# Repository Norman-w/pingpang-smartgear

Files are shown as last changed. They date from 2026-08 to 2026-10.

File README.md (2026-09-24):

# 乒乓智配 · PingPang SmartGear

乒乓球训练与比赛相关的智能辅助装备、配件及识别系统。

## 裸激光可调夹座首样

新增左侧十路裸激光方案：每颗光头装入独立球面夹筒，以两颗斜向螺钉微调，整排沿用原球头粗调。调整时从头套编号孔进入，邻近光头和盖件保持安装；预览页提供[原位调节演示与夹座特写](hardware/cad/preview/?view=laser)。尺寸暂按 Ø6×12 mm，实体适配和光路精度待实测。

设计、装配和独立 STL 包见[小夹座说明](docs/laser-micro-mount-v0.1.zh-CN.md)。前盖已加深、加宽并恢复完整弧形侧壁；新前后盖、承载条、底盖及底部柔性垫配套使用。预览支持围绕鼠标缩放和各倍率下平移。下文原 M6 电子与打印资料保留作参考，不表示其电路已经适配裸激光。

[接收端配套外壳](docs/receiver-mount-v0.1.zh-CN.md)也已同步扩大，提供独立五件打印包和右侧特写；内部接收元件选择尚未确认。

## 当前项目

当前机械主线是一套免打孔的内置式球网支架：左右夹体固定在球台边缘，网布直接装入两侧立柱，网端附近各有一个 PVDF 振动传感器；左右各十路 M6 发射/接收器件用于过网高度/事件采集，电子系统由 ESP32-S3 主控和独立 M6 接收载板组成。

当前阶段已经完成：

- OpenSCAD 统一机械参数源、完整装配、爆炸和真实截面诊断；
- C 形夹按 y=0 分型为两半；承载发射/接收头的斜立柱另分为下段和顶部 `30 mm` 上段，分型处用公母定位键和四枚 M3×40 连接；网布侧边使用独立圆柱插杆，不再使用外侧矩形网夹；立柱从黄灰交界 `z=16 mm` 延伸至 `z=260.5 mm`，不向下插入 C 形座；网布/圆柱插杆功能区仍为 `z=16…168.5 mm`；
- 网布的 `3 mm` 过道，以及球网空心边套和 `Ø10 mm` 圆柱插杆；插杆先穿过网布边套，再沿原门洞轴线从 x 侧推入下段侧开接收腔，门洞宽度保持历史 `15.2 mm`，立柱分型位于顶部下 `30 mm`，网顶不设置轨道；
- ESP32 主控、电池、电源保护、接收/发射/UI 子板的 KiCad/Atopile 交接包；
- 板框、安装孔、梯形腔、y+ 一体式 UI 填平固定板和电子件的统一 fit report；
- 当前 `41` 个正式机械 STL，以及 `256 mm` 打印床 `7` 张板、`41` 件、`0` 件超尺寸的几何拼盘；斜立柱下段/绿色载体采用实际三轴斜放，上段按平放姿态打印。

仍未由文件替代的工作包括：PCB 铜箔/器件生产释放和电气波形、真实网布与 M6 SKU 实测、立柱与 C 夹的打印配合及 PETG 承力、盒盖实际贴合、切片/G-code、首层和实物装配联调。

网端安装规则：先把球网侧边空心布套套到一根 `Ø10 mm × 152.5 mm` 圆柱插杆上，再沿原门洞轴线从 x 侧推入下段侧开接收腔，最后安装上段把插杆封在立柱内；拆卸按相反顺序进行。固定 C 夹两半除网布过道外保持实心，立柱底面与 `z=16 mm` 黄灰交界共面，分型在顶部下 `30 mm`，上段与下段用公母键和四枚 M3×40 连接；下段从承托面起做 `35×58 mm → 28×38 mm` 连续实心渐变，以上保持 `28×38 mm`。

这里的“齐平”仅表示一体式 UI 填平固定板和 M6 盖件装配后没有明显错台或松动，不宣称 IP 防水等级。

## 仓库结构

```text
docs/       需求、技术方案、测量定义和测试记录
hardware/   机械 CAD、电子板、BOM、打印和装配资料
firmware/   设备控制器、传感器采集和通信固件
vision/     球体检测、轨迹估计、过网高度计算
software/   标定工具、调试界面和训练/比赛数据接口
```

## 入口文档

- [硬件工程说明](hardware/README.md)
- [OpenSCAD 机械主线](hardware/cad/README.md)
- [打印清单](hardware/cad/print-manifest.zh-CN.md)
- [ESP32 主控与 1S 电源首样板](hardware/electronics/esp32-control-v0.1/README.zh-CN.md)
- [统一电子系统干涉/打印自证报告](hardware/electronics/fit-report-v0.2.md)
- [Atopile 系统接口合同](hardware/electronics/atopile/README.zh-CN.md)
- [系统机械—电气接口合同](hardware/electronics/system-packaging-v0.2.zh-CN.md)
- [M6 阵列设计说明](docs/m6-optical-array-design-v0.1.zh-CN.md)
- [首样采购与装配清单](hardware/first-article-bom.zh-CN.md)

## 设计原则

1. 先建立可测量、可追溯的机械和高度基准。
2. 机械、电子和识别链路分层，任何一层未实测时保持 `pending/unknown`。
3. 以装配、干涉、通道数量和实物波形共同放行，不以“能编译”代替接板通过。
4. 所有打印包必须能追溯到参数源、清单、包围盒和封闭拓扑摘要。

本项目当前面向训练、实验和产品研发；未经重复性、环境适应性和规则符合性验证的版本，不作为正式比赛裁判依据。

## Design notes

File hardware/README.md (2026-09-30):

# 硬件工程

这里放置内置式球网支架、两侧 M6 发射/接收阵列、网端 PVDF 传感器、ESP32 主控、子板、电池和装配资料。

新增的左侧裸激光可调小夹座见[结构与装配说明](../docs/laser-micro-mount-v0.1.zh-CN.md)。单颗特写、原位调节演示与整排共用 SCAD 导出的模型，工具从编号孔进入，邻居和后盖保持固定。输出位于 `cad/exports/laser-micro-mount-v0.1/`；加大前腔的新前盖、新承载条、后盖、底盖与底部柔性垫成套使用，原 M6 电气资料仅供接口参考。

右侧也已同步[接收端外壳](../docs/receiver-mount-v0.1.zh-CN.md)，输出为 `cad/exports/receiver-mount-v0.1/`；内部元件仍为原M6接口参考，待确认接收器后适配固定座。

## 当前硬件拆分

- [`cad/`](cad/)：参数化 OpenSCAD 机械源、完整装配/爆炸/剖切预览、正式 STL 导出和 256 mm 打印拼盘；
- [`electronics/`](electronics/)：ESP32-S3 主控板、M6 接收载板、发射端内置电源子板、UI 子板、Atopile 接口合同、3D 板模型和统一壳内干涉报告；
- [`first-article-bom.zh-CN.md`](first-article-bom.zh-CN.md)：首样采购和实物放行边界；
- [`../docs/m6-optical-array-design-v0.1.zh-CN.md`](../docs/m6-optical-array-design-v0.1.zh-CN.md)：M6 阵列和安装基准。

电子系统的机械—电气合同见 [`electronics/system-packaging-v0.2.zh-CN.md`](electronics/system-packaging-v0.2.zh-CN.md)。其中已给出母板、接收/发射/UI 子板、端子化线束、电池仓、USB-C、按钮、屏幕预留、扬声器/蜂鸣器、指示灯和梯形腔的统一坐标。主控与 1S 电源首样板见 [`electronics/esp32-control-v0.1/`](electronics/esp32-control-v0.1/)，M6 接收载板和发射端电源子板见 [`electronics/daughter-boards-v0.2/`](electronics/daughter-boards-v0.2/)。

## 当前机械结构

网顶不设置轨道。网布侧边空心布套先套到 `Ø10 mm × 152.5 mm` 圆柱插杆，再把这套组件从球台中心侧穿过立柱下段的连续 `3 mm` 网布过道，沿原门洞轴线从 x 侧推入下段的侧开接收腔；安装上段后封住插入口。斜立柱在顶部下 `30 mm` 分成下段和可替换上段，两段用公母定位键和四枚 M3×40 自攻钉连接。网端附近左右各一个 PVDF 振动传感器，与网架保留 `18 mm` 横向净距。

C 形夹按 y=0 分型为 `clamp_body_half_user` 与 `clamp_body_half_opponent` 两半，斜立柱和绿色载体则由 `post_clamp_carrier_lower`、`post_clamp_carrier_upper` 两件打印；固定夹半体除网布 `3 mm` 过道和侧开接收腔外保持实心。立柱底面在 C 夹黄灰交界 `z=16 mm` 共面，分型位于顶部下 `30 mm`，上段带公母键、四枚 M3×40 连接孔和中心 M8×1.25 攻丝座；网布/圆柱插杆功能区仍只到 `z=168.5 mm`。网端装配不使用矩形卡夹、keeper 或竖直盲孔：先把边套套在 Ø10 圆柱上，再沿 x 方向推入下段侧开接收腔，最后合上上段。球头下端直接拧入上段中心座，四枚立柱连接螺丝只属于立柱上下段。

盒盖、压合边和接口以“装配后严丝合缝、无明显贯穿缝”为目标；这里不宣称防水等级。真实网布、螺纹、张力、线缆弯曲和夹体耐久必须用首样实测。

## 打印状态

当前正式机械包以 [`cad/print-manifest.zh-CN.md`](cad/print-manifest.zh-CN.md) 和 [`cad/exports/desktop-clamp-one-side-x1c-v0.7-split-c-scheme/manifest.json`](cad/exports/desktop-clamp-one-side-x1c-v0.7-split-c-scheme/manifest.json) 为准：`41` 个 STL。256 mm 打印床拼盘见 [`cad/exports/desktop-clamp-one-side-x1c-v0.7-split-c-scheme/print-platter-256/manifest.json`](cad/exports/desktop-clamp-one-side-x1c-v0.7-split-c-scheme/print-platter-256/manifest.json)：`7` 张板、`41` 个已排版、`0` 个超尺寸件；斜立柱下段/绿色载体使用实际三轴斜放，上段按分型面平放姿态打印。旧整高 C 夹、电子腔底盖/连续垫、网夹分体、套筒和内芯不再属于当前清单；旧矩形卡条与 keeper 已移除，当前为独立 Ø10 mm 圆柱插杆和下段侧开接收腔。

立柱上下段连接螺丝当前按普通盘头或低矮圆头 `M3×40` 自攻钉采购；结构没有 90° 沉头窝，也不使用台阶肩螺丝。这是 CAD 包络/封闭 STL/排版证据，不是已切片、已生成 G-code 或已完成实物打印的证明。

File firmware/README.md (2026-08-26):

# 固件工程

这是 ESP32-S3 的业务固件骨架，专注于网顶擦网与过网高度事件，不在本仓库复制外部 SmartPaddle/目标 App 的配网、连接管理和多设备基础设施。

## 业务链路

```text
10 路 M6 NPN 光电 GPIO/中断 ─┐
                    ├─ NetEventAggregator ── NetEvent v0.1 ── WebSocket 适配点
2 路 PVDF comparator ─┘          │
                                 ├─ RGB/蜂鸣器适配点
                                 └─ RAM RingBuffer 断链缓存
```

`piezo_waveform.*` 保存每路 16 kHz、20 ms 预触发和 80 ms 后触发的双通道短波形，并在波形完成后计算峰值、能量和持续时间；ADC 流超时或冷启动时预触发历史不足会释放/保留相应帧，但让事件带 `waveform_incomplete`，不把零填充历史当作有效基线；主循环先消费比较器边沿再派发 ADC DMA，时间戳早于触发点的 backlog 样本会回填当前帧的预触发尾部；空引用不会启动可回放帧，乱序帧入队后会清空滚动历史，防止坏样本污染下一事件；GPIO 队列溢出等输入边界失败调用 `abort()` 时，当前帧和尚未交给业务层的 ready 帧都会丢弃，避免跨边界波形被归档。`piezo_waveform_archive.*` 保留最近若干帧，`waveform_ref` 不再是无目标的占位字符串。`piezo_adc_continuous.*` 已提供 ADC1 continuous/DMA 适配，并保留与目标 SmartPaddle/ESP-IDF 5.5.x 原始结果格式的适配边界，同时兼容 ESP-IDF 6.x 的解析接口；配置会拒绝重复 ADC 通道、无效帧大小和超过读取缓冲区的帧；目标 PCB 的最终引脚表和 AFE 输出范围仍需实机确认。

## 构建与测试

- ESP32-S3：在 ESP-IDF 环境中从 `firmware/` 运行 `idf.py build`；
- 主机业务测试：运行 `python3 host-tests/run_tests.py`；
- 主机测试依赖：在 `firmware/` 下运行 `python3 -m pip install -r host-tests/requirements.txt`；GitHub Actions 会自动执行主机、CTest、Python/Schema、预览、OpenSCAD 和 ESP32-S3/ESP-IDF 5.5.1 验证；
- `m6_carrier_protocol_tests` 额外验证载板帧的 CRC/长度/分片/序号/时钟偏移/FIFO 边界、`CLOCK_SYNC_REQUEST/RESPONSE` 两事务 t2/t3、至少三次低延迟稳定样本的运行时校准门、换 offset 时清空旧边界、载板 SPI 从机 TX 预装/IRQ-CS 生命周期、短事务 fail-closed、10 路同时双边沿的 20-edge 分帧以及原始电平进入 `BeamCapture` 的适配；它不替代载板 SPI 电气波形和实物短脉冲测试；
- 主机测试覆盖光栅位图/安静结束/超时/乱序/反向时间边界保护、PVDF 双通道归并、完整与不完整波形特征/归档/非有限值保护、窗口外 DMA backlog 丢弃、比较器先到后由 DMA 完成波形并归并为 `touch_over` 的顺序路径、输入边界失败时清空 ready 波形、传感器健康快照质量门、健康快照在待决事件期间变化时的 fail-closed 处理、聚合器对空校准 ID/越界健康位图和坏边界的 fail-closed 处理、GPIO 队列溢出、四种事件状态、端到端传感器归并、完整事件进入断链 RAM 缓存并恢复补发、传输恢复、JSON Schema 和 CSV 轨迹回放；ESP32 任务侧在队列溢出后会清空旧边沿，再等待新输入建立边界。

参考平级 checkout `../SmartPaddle` 的 `firmware/main/ws_data_server.h` 提供 `ws_data_has_client()` / `ws_data_send_text()`；`smartpaddle_ws_transport_adapter.cpp` 在定义 `SMARTGEAR_SMARTPADDLE_WS`、加入 SmartPaddle 的 include path 并链接其完整网络 component 后提供两个强 hook，默认构建仍保留弱 hook，因此不会把未链接的网络服务误报成已连接。这个适配器只完成代码边界，不代表两个工程已经合并或实机联调。

针对 SmartPaddle GPIO 冲突，`m6_carrier_protocol.*`、`m6_carrier_adapter.*` 和 `m6_carrier_spi.*` 已在 host 测试及现有 ESP-IDF v5.5.1 配置的 CMake build 中通过载板帧解码、ESP32-S3 SPI master/IRQ 读取、运行时四时间戳校准门和 `BeamCapture` 边界适配验证；`sensor_board_hooks.*` 的 `smartgear_board_read_m6_carrier_clock_sync()` 是板级同步事务注入口；`carrier/m6_carrier_capture_core.*` 与 `carrier/m6_carrier_spi_slave_transport.*` 提供 MCU 无关的载板 FIFO、TX 预装和 IRQ/CS 事务边界。`carrier_config::kUseM6Carrier` 默认关闭；载板 MCU 固件、PCB/光耦实物、实机时钟同步和 SPI/IRQ 波形仍需接板放行，未确认时主循环会清空边界并保持 `unknown`，不会伪造有效高度事件。

`carrier/esp32s3-reference/` 是一个独立的 ESP32-S3 载板平台参考工程，可在 ESP-IDF 5.5.1 下编译验证 10 路 GPIO ISR、SPI slave DMA、IRQ/RESET 和协议核心；它不等于最终生产 MCU 或 PCB。

`sensor_board_hooks.h` 的健康快照 hook 用于注入校准 ID、10 路光栅健康位图和 PVDF 安静基线，`sensor_health_gate.*` 负责把同一份快照以可测试的 fail-closed 规则写入聚合器；在 M6 SKU、NPN 常开/常闭极性、隔离前端和逐路自检未确认前，`net_sensor_config.h` 的 `kBeamPolarityConfirmed=false` 还会在主循环入口拒绝健康快照；`piezo_waveform_hook.h` 可把完整/不完整原始帧同步复制到目标回放存储。健康 hook 未实现、返回失败或快照形状非法时固件保持 `unknown`，不生成未经验证的有效事件；波形 hook 未实现时仍保留本地 RAM 归档。

载板工程候选的无 HAL 端口外壳见 [`carrier/stm32g031-reference/`](carrier/stm32g031-reference/)。它验证 `STM32G031K8U6/UFQFPN32` pin map、EXTI → 1 µs 定时器、SPI1 mode 0/152-byte TX staging、IRQ/CS 和复位生命周期；目录提供依赖 ST 官方 CMSIS device/core 与 ARM 工具链的寄存器级 object compile-only 绑定，以及可选的最小 STM32G031 参考 ELF/bin 构建。参考镜像已在本机链接并导出，但真实 PCB、DMA/ISR 波形、CS glue、烧录上电和接板验收仍保持 pending。

硬件 GPIO 映射在 `main/net_sensor_config.h` 中明确标为首轮占位，不能在最终 PCB 未复核前视为量产引脚表。`kBeamLogicalIndexByInput` 把原始 GPIO bit 映射到逻辑高度；默认是 identity，实物通道表确认非直序后必须同步更新并重新构建。健康快照使用映射后的逻辑位图。

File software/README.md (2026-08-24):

# 软件与数据工具

这里放置 `NetEvent v0.1` 查看器、光栅/压电记录导出、标定记录和与训练/比赛相关系统的适配层。

首版业务数据来自 ESP32-S3 的光栅位图、离散高度区间、PVDF 质量信息和时间戳。外部视频仅作为可选回放证据，不是本设备的实时识别链路。

T-03 的时间戳关联工具见 [`../docs/timestamp-correlation-v0.1.zh-CN.md`](../docs/timestamp-correlation-v0.1.zh-CN.md) 和 [`../tools/correlate_net_events.py`](../tools/correlate_net_events.py)。它只根据现场记录提供的外部时间戳、明确偏移和时间窗生成关联结果，不读取或解释视频画面。

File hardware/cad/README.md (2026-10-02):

# OpenSCAD 机械主线

当前机械源文件是 [`net_stand.scad`](net_stand.scad)。它把球网、两侧立柱、桌下夹体、PVDF 传感器安装位、M6 光学壳体以及电子腔体放在同一套参数坐标中，用于装配干涉和打印件导出。

当前版本的边界很明确：网顶不设轨道；侧边空心布套先套到 `Ø10 mm × 152.5 mm` 圆柱插杆，再沿原门洞轴线从 x 侧推入两侧斜立柱下段的侧开接收腔，门洞横向宽度沿用历史 `15.2 mm`，从顶部下 `30 mm` 分型面装上上段封住插入口。斜立柱在顶部下 `30 mm` 分为下段和上段，公母定位键及四枚 `M3×40` 自攻钉只连接这两个立柱打印件；不再使用外侧矩形 U 夹。网端附近左右各一个 PVDF 振动传感器，传感器与网架保留 `18 mm` 横向净距。

本轮依据的 SketchUp 草图只作为形状关系参考，不作为实际尺寸源：左侧是固定灰色 C 形夹主体，右侧是斜立柱和绿色整体底座。当前正式接口采用 `779f046` 中的 C 方案：灰色 C 夹外侧切出让位腔，绿色底座沿 x 方向推入，黄色立柱在 `z=16 mm` 与绿色底座相接；底座保留两枚 `Ø4 mm` 通孔、中央 `Ø6×2 mm` 底坑和两侧 `15 mm` 外伸。立柱在 `z=230.5 mm` 分型，顶部 `30 mm` 上段继续到 `z=260.5 mm`，网布/圆柱插杆功能区仍只到 `z=168.5 mm`。正式尺寸仍以本文件的首样参数和验证约束为准。

夹体现在采用沿 `y=0` 分型的两半打印，斜立柱和绿色底座按上下分段：`clamp_body_half_user` 是操作者侧 y- 半体，`clamp_body_half_opponent` 是对手侧 y+ 半体，黄绿连接件的下段为 `post_clamp_carrier_lower`，顶部 30 mm 为 `post_clamp_carrier_upper`。两半用 9 套横向 M5 螺钉连接；两侧 y=0 分型内侧浅凹槽底对应阳刻相同的 `1…9` 编号，字顶低于分型基准，不落到外表面也不干涉合拢；左下角连接孔向外侧移动，电子仓左下角和右下斜加强边沿各有一个连接点，其中 6、7 号连接点及其 boss/孔位整体沿 Z− 下移 `9 mm`，前半圆头沉孔朝外，后半六角螺母窝朝外。只有贴着电子仓空腔面的连接点增加 boss 柱和十字肋，实心夹臂里的连接点只保留通孔/沉孔，避免外壳凸起。电子腔从分型面打开后可装板、走线。y+ 侧壁开出 `64×34 mm` 窗口。UI 结构现在是一个一体式打印件：外轮廓 `62.8×32.8 mm` 的齐平填平板、腔内阶梯式固定法兰、窗口捕获环和 8 个通孔在同一 STL 中融合；它从腔内 y- 侧推入，外表面与 C 夹壁齐平且不打螺钉孔，也没有隐藏 boss 收纳槽。腔内固定法兰位于 y=`17.5..20.0 mm`，窗口内捕获环延伸到 y=`25.5 mm` 并向面板周边压入 `0.4 mm`，整体外轮廓为 `72×42 mm`；8 个 `Ø2.3 mm` 通孔从腔内装入 `2 mm` 蘑菇头自攻钉，直接锁入 C 夹实心内壁 `Ø1.6 mm` 盲导孔；孔中心相对旧 M3 方案整体向外移 1.0 mm，孔边仍保留至少 `1.2 mm` 实体边，外壁底厚保留 `0.7 mm`，不生成正向 UI boss 柱。按键用封口板内侧导向柱，LED 的直孔可装透明导光柱，Type-C 直接走通槽，屏幕和扬声器留在腔内。安装时仍把绿色底座从 C 夹 x+ 开放端推入让位腔，两个 M4 螺钉穿过灰色 `Ø4.4 mm` 孔和绿色 `Ø4 mm` 孔，底部钢珠进入 `Ø6×2 mm` 浅坑定位。黄色立柱下段在 `z=16 mm` 与绿色底座相接并延伸到分型面 `z=230.5 mm`，顶部 30 mm 上段延伸到 `z=260.5 mm`，四枚 `M3×40` 连接上下段；网布/圆柱插杆功能区仍只到 `z=168.5 mm`。这里没有 T 槽、公轨、第二个滑靴或旧的直接共面座；分型总间隙 `0.20 mm` 是打印装配余量，不是强度或防水承诺。
电子腔本体采用“右侧桥体大面积内缩、内部形成整段电子仓”的真实负空间：全腔约 `117×40 mm`，两侧保留 `9 mm` 承力壁，上方保留约 `15.5 mm` 上部承力层，底部保留一体化 `4 mm` 斜底；两半分开后从 `y=0` 分型面装入 PCB/电池，主控板的 Edge.Cuts 轮廓先相减出板形让位，再由 x− 端 `[` 与 x+ 端 `]` 两件端部 C 形夹件承托和防上浮，端部整条竖根留在实心端墙内，不使用底部 standoff、PCB boss 或伸入腔体的主板螺钉。电池放在主控板器件层上方的第二层托位，避免夹件压穿电池，`x+` 外侧墙和 M5 boss 保持完整。主机唯一外部充电口是 y+ UI 面板上的 KiCad Type-C；J3 传感器电源和 J_EXT 发射后备输入都留在各自板/腔内，不在 C 夹外壳上再开第二个充电口。正式 STL 不包含外购螺钉；正式打印包包含左右各一件从腔内装入的一体式 y+ UI 填平固定板（面板、腔内法兰、捕获环和 8 个孔融合为一件），当前源文件不再定义旧的电子腔底盖或连续垫。`net-stand-clamp-split-electronics-cutaway.png` 是诊断剖视图，会把 y- 外壁打开来显示真实大腔和分型面装配路径；窗口不代表正式打印件少了 x+ 外墙或承力结构。

电池、屏幕和扬声器等不贴 PCB、通过线束连接的实体包络统一定义在 [`electronics_components.scad`](electronics_components.scad) 中，每种物件只有一个模块定义；`net_stand.scad` 只在世界坐标中挂载这些实例。按键、0603 LED 和 USB-C 属于 PCB 直装件，必须使用 KiCad 封装中的 3D 模型，并随 UI 板 STL 一起导出，SCAD 不再复制它们。`clamp_electronics_ui_component_alignment_check`、UI 面板布局断言和电子腔空交集探针会把 KiCad 板模型与 SCAD 线束件一起检查对位/干涉。网页电子腔视图若要查看 SCAD 线束实体，可导出 `PART="clamp_electronics_ui_physical_items"` 到本地 `hardware/electronics/3d/v0.2/ui-physical-items-v0.2.stl`。

这里的“水密”只表示盒盖、压合边和接口在 CAD 中严丝合缝、没有明显贯穿缝；不宣称 IP 等级，也不替代实物淋水/装配检查。

## 当前源模型入口

常用 `PART`：

- `assembly`：完整球台截面、网布、两侧立柱/夹体、无网顶轨道的网端圆柱插杆、PVDF、左右十路 M6 发射/接收器件、M6 分体壳、球头和电子腔体装配预览；
- `left_stand` / `right_stand`：单侧装配预览；
- `post_clamp_carrier`：两段斜立柱与绿色整体底座的装配预览，不直接作为一件打印；正式打印件为 `post_clamp_carrier_lower` 和 `post_clamp_carrier_upper`。下段沿 x 方向进入灰色 C 夹让位腔，含两枚 `Ø4 mm` 孔、`Ø6×2 mm` 底坑、网布门洞和原位置侧开圆柱接收腔；上段为顶部下 `30 mm` 的可替换件，带公母键、四枚 `Ø3.4 mm` M3 通孔和中心 `Ø6.8 mm` 攻丝底孔，供球头下端 M8×1.25 直接拧入；
- `post_clamp_seated`：绿色底座推进到底、黄色立柱坐在其 `z=16 mm` 接口上的装配证据；
- `post_clamp_seated_fit_section`：沿 C 方案底座和中央定位坑截取的坐定剖面，直接查看灰色让位腔、绿色底座、黄色渐变和钢珠定位的关系；
- `post_clamp_carrier_lower` / `post_clamp_carrier_upper`：正式打印的下段/上段；`post_segment` / `lower_stand_segment` / `upper_stand_segment` 是兼容诊断入口，不替代这两个正式 STL；
- `clamp_body_half_user` / `clamp_body_half_opponent`：沿 `y=0` 分型的操作者侧/对手侧 C 形夹半体；每半含整段大面积电子仓、完整 x+ 外侧 C 壁、绿色底座让位腔的一半、9 个横向 M5 连接点（只有碰到电子仓空腔面的点加 printed boss/rib，其余只保留通孔和沉孔）、前侧圆头沉孔或后侧防转六角螺母窝；两侧 y=0 分型内侧浅凹槽底对应阳刻相同的 `1…9` 装配编号，字顶低于分型基准；左下角连接孔向外侧移动，电子仓左下角和右下斜加强边沿各增加一个连接点；两半合拢后仍保留两枚 `Ø4.4 mm` C 方案连接孔和中央钢珠定位孔；
- `clamp_body_split_fit` / `clamp_body_split_exploded`：分型合拢和拆开的预览入口，不是打印件；
- 旧的电子腔底盖、连续垫和 UI boss 兼容入口已从当前源文件移除；左右各一件一体式 y+ 外侧齐平 UI 填平固定板是正式打印件。该一体件带屏幕窗、按键浅凹面/1.6 mm 内侧导向柱、0603 LED 直孔、扬声器窗和由当前 KiCad USB-C 外壳/屏蔽件尺寸生成的 0.25 mm 装配通道（排除侧面焊接脚）；外表面再做一个到达 KiCad 金属外壳前沿的圆角碗槽，外围保留 `0.60 mm` 连续环形打印底，中心 KiCad-fit 通孔贯穿并由 Type-C 金属壳体负责显示/插入，不再使用固定 1.25 mm 浅碗；没有隐藏 boss 收纳槽，外侧不打螺钉孔；腔内固定法兰位于 y=`17.5..20.0 mm`，窗口内捕获环到 y=`25.5 mm` 并与面板周边融合 `0.4 mm`，固定板外延加宽到 `72×42 mm`，带 8 个 `Ø2.3 mm` 通孔，从腔内装入 2 mm 蘑菇头自攻钉并直接进入 C 夹内壁 `Ø1.6 mm` 盲导孔；孔中心相对旧 M3 方案向外移 1.0 mm，孔边至少保留 `1.2 mm` 实体边，不使用正向 boss 柱。一体件从电子腔 y- 侧穿入并与外壁齐平；分开两半后从 y=0 分型面装入电子件，底部使用一体化斜底；
- `m6_detector_body` / `m6_detector_shell_front` / `m6_detector_shell_rear` / `m6_detector_bottom_cover`：M6 光学壳体四件；
- `net_clamp_rod`：正式打印的一根 `Ø10 mm × 152.5 mm` 圆柱插杆；导出 STL 时圆柱轴线沿 X 平放，装配时轴线保持竖直 Z，连同球网空心边套沿原门洞方向从 x 侧推入立柱下段侧开接收腔；不再有矩形卡条、U 夹或 keeper；
- `sensor_mount_body` / `sensor_clamp_lip` / `pvdf_film`：网端 PVDF 安装件；
- `clamp_pressure_pad` / `clamp_screw` / `clamp_knob` / `calibration_gauge`：桌下夹持和标定件；
- `clamp_slide_fit_probe` / `clamp_slide_exploded` / `clamp_slide_fit_section`：历史命名下的 C 方案让位腔、推进和定位诊断入口，不是独立滑轨打印件；
- `clamp_electronics_ui_physical_items` / `clamp_electronics_ui_component_alignment_check`：SCAD 线束实体件（屏幕/扬声器）装配和世界坐标/包络检查；PCB 按键、LED、USB-C 由 KiCad 板 STL 提供，不是独立打印件；
- `net_clamp_fit_probe` / `net_clamp_fit_section`：网布 3 mm 过道、半透明空心边套、Ø10 mm 圆柱插杆和原位置侧开接收腔的真实截面证据；
- `table_clamp_section` / `parameter_probe`：剖面和验证脚本参数探针，不是打印件。

`net_rail*`、`post_joint_sleeve`、`post_joint_key` 等名称只保留为历史/兼容诊断入口，不属于当前装配或打印清单；当前网端件是 `net_clamp_rod`。

## 导出和验证

正式打印导出只使用同一份 SCAD 参数源：

```text
python3 export_net_stand_printables.py --clean
python3 test_export_net_stand_printables.py
python3 build_print_platter.py --preset x1c-256 --clean
python3 test_build_print_platter.py --default
python3 validate_net_stand.py
```

正式包的当前结果是 `41` 个 STL，包含左右 y+ 外侧齐平 UI 填平固定板、一根圆柱插杆、斜立柱下段/顶部 30 mm 上段，以及 12 mm 大径/4 mm 螺距、2 mm 牙根与 2 mm 凹槽、0.4 mm 锥尖的 PETG 锥形粗牙螺杆、固定螺母和旋钮对锁螺母；牙根采用连续实体带，适合 FDM 扭矩，不再是细线牙或平顶环带。圆柱插杆包络约 `10×10×152.5 mm`，立柱下段和上段分别按各自姿态导出。`--clean` 会清除旧版网夹上下段、旧整件 C 夹、外挂套筒和内芯，避免历史文件静默混入。默认输出目录是 [`exports/desktop-clamp-one-side-x1c-v0.7-split-c-scheme/`](exports/desktop-clamp-one-side-x1c-v0.7-split-c-scheme/)，每个 STL 的来源、左右侧、材料、包围盒和封闭拓扑摘要记录在其中的 `manifest.json`。

分型后的两个 C 夹半体、斜立柱下段/上段、一体式 y+ 外侧齐平填平固定板和圆柱插杆是不同打印对象：`clamp_body_half_user`、`clamp_body_half_opponent`、`post_clamp_carrier_lower`、`post_clamp_carrier_upper`、`clamp_electronics_ui_panel_mount`、`net_clamp_rod`。旧的网夹上下段目录已作废，不能把旧文件混入当前包。需要直接换打接口时运行 `python3 build_net_clamp_bambu_package.py --side both`，使用 `exports/desktop-clamp-one-side-x1c-v0.7-split-c-scheme-3mf/` 下左右两个可编辑 X1C/PETG 3MF；每个文件包含前后两个夹体半件、立柱下段、立柱上段、一体式 y+ 外侧填平固定板和圆柱插杆六个对象。

256 mm 打印床的几何拼盘结果记录在 [`exports/desktop-clamp-one-side-x1c-v0.7-split-c-scheme/print-platter-256/manifest.json`](exports/desktop-clamp-one-side-x1c-v0.7-split-c-scheme/print-platter-256/manifest.json)：当前脚本目标为 `7` 张板、`41` 个已排零件、`0` 个超床件。左右两件下段黄绿连接件采用 `rx=0°、ry=51°、rz=45°` 三轴刚体斜放，顶部上段按分型面平放；两个 C 夹半体把各自 y 外侧大平面贴床，端部 `[ / ]` 夹件沿 y 方向逐层生成，一体式 圆柱网杆平放。这个结果只证明保守包络排版和 STL 几何，不等于已经切片、配置支撑、生成 G-code 或完成实物打印。

建议在导出后对全部 STL 做封闭拓扑复核：

```text
for stl in exports/desktop-clamp-one-side-x1c-v0.7-split-c-scheme/*.stl; do
  python3 /Users/norman/.codex/skills/openscad-stl-print/scripts/inspect_stl.py --require-watertight "$stl" >/dev/null || exit 1
done
```

## 预览和人工检查

```text
python3 render_net_stand_preview.py
python3 test_preview_consistency.py
python3 build_assembly_preview.py
python3 -m http.server 8000
```

浏览器装配页位于 [`preview/index.html`](preview/index.html)，可以切换装配、爆炸、打印拼盘和零件清单；真实打印件按 manifest 加载，电子腔专页加载包含 PCB 直装按键/LED/USB-C 模型的 KiCad 板级 STL，并把屏幕/扬声器等 SCAD 线束实体作为装配件检查。通用模板版位于 [`preview/assembly/`](preview/assembly/)，生成后直接打开 `http://localhost:8000/preview/assembly/`。它使用 `scad-assembly-web-preview` 的 manifest/frame/group/instance/stage 引擎，提供装配树、分组筛选、单件显隐、XYZ 标准轴、预设视角、维护阶段和爆炸播放；`build_assembly_preview.py` 会从当前正式打印件 manifest 读取 STL，把源几何局部化并去重后写入被 gitignore 的 `preview/assembly/models/`。模板 manifest 还把 `net_stand.scad` 的球台台面、网布和网顶高度线作为半透明诊断参考件加入总装配，并用 frame 父子关系表达“球台 → C 夹 → 立柱 → M6 端”和“C 夹内壁 → UI/电子腔 → KiCad 板/屏幕/导光柱”的挂载链；这些环境参考件不属于打印清单，选中实例时左侧详情会显示挂载接口和父 frame。

模板版是当前正式 SCAD/STL 的可视化装配入口，维护阶段是用于检查装配关系的视觉位移，不代表动力学、强度、防水或实物干涉已经验收。正式 STL 清单缺失时先运行 `python3 export_net_stand_printables.py --clean`，再运行 `python3 build_assembly_preview.py`。

网页装配页现在只加载正式 manifest 中的 C 方案夹体半件和黄绿连接件；旧候选腿脚和让位审查网格已从预览入口移除，不会再与正式模型叠加。三维工具栏的“立柱/C夹”重点视角直接查看当前正式零件，并支持 y=0 分型合拢/爆炸检查，便于检查 M5 boss、螺母窝、电子腔和底座让位腔。

- 网页爆炸视图中 `clamp_body_half_user` / `clamp_body_half_opponent` 沿 y 方向分开，`post_clamp_carrier_lower` 沿 `x+ → x−` 滑入/拉出，`post_clamp_carrier_upper` 沿 z 方向从分型面抬起；爆炸状态会把分型面、M5 boss、电子腔和立柱公母键打开，不把承座误显示成随载体移动的平台；

- [`clamp slide exploded`](rendered/net-stand-clamp-slide-exploded-right.png)：固定灰色 C 形主体与黄绿连接件的分体关系；重点检查绿色底座沿 x 方向退出/推进、两枚连接孔和中央定位坑；
- [`post/clamp seated`](rendered/net-stand-post-clamp-seated-right.png)：推进到底后的最终坐定状态，黄色立柱坐在绿色底座上，绿色底座落入灰色让位腔；
- [`post/clamp seated section`](rendered/net-stand-post-clamp-seated-fit-section-right.png)：真实 C 方案坐定界面的局部剖面，检查灰色让位腔、绿色底座、黄色 `30 mm` 渐变和中央钢珠；
- [`post/clamp entry open section`](rendered/net-stand-post-clamp-entry-open-section-right.png)：从开放装配方向查看让位腔入口和绿色底座的真实薄剖面；
- [`post/clamp slide exploded`](rendered/net-stand-post-clamp-slide-exploded-right.png)：固定夹体保持不动，黄绿连接件沿真实 x 方向拉出，用于检查两件装配关系；
- [`post/clamp slide interface exploded`](rendered/net-stand-post-clamp-slide-interface-exploded-right.png)：只截取底部连接接口，专门核对绿色整体底座、两个 `Ø4 mm` 孔、灰色 `Ø4.4 mm` 孔和中央定位坑；
- [`clamp slide section`](rendered/net-stand-clamp-slide-fit-section-right.png)：历史命名下的 C 方案 y 剖面诊断，不表示当前存在独立公母滑轨；
- [`clamp slide foot detent detail`](rendered/net-stand-clamp-slide-foot-detent-detail-right.png)：兼容诊断名，放大绿色底座和钢珠定位结构。
- [`net rod section`](rendered/net-stand-net-clamp-fit-section-right.png)：网布空心边套套在 Ø10 mm 圆柱插杆上，一起沿原门洞轴线从 x 侧进入下段侧开接收腔；半透明圆筒只表示布套包络，正式打印件只有圆柱插杆。四枚 M3×40 不属于网端件，而是属于立柱上下分型连接；
- [`assembly`](rendered/net-stand-assembly.png)：完整壳体、网布和两侧端部传感器的总干涉关系。

当前机械验证仍需实物完成：实际网布厚度与张力、内嵌止挡的脱出行程与释放手感、立柱与 C 夹的打印配合和落座稳定性、PETG 夹体耐久、盒盖装配缝、线缆弯曲半径、电子板与 boss 的真实装配、以及首层/切片后的打印结果。当前文件没有把这些未测项目写成已通过。

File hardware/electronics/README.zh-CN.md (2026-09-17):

# 电气首样入口

- [`system-packaging-v0.2.zh-CN.md`](system-packaging-v0.2.zh-CN.md)：母板、接收载板、发射端内置电源、UI 子板、端子化线束和梯形腔/盖板装配合同。
- [`esp32-control-v0.1/`](esp32-control-v0.1/)：ESP32-S3 主控、USB-C、受保护 1S 电池、电源树、PVDF ADC 辅助口和 M6 载板接口；目录内有原生 KiCad PCB、项目、主控原理图和板级 3D 导出。
- [`daughter-boards-v0.2/`](daughter-boards-v0.2/)：80×32 mm 十路接收载板、68×32 mm 发射端内置电源子板、58×28 mm UI 子板及其生成器/BOM、KiCad 项目和 3D 导出。
- [`atopile/`](atopile/)：可由 `ato validate`/`ato build` 检查的系统级 Atopile 接口合同；它记录板间连接和通道数，不冒充已完成铜箔布线的 PCB。
- [`validate_system_fit.py`](validate_system_fit.py)：用 KiCad `pcbnew` 和 OpenSCAD 参数探针检查板框、安装基准、腔体余量和 M6 竖放包络。
- [`m6-capture-carrier-v0.1.zh-CN.md`](m6-capture-carrier-v0.1.zh-CN.md)：独立 STM32G031 + 光耦十路 M6 载板接口契约与放行门；当前已有 KiCad 首样载板，最终铜箔、原理图和实物波形仍 OPEN。
- [`m6-capture-carrier-first-article-bom-v0.1.zh-CN.md`](m6-capture-carrier-first-article-bom-v0.1.zh-CN.md)：载板首样器件拓扑与外部电源边界。
- [`bring-up-v0.1.zh-CN.md`](bring-up-v0.1.zh-CN.md)：上电、光栅、PVDF 和健康快照的现场接板顺序。

主控板与 M6 载板必须分板：10–30 V NPN 黑线不能直接进入 ESP32 GPIO，电池也不能替代传感器外部电源。所有现场线束以锁扣对插、可插拔螺钉端子或压接端子交接，不留裸焊盘飞线。

这里的“水密”只代表盒盖压合后严丝合缝、无明显开缝/错台/松动；不代表 IP 等级，也不把首样文档当作防水认证。真实连接器、线径、电池和升压电流仍须在首样中冻结。

## 当前线路板尺寸原则

发射头与接收头之间的 `20 mm` 光学间距只属于 M6 光学头/机械壳体；十路线束在进入子板前先汇线，因此不把光学间距乘到 PCB 长度上。当前候选尺寸为：母板 `86×32 mm`、接收载板 `80×32 mm`、发射电源板 `68×32 mm`、UI 板 `58×28 mm`。四块板均为 2 层，按所在空腔和器件/走线可制造性取紧凑尺寸，不追求无余量的小板。

板上对插线束的候选接口统一为 `MX1.25` 节距；当前生成器使用仓库内可见的 JST-GH `1.25 mm` 锁扣模型作为外观/包络代理，准确采购厂家和料号仍需拿到实物或数据手册后冻结。原理图中的 `Conn_01xNN` 只是逻辑符号的引脚表示，不代表使用 2.54 mm 物理排针；物理 PCB 焊盘以 1.25 mm 候选为准。

## 当前可交付文件

当前已生成 4 个原生 KiCad `.kicad_pcb/.kicad_pro` 项目、ESP32 主控原生 `.kicad_sch`、板级 STL/STEP 和 Atopile `.ato` 接口合同。统一自证报告见 [`fit-report-v0.2.md`](fit-report-v0.2.md)；其中机械/装配与干涉为 `PASS`，电气生产释放仍因未布线/未实测保持 `OPEN`。`.ato` 与 KiCad 的职责刻意分开，避免把接口合同误当作 Gerber 生产数据。

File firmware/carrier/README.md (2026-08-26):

# M6 载板采集核心

`m6_carrier_capture_core.*` 是与具体 MCU 无关的采集核心：

- GPIO/定时器中断调用 `on_edge(channel, level, timestamp_us)`；
- SPI 从机任务可调用 `pop_frame()` 后用 [`../main/m6_carrier_protocol.h`](../main/m6_carrier_protocol.h) 编码发送，也可调用 `pop_encoded_frame()` 直接填充至少 `152 bytes` 的 TX staging buffer；缓冲区过小会返回 0 且不消费 FIFO；
- 64 条边沿 FIFO、每帧最多 16 条；
- FIFO 溢出、非法电平/通道和时间戳倒退都通过协议 flag/丢弃计数暴露；
- 不做去抖、不要求 5 ms 最小遮挡、不延长或伪造传感器脉冲。

`m6_carrier_spi_slave_transport.*` 把 MCU 无关的 SPI 从机事务边界再收口一层：`service()` 预装完整帧，平台层随后拉低 `IRQ_N`；`begin_transaction()` 到 `end_transaction(152)` 期间 TX 缓冲不可替换；CS 提前释放会把 `timestamp_invalid` 置到下一帧。它还提供独立的 `CLOCK_SYNC_REQUEST` 接收事务和 `CLOCK_SYNC_RESPONSE` 两阶段 t2/t3 返回，不把同步字段混进事件帧。它不会假装已经实现某一颗 MCU 的 SPI/DMA 外设，平台适配只需要把 `tx_buffer()` 接到 DMA、把 `irq_asserted()` 映射到 IRQ 电平，并在 CS 边沿调用对应事务函数。

当前仓库另有一个独立的 [ESP32-S3 参考工程](esp32s3-reference/)，把上述事务接到 ESP-IDF `spi_slave` 和 10 路 GPIO ISR；它只是可编译的平台基线，不替代最终 MCU/封装/PCB 选型。

当前工程候选 `STM32G031K8U6 / UFQFPN32` 另有一个 [STM32G031 端口外壳](stm32g031-reference/)。它把候选 pin map、EXTI 输入、TIM 1 MHz、SPI1 DMA TX staging、IRQ/CS 和复位边界收成无 HAL 的接口，并由 host test 验证；同目录还提供依赖 ST CMSIS device/core 的寄存器级 compile-only 绑定，以及包含启动文件/链接脚本的可选参考 ELF/bin 构建。参考镜像可用于启动链检查，但十路 ISR 延迟、SPI/IRQ 波形、CS glue、最终 PCB 和烧录上电证据仍是现场放行项。

最小平台侧顺序：

```text
transport.service()
if transport.irq_asserted(): drive IRQ_N low
on CS low: transport.begin_transaction(); start SPI/DMA from tx_buffer()
on CS high: transport.end_transaction(transferred_bytes); drive IRQ_N high
```

当前提供可在 host/sanitizer 下验证的事件帧、同步请求/响应和 SPI 从机事务契约；ESP32-S3 主控侧的 `exchange_clock_sync()`/IRQ 读取在 `firmware/main/m6_carrier_spi.*` 已接入，ESP32-S3 参考载板和 STM32G031 参考端口也已接到同一传输状态机。具体载板 MCU 的 GPIO ISR、硬件定时器、SPI/DMA 外设、看门狗外壳和同步波形仍需在选定 MCU/PCB 后做实物放行。

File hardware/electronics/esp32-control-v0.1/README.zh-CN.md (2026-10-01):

# ESP32-S3 主控与 1S 电源首样板 v0.2

状态：`目录沿用 v0.1 入口；当前板为真实 KiCad v0.2 首样板，已附原生主控原理图和板级 3D 模型；几何 DRC 0；尚未完成铜箔布线、ERC、器件实测和量产释放`。

这是放入桌下夹体梯形腔的 ESP32-S3 主控/电源板，不把 M6 的 10 路 NPN 输入直接接到 ESP32。M6 接收器仍由独立的 STM32G031 + 光耦载板采集，主控板通过 J4 接收 3.3 V SPI/IRQ；载板输入与光耦/连接器冻结仍是下一块板的工作。

## 机械配合

| 项目 | v0.2 值 |
| --- | ---: |
| PCB 外形 | `86 × 32 mm`，2 层首样放置板 |
| 梯形腔 x 范围 | `777.5…880.3 mm`，有效长 `102.8 mm` |
| 梯形腔 y 半宽 | `20 mm`，总有效宽 `40 mm` |
| 腔体顶板 | `4 mm` |
| PCB 顶面器件预留 | `4 mm` 器件包络 + `1 mm` 装配余量 |
| 两侧承力壁 | 各 `9 mm` |
| 底盖 | `3 mm`，4 个 M3 试样孔 |
| 电池包预留 | 受保护 1S，约 `65 × 30 × 7 mm` |
| 主板安装 | 按 KiCad `Edge.Cuts` 形状相减出板形让位，x−/x+ 两端各一件打印 `[ / ]` C 形端部夹件夹持；端部竖根留在实心端墙内，4 个 `Ø2.8 mm NPTH` 仅保留在 PCB，不作为壳体 boss/定位柱 |
| 主板边缘余量 | x 向总 `16.8 mm`，y 向按实际器件包络检查；板框本体为 `86 × 32 mm` |

PCB 的 86 mm 长度和 32 mm 宽度由当前 `hardware/cad/net_stand.scad` 的参数探针约束；SCAD 现在直接导入本目录 KiCad 导出的真实板/器件 STL，不再使用无来源的蓝色板占位。橙色电池是按 `65 × 30 × 7 mm` 的受保护软包包络，实际料号仍需首样冻结。

母板不把十路现场线和所有交互器件挤在同一块板上：右侧接收端使用独立的窄长十路载板，左侧发射端使用独立电源子板（默认内置受保护 1S 电池，`J_EXT` 仅作为腔内维护/后备输入）。UI 子板承接盖面器件，其中 START/MODE 按键、状态/电量 LED 和唯一外露的 Type-C 充电口直接焊在 UI PCB 上；屏幕保留排线接口，扬声器和蜂鸣器仍通过锁扣线束连接。

## 电源拓扑

```text
UI 面板唯一外部 Type-C 充电口 VBUS
    │
    └─ J_MOTHER/J7 14 芯线束 pin13/14 ─ F1 PTC 1.1 A ─ vbus_limited ─┐
                                    │ VIN
受保护 1S 电池 J2 ─ bat_p ──────────┤ IP5305T
                                    │ 1S charger + 5 V boost
                                    └─ sys_5v ─ TPS62162 ─ 3v3 ─ ESP32-S3

J3 外部 10…30 V ─ F2 PTC ─ TVS 33 V ─ sensor_fused ─ M6 载板/传感器电源；回路返回 `sensor_gnd/0V_SENSOR`，不接 MCU `gnd`
                     （与 bat_p、sys_5v 不相连）
```

- J2 只接受带保护板的 1S 锂电池包；v0.1 不允许裸电芯直接接入。
- 电池电压经 `1 MΩ / 1 MΩ + 100 nF` 分压接 ESP32 GPIO9（`bat_sense`），这是电量估算，不是电池保护。
- IP5305T 的 LED1 经 1 kΩ 指示灯到地；KEY 由 SW1 拉低。LED2/LED3 保留为明确的 `*_nc` 测试网。
- TPS62162 按固定 3.3 V 连接，`FB` 接地，`VOS` 接 3v3；L2 为候选 `2.2 µH` 降压电感。
- M6 传感器电源从 J3 外接，不从电池升压输出偷电；NPN 黑线必须留在光耦载板侧。
- 充电口只位于 y+ UI 面板；UI 板 CC1/CC2 各由 5.1 kΩ Rd 下拉到地，D+/D−/SBU 留空，主控板没有第二个 USB 插座。

## J4 载板接口

| J4 | 信号 | ESP32-S3 GPIO | 方向 |
| ---: | --- | ---: | --- |
| 1 | `3v3` | 3V3 | 主控供电 |
| 2 | `gnd` | GND | 逻辑地 |
| 3 | `carrier_sck` | GPIO10 | 主控 → 载板 |
| 4 | `carrier_mosi` | GPIO11 | 主控 → 载板 |
| 5 | `carrier_miso` | GPIO12 | 载板 → 主控 |
| 6 | `carrier_cs_n` | GPIO13 | 主控 → 载板 |
| 7 | `carrier_irq_n` | GPIO14 | 载板 → 主控 |
| 8 | `carrier_reset_n` | GPIO5 | 主控 → 载板 |

这组接口与 [`firmware/main/m6_carrier_config.h`](../../../firmware/main/m6_carrier_config.h) 的候选映射一致；`kUseM6Carrier` 仍保持关闭，直到载板、SPI/IRQ 波形和时钟同步完成实测。

## J8 传感器电源接口

| J8 | 信号 | 说明 |
| ---: | --- | --- |
| 1 | `sensor_fused` | J3 外部 10–30 V 经 PTC/TVS 后的传感器电源 |
| 2 | `sensor_gnd` (`0V_SENSOR`) | 传感器域回路返回，直接到接收载板 J_PWR pin2；不等同 MCU `gnd` |

J8 只接接收载板的电源端，J4 只接 3.3 V 逻辑；J8 pin1/pin2 与接收载板 J_PWR pin1/pin2 按传感器域一一对应。现场线束采用锁扣式端子或可插拔螺钉/压接端子，不允许在装配状态下直接焊飞线。

## J7 UI 子板接口

| J7 | 信号 | ESP32-S3 GPIO |
| ---: | --- | ---: |
| 1 / 2 | `3v3 / gnd` | 电源 |
| 3 / 4 | `ui_sda / ui_scl` | GPIO16 / GPIO15 |
| 5 / 6 | `ui_btn_start / ui_btn_mode` | GPIO3 / GPIO4 |
| 7 | `ui_buzzer` | GPIO8 |
| 8 / 9 / 10 | `ui_spk_bclk / ui_spk_ws / ui_spk_dout` | GPIO6 / GPIO7 / GPIO17 |
| 11 / 12 | `ui_led_status / ui_led_battery` | GPIO18 / GPIO21 |
| 13 / 14 | `usb_vbus / gnd` | UI 面板 Type-C 充电电源 |

UI 子板使用 0.96 英寸 I2C OLED 排线接口、两颗 PCB 直装 3.9×3.0×2.0 mm 两脚 SMD 按键、两颗 0603 单色 LED、带声学膜的扬声器/蜂鸣器，以及一颗 16 针 USB-C 直装插座（仅 VBUS/GND/CC 使用）。`J_MOTHER` 改为 14 芯，13/14 脚把充电电源带回主控板；按键、LED 和 USB-C 的坐标直接对应 y+ 面框开口。

## 文件与重生成

- [`esp32-control-v0.1.kicad_pcb`](esp32-control-v0.1.kicad_pcb)：KiCad 10 板文件，含主控/电源/14 芯 UI 线束首样封装、4 个 M2.5 NPTH 安装孔、1 个 ESP32 天线原生禁布区、2 个覆铜区、2 个电源芯片裸焊盘地过孔；主控板没有第二个 USB 插座。
- [`esp32-control-v0.1.kicad_sch`](esp32-control-v0.1.kicad_sch)：原生 KiCad 主控/电源/M6/UI/PVDF 接口原理图；Type-C 充电入口位于 UI 子板，主板只接收 J7 的 VBUS/GND。当前 ERC 仍为首样审查结果，尚不是生产放行。
- [`../../output/pdf/esp32-control-v0.1-schematic.pdf`](../../output/pdf/esp32-control-v0.1-schematic.pdf)：由 `kicad-cli sch export pdf` 生成的原理图审查 PDF。
- [`../../3d/v0.2/`](../../3d/v0.2/)：由 KiCad `pcbnew` 导出的母板及子板 STL/STEP；壳体使用这些模型做统一坐标干涉检查。
- [`generate_board.py`](generate_board.py)：唯一板文件生成器；使用 KiCad 随附的 `pcbnew` Python API。
- [`../generate_kicad_schematic.py`](../generate_kicad_schematic.py)：原生 `.kicad_sch` 生成器。
- [`bom.csv`](bom.csv)：候选首样 BOM，器件封装/厂商料号仍需采购与实测冻结。
- [`circuit.md`](circuit.md)：人可审查的电路连接表和放行门。

```text
/Applications/KiCad/KiCad.app/Contents/Frameworks/Python.framework/Versions/3.9/bin/python3.9 \
  generate_board.py
/Applications/KiCad/KiCad.app/Contents/MacOS/kicad-cli pcb drc \
  --output /tmp/pingpang-control-drc.txt esp32-control-v0.1.kicad_pcb
```

本次 DRC 结果是“0 个几何/短路/边界违规，65 个未连接项”。65 个未连接项来自有意保留的首样气连线，不能写成 DRC 已通过，也不能直接导出 Gerber 生产。

### 子板首样

[`../daughter-boards-v0.2/`](../daughter-boards-v0.2/) 内包含：

- `m6-receiver-carrier-v0.2.kicad_pcb`：`80 × 32 mm` 集中式接收载板，十个 `MX1.25` 三芯口、一个 8 芯主控口和一个 2 芯传感器电源口；安装时长边沿 M6 壳体线缆侧竖直放置。光学头之间的 20 mm 间距不再展开到板框；
- `emitter-power-v0.2.kicad_pcb`：`68 × 32 mm` 发射端电源板，内置电池口、腔内维护用 `J_EXT` 后备输入、独立升压模块占位和 `J_TX_A/J_TX_B` 两个 10 芯十路发射线束口；
- `ui-panel-v0.2.kicad_pcb`：`58 × 28 mm` 盖面交互板，含 14 芯 `J_MOTHER` 对插、OLED 排线座、PCB 直装按钮/LED、I2S 扬声器、蜂鸣器和 16 针 USB-C 充电插座（D+/D−/SBU 不接）。

三块子板同样已经有原生 KiCad PCB/项目和实际板级 3D 导出；它们仍是首样放置/网表板，不能把未完成的升压模块、光耦或连接器选型直接当成最终可采购料号。

## 还未关闭的硬件门

1. IP5305T、TPS62162、Type-C 和 ESP32-S3 的最终厂商封装/焊盘/散热铜皮需要在 Eeschema 和目标封装库中复核；当前附带的是可打开、可检查、已参与机械包络的首样库模型。
2. 完成电源区布线后，测 USB 限流、低电量/Wi-Fi/LED 峰值电流、IP5305T/TPS62162 温升和 3.3 V 纹波。
3. 只用带保护的 1S 电池包；电池极性、连接器防呆、保险丝和外壳防磨损要在首样装配中记录。
4. 载板的光耦最终型号、`R_IN` 电流、10 路 NPN 波形、连接器和 STM32G031 PCB 仍需单独完成。
5. 底盖/安装柱的 PETG 拉脱和夹体受力测试完成后，才能冻结 PCB 固定方式和导出打印/加工包；盒盖要用连续胶条/定位唇压合，目标是装好后无明显贯通缝、错台或松动，不代表 IP 等级。
6. 用 KiCad 随附 Python 运行 `hardware/electronics/validate_system_fit.py`，需在每次改板/改壳后确认母板、发射子板、UI 子板和 M6 窄长接收板仍在各自包络内。

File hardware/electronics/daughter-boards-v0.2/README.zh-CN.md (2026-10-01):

# M6 / 发射电源 / UI 子板首样 v0.2

这些是母板之外的原生 KiCad `.kicad_pcb/.kicad_pro` 首样项目，另有 KiCad 导出的 STL/STEP。它们用于验证装配包络、端子数量和线束方向；板框和板侧连接器模型是真实文件，但尚未完成铜箔布线，因此还不是生产板。UI 的按键、0603 LED 和唯一外部 Type-C 充电器件保留 KiCad 封装及其 3D 模型，并随 UI 板 STL 导出；屏幕、扬声器和电池等线束件才由 SCAD 装配层挂载。

## 板级分工

| 文件 | 外形 | 用途 | 现场接口 |
| --- | ---: | --- | --- |
| `m6-receiver-carrier-v0.2.kicad_pcb` | `80 × 32 mm` | 右侧接收端十路光耦/采集载板占位 | `J_RX00…J_RX09` 每路三芯，`J_HOST` 8 芯，`J_PWR` 2 芯，均为 MX1.25 候选 |
| `emitter-power-v0.2.kicad_pcb` | `68 × 32 mm` | 左侧发射端内置电源与升压占位 | `J_BAT/J_EXT` 2 芯，`J_TX_A/J_TX_B` 各 10 芯，均为 MX1.25 候选 |
| `ui-panel-v0.2.kicad_pcb` | `58 × 28 mm` | 盖面交互器件和面板线束 | `J_MOTHER` 14 芯（含 VBUS/GND）、OLED 排线 4 芯、扬声器 5 芯、蜂鸣器 2 芯；START/MODE 贴片按键、2 个 0603 单色 LED、16 针 USB-C 充电口为板上真实器件 |

三块子板均有对应原生 KiCad 原理图：[`m6-receiver-carrier-v0.2.kicad_sch`](m6-receiver-carrier-v0.2.kicad_sch)、[`emitter-power-v0.2.kicad_sch`](emitter-power-v0.2.kicad_sch)、[`ui-panel-v0.2.kicad_sch`](ui-panel-v0.2.kicad_sch)，审查 PDF 在 [`../output/pdf/`](../output/pdf/)；它们把 10 路 M6、内置电池/外接后备电源、UI/按钮/屏/音频/USB-C 的接口关系画成可打开的 KiCad 文件。

接收载板安装时长边对应 M6 壳体的竖直 z 方向，当前 `80 mm` 只作为壳体内的集中式采集板尺寸，不再把十个光学头的 `20 mm` 节距展开到 PCB 上；发射板和 UI 板分别对应梯形腔与 y+ 一体式 UI 填平固定板的安装面。发射板使用电池外侧的四个边缘支撑/压片，不把 boss 穿过电池宽面；主控母板的腔体余量和所有接口分工见 [`../system-packaging-v0.2.zh-CN.md`](../system-packaging-v0.2.zh-CN.md)。

对应的板级机械模型在 [`../3d/v0.2/`](../3d/v0.2/)：`m6-receiver-carrier-v0.2.{stl,step}`、`emitter-power-v0.2.{stl,step}`、`ui-panel-v0.2.{stl,step}`。统一装入壳体后的边界、boss、过线和干涉结果见 [`../fit-report-v0.2.md`](../fit-report-v0.2.md)。

## 接线约束

- M6 接收端：每路 `V / GND / SIG` 独立三芯锁扣线，编号与 `RX00…RX09` 一一对应。
- M6 发射端：每路 `TX_V / TX_GND` 两芯锁扣线，在线束侧汇线后分成 `J_TX_A`（TX00…TX04）和 `J_TX_B`（TX05…TX09）两个 10 芯 MX1.25 候选接口；发射器默认使用子板上的内置受保护 1S 电池和独立升压/限流模块。
- M6 接收端：每路 `BN / BU / BK` 三芯线仍按 `J_RX00…J_RX09` 独立编号；线束汇聚后在紧凑接收板上插接，接收板排列不代表光学头的物理间距。
- 本目录的接口候选统一锁定为 `MX1.25` 节距；JST-GH 模型只是当前仓库可用的 1.25 mm 锁扣外观代理，准确 MX1.25 厂家/料号、线径和额定电流仍需首样冻结，不使用 2.54 mm 物理连接器。
- `J_EXT` 是发射端板上的腔内维护/后备输入，不是 C 夹外壳上的第二个充电口，不能与电池裸并联；最终反接、保险/TVS 和升压电流按实物模块冻结。
- UI 子板的母板、OLED、扬声器和蜂鸣器仍使用锁扣线束；START/MODE 使用库存 3.9×3.0×2.0 mm 两脚 SMD 按键，状态/电量使用 0603 单色 LED，Type-C 使用 KiCad 16 针库模型直接焊在 UI PCB 上，并与 y+ 一体式填平固定板开口共用坐标。UI Type-C 只接 VBUS/GND/CC，D+/D−/SBU 留空；`J_MOTHER` 的 13/14 脚把 VBUS/GND 带回主控板。面板在按键位置做浅凹面和腔内一体 1.6 mm 导向柱，直接顶到 KiCad 按键模型；LED 对准 2.2 mm 直孔；屏幕保留为排线连接的独立件，不把屏幕玻璃强行固定到 PCB，Type-C 端口配硅胶帽。按键、LED、Type-C 的机械实体只来自 KiCad 板模型；屏幕、扬声器和电池等非贴板件由 `hardware/cad/electronics_components.scad` 定义并在装配世界坐标中挂载；最终 Type-C 厂家/料号仍需首样冻结。

## 重生成与检查

在带有 KiCad `pcbnew` 的 Python 环境运行：

```text
KICAD_PYTHON=/Applications/KiCad/KiCad.app/Contents/Frameworks/Python.framework/Versions/3.9/bin/python3.9
$KICAD_PYTHON generate_daughter_boards.py
/Applications/KiCad/KiCad.app/Contents/MacOS/kicad-cli pcb drc \
  --output /tmp/pingpang-receiver-drc.txt m6-receiver-carrier-v0.2.kicad_pcb
```

原理图由上一级脚本生成并可直接在 KiCad 打开：

```text
python3 ../generate_daughter_schematics.py
```

三个板的首样目标是几何 DRC 为 0；未连接项是尚未布线的有意气连线，不等于 ERC/量产放行。每次修改板框或 `net_stand.scad` 后，回到仓库根目录运行：

```text
$KICAD_PYTHON hardware/electronics/validate_system_fit.py
```

## 面板装配边界

UI 面板不追求 IP 防水等级。“齐平”只表示一体式填平固定板从腔内装入后与 y+ 外壁贴合，不出现明显错台或松动；线缆则用锁扣端子和应力释放完成装配。实际 PETG 固定强度、电池弯折半径和连接器插拔空间仍需首样实物确认。

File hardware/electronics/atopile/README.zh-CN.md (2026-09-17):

# Atopile 系统接口合同

这里的 [`pingpang_smartgear.ato`](pingpang_smartgear.ato) 是系统级 Atopile 接口合同，明确母板、十路 M6 接收载板、发射端内置电源、UI 子板之间的可插拔信号和通道数量。

当前机械/接口候选为：母板 `86×32 mm`、接收载板 `80×32 mm`、发射电源板 `68×32 mm`、UI 板 `58×28 mm`，均为两层板；板级线束连接器物理节距统一为 MX1.25（1.25 mm）。M6 光学头的 20 mm 阵列间距只属于光学头和线束，不进入这个板间接口合同。

它与同目录上一级的原生 KiCad 文件分工如下：

- Atopile `.ato`：板间接口、端子化线束和 10 路通道数量的可验证合同；
- `../esp32-control-v0.1/` 与 `../daughter-boards-v0.2/`：实际 KiCad `.kicad_pcb/.kicad_pro` 首样板和 3D 模型；
- `../generate_kicad_schematic.py` / `../esp32-control-v0.1/esp32-control-v0.1.kicad_sch`：原生 KiCad 主控原理图；
- `../../cad/net_stand.scad`：壳体、boss、盖板、过线和板件的统一机械基准。

验证入口：

```text
ato validate hardware/electronics/atopile/pingpang_smartgear.ato
ato build hardware/electronics/atopile
```

Atopile 合同通过不等于 PCB 已完成布线、ERC/DRC 已关闭或电源/M6 波形已实测；这些状态以 [`../fit-report-v0.2.md`](../fit-report-v0.2.md) 的电气放行边界为准。

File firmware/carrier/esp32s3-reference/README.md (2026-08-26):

# ESP32-S3 载板参考工程

这是一个可编译的载板平台参考，不是最终 MCU/PCB 决策。它用第二块 ESP32-S3 演示：

- 10 路光耦后的 GPIO 双边沿 ISR + `esp_timer` 时间戳；
- ESP-IDF `spi_slave` DMA、mode 0、最大 152-byte 事务；
- IRQ/RESET 控制、事件帧 TX 生命周期和 [`../m6_carrier_spi_slave_transport.*`](../m6_carrier_spi_slave_transport.h) 的两事务时钟同步响应；
- 与 SmartPaddle 主控侧 [`../../../main/m6_carrier_spi.*`](../../../main/m6_carrier_spi.h) 的协议连接。

GPIO ISR 入口和采集核心边沿写入路径显式标记为 IRAM；最终板仍需检查 map/链接器段、实机缓存关闭场景和逻辑分析仪波形，不能仅凭本工程编译结果放行。

## 参考引脚

| 信号 | GPIO |
| --- | ---: |
| `CARRIER_IN[0..9]` | 4–13 |
| `SPI_SCK/MOSI/MISO/CS_N` | 15/16/17/18 |
| `IRQ_N` | 14 |
| `RESET_N` | 21 |

这是独立载板的候选引脚，不是 SmartPaddle ESP32-S3 主控引脚。正式板仍必须按 [`../../../hardware/electronics/m6-capture-carrier-mcu-selection-v0.1.zh-CN.md`](../../../hardware/electronics/m6-capture-carrier-mcu-selection-v0.1.zh-CN.md) 做封装、启动脚、调试口和 EMI 复核。

## 构建

在 ESP-IDF `v5.5.1` 环境中：

```text
idf.py -C firmware/carrier/esp32s3-reference build
```

本机已使用 ESP-IDF `v5.5.1` 完成正式参考构建，生成 `m6_capture_carrier_esp32s3_reference.bin`（220256 bytes）；CI 仍以 `esp-idf-ci-action@v1` 的 `v5.5.1/esp32s3` 为准。该结果只证明参考工程可编译和链接，不等于最终 MCU、PCB、SPI/IRQ 波形或传感器实物已经放行。

该工程只证明平台适配可以编译和连接；未接真实光耦、M6、SPI 线和示波器前，不能把 `carrier_integration` 改成 `pass`，也不能把此参考工程当成量产 PCB。

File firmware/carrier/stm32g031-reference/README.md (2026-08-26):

# STM32G031 载板端口外壳

这里是 `STM32G031K8U6 / UFQFPN32` 的平台适配边界，不依赖 STM32Cube 或厂商 HAL。目录同时提供两条路径：默认的寄存器级 object compile-only 检查，以及可选的最小无 HAL 参考镜像构建。后者包含启动文件、向量表、链接脚本和 freestanding 运行时补丁，可以导出 ELF/bin；它仍是“接口与启动链参考镜像”，不是已经通过首样 PCB、烧录上电和现场波形验收的量产固件。

现在另有一个可选的 [CMSIS 寄存器绑定](m6_carrier_stm32g031_register_port.cpp) 和 [CMake 入口](CMakeLists.txt)。它使用 ST 官方 `stm32g031xx.h` 的 EXTI、TIM2、SPI1、DMA1/DMAMUX1 寄存器定义，把端口外壳接到实际外设；本机已用 Homebrew `arm-none-eabi-g++ 16.2.0`、ST 官方 device header 和 ARM CMSIS-Core 做过目标架构 object compile-only 验证，并用同一套输入构建过参考 ELF/bin。参考镜像仍不会改变验收包的 `pending` 状态。

## 当前已收口的接口

`m6_carrier_stm32g031_port.*` 固化了 [候选 pin map](../../../hardware/electronics/m6-capture-carrier-stm32g031k8-pinmap-v0.1.zh-CN.md)：

- `PA1/2/3/4/5/6/7/9/10/15` → 10 路独立 EXTI 输入；
- `PB0/PB3/PB4/PB5` → SPI1 `NSS/SCK/MISO/MOSI`，mode 0；PB0 同时映射为专用 EXTI0 CS 边沿；
- `PB8` → 低有效 `IRQ_N`；`PA13/PA14` 保留 SWD；`PF2-NRST` 保留硬件复位；
- SPI 从机 TX 指针只在未进行 CS 事务时由 `service()` 更新，固定传输长度为 `152 bytes`；DMA transfer-error 与 SPI error IRQ 会把下一帧置为 `timestamp_invalid`；
- 无事件帧时 CS 事务接收 `CLOCK_SYNC_REQUEST`；载板在请求释放时记录 t2，在下一次响应 CS assertion 时记录 t3 并返回 CRC 保护的同步响应；
- CS 提前释放会把 `timestamp_invalid` 置到下一帧；复位会清空 FIFO、TX staging 和 IRQ 状态。

`PlatformHooks` 由真正的 STM32Cube LL/HAL 或寄存器代码实现。实际绑定时至少要完成：

1. GPIO 输入配置为双边沿 EXTI，并在 ISR 内读取自由运行的 `TIM2`（目标 1 µs）后调用 `on_input_edge()`；
2. SPI1 从机 mode 0 + DMA 使用 `tx_buffer()`，NSS/CS 边沿分别调用 `on_cs_asserted(timestamp_us)`/`on_cs_released()`；没有独立 CS EXTI 时可在主循环调用 `service_cs_level()`，它会用两个 DMA `CNDTR` 一致性检查计算事务字节数；无事件帧时同一入口接收时钟同步请求；
3. `configure_spi1_slave_dma()` 确认 DMA 不会在 CS 期间改写 TX buffer；
4. `drive_irq_n(true)` 代表释放高电平，`drive_irq_n(false)` 代表拉低通知主控；
5. 外部 `RESET_N` 让 MCU 重新启动，启动代码重新调用 `initialize()`，并保留复位原因/首帧日志。

寄存器绑定采用 [ST 的 STM32G0 CMSIS device header](https://raw.githubusercontent.com/STMicroelectronics/cmsis-device-g0/master/Include/stm32g031xx.h) 和 [STM32G0x1 reference manual RM0444](https://www.st.com/resource/en/reference_manual/rm0444-stm32g0x1-advanced-armbased-32bit-mcus-stmicroelectronics.pdf) 作为依据；具体时钟树、输入保护、DMA 重装和 CS 边沿仍必须按最终板卡重新审查。

## 本地验证边界

```text
cmake -S firmware/host-tests -B firmware/host-tests/build
cmake --build firmware/host-tests/build --parallel
ctest --test-dir firmware/host-tests/build --output-on-failure
```

`m6_carrier_stm32g031_port_tests` 验证 pin map、初始化顺序、TX staging、事件/时钟同步 IRQ-CS 生命周期、短事务 fail-closed 和复位行为；它不能证明 STM32 中断延迟、DMA 波形、3.3 V 电平或 PCB 已通过。真实硬件证据仍按载板 [首样接口与验收门](../../../hardware/electronics/m6-capture-carrier-v0.1.zh-CN.md) 记录，验收包继续保持 `pending`。

## 可选的寄存器 object 构建

准备与目标芯片匹配的 ST CMSIS device `Include/`、CMSIS-Core `core_cm0plus.h` 和 `arm-none-eabi` 工具链后，只编译不链接：

```text
cmake -S firmware/carrier/stm32g031-reference \
  -B firmware/carrier/stm32g031-reference/build \
  -DCMAKE_SYSTEM_NAME=Generic \
  -DCMAKE_CXX_COMPILER=arm-none-eabi-g++ \
  -DSTM32_CMSIS_DEVICE_G0_INCLUDE_DIR=/path/to/cmsis-device-g0/Include \
  -DSTM32_CMSIS_CORE_INCLUDE_DIR=/path/to/CMSIS/Core/Include
cmake --build firmware/carrier/stm32g031-reference/build --parallel
```

交叉编译时必须使用带 C++ 标准头的 ARM 工具链；`CMAKE_SYSTEM_NAME=Generic` 用来避免 macOS 主机把 `-arch arm64` 传给 `arm-none-eabi-g++`。本机这次 object 验证还使用了 `-DCMAKE_TRY_COMPILE_TARGET_TYPE=STATIC_LIBRARY`。如果工具链没有随附 C++ 标准头，可以通过 `STM32_CXX_EXTRA_INCLUDE_DIRS` 传入与目标 ABI 兼容的标准头目录。

`PB0` 的 NSS 仍由 SPI 外设使用，并由寄存器绑定映射到专用 EXTI0，因此参考镜像不依赖主循环轮询才能捕获 CS；`service_cs_level()` 仍保留给替代平台 glue。无论采用 EXTI 还是外部 glue，都必须实测 `IRQ_N → CS_N → 首字节 → CS_N release` 窗口；无参释放路径只在 RX/TX 两个 DMA 计数一致时接受长度，否则按短事务 fail-closed。DMA transfer-error 与 SPI error IRQ 已在寄存器绑定中启用，仍需板级波形证明。

## 可选的 STM32G031 参考 ELF/bin

在准备好 ST CMSIS device/core 头文件、`arm-none-eabi-g++` 和 C++ 标准头后，可以打开 `BUILD_FLASHABLE_REFERENCE`：

```text
cmake -S firmware/carrier/stm32g031-reference \
  -B /tmp/m6-stm32-reference \
  -DCMAKE_SYSTEM_NAME=Generic \
  -DCMAKE_CXX_COMPILER=arm-none-eabi-g++ \
  -DCMAKE_TRY_COMPILE_TARGET_TYPE=STATIC_LIBRARY \
  -DBUILD_FLASHABLE_REFERENCE=ON \
  -DSTM32_CMSIS_DEVICE_G0_INCLUDE_DIR=/path/to/cmsis-device-g0/Include \
  -DSTM32_CMSIS_CORE_INCLUDE_DIR=/path/to/CMSIS/Core/Include
cmake --build /tmp/m6-stm32-reference --parallel
```

构建产物为 `m6_carrier_stm32g031_reference`、`.bin` 和 `.map`。镜像包含最小向量表、`.data/.bss` 初始化、寄存器绑定主循环以及 M0+ 所需的无 libc 运行时/原子操作补丁；本地自检应继续确认 `arm-none-eabi-nm -u` 无未解析符号，并查看 `arm-none-eabi-size` 的 Flash/RAM 占用。它只证明“参考启动链可链接”，不能证明最终 PCB 的时钟、输入保护、DMA、CS/IRQ 波形或传感器边沿时序。

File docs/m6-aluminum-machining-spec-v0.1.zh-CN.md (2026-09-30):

# M6 45° L 型十路检测器 PETG 首样 / CNC 复用输入 v0.8

状态：`当前冻结主体和传感器姿态；壳体已按 x 光学端/线缆端分段完成装配候选，待主体首件和真实接口放行`。

权威几何是 [`hardware/cad/net_stand.scad`](../hardware/cad/net_stand.scad)。机器可读的尺寸、数量和源文件哈希由 [`hardware/cad/export_m6_machining_spec.py`](../hardware/cad/export_m6_machining_spec.py) 生成。

## 1. 当前结构

左右各一套，光学轴和 M6 外丝轴沿 `x`，每套 10 个通道，中心高度为球台上方 `+10…+190 mm`，节距 `20 mm`。M6 L 型器件的出光/受光面水平朝球台中心，蓝色护套/尾线局部朝 `z-`，整件绕光束轴 `x` 旋转 `-45°`；器件从各自外侧沿 `x` 穿入主体，尾线向 `y-/z-` 让开相邻器件。后侧浅六角窝只负责防止真实金属六角晃动，不把六角与外丝接驳平面埋掉；M6 外丝直接穿过主体，预览中金色螺帽表示主体外表面的一枚原配螺帽，右侧外侧为 `x+`、左侧镜像为 `x-`。

主体当前先按可打印 PETG 长条首样冻结；后续可以沿同一包络改做 CNC/金属版本：

| 项目 | 当前名义值 |
| --- | ---: |
| 中央长条基准包络（x × y × z） | `10 × 56 × 216 mm` |
| 后盖背面中央加厚 boss 包络 | `14 × 18 × 36 mm`；与 x+ 后盖在 x 方向重叠 `3 mm`，安装后全局约 `x=867…881`、`y=-9…9`、`z=234.5…270.5 mm`；左侧发射端按 x 镜像 |
| 主体全局下沿/上沿 | `z=144.5…360.5 mm` |
| 水平 M6 外丝段 | `M6×0.75`，名义长度 `14 mm` |
| 光学头到外丝末端总包络 | 名义 `20 mm` |
| 一枚原配螺帽高度占位 | `5 mm` |
| 主体允许最大厚度 | `14 + 2 − 5 − 1 = 10 mm`（含 2 mm 头部卡入） |
| 当前主体厚度余量 | `10 − 10 = 0 mm`（名义值；螺帽真实厚度和有效外丝需首件复核） |
| 水平 M6 通孔 | `Ø6.6 mm`，沿 x 贯穿，略大于外丝 |
| 尾线让位 | 蓝色护套/线缆局部 z−，随 x 轴 `-45°` 滚转后向 y−/z− |
| 后方浅六角窝 | AF `8 mm`，沿 x 深 `2.1 mm`，底部保留 `0.8 mm`；只卡住真实 AF8 六角，不埋住六角/外丝接驳平面 |
| 后盖 boss 球头孔 | `Ø7.0 mm`，沿 `x` 向 `x-` 贯入 `14 mm`；当前为 1/4-20 外牙通孔，boss 内藏一颗标准 1/4-20 捕获螺母，实际承力由采购金属球头和到货件配合确认 |
| boss 根部实体桥接肋 | y± 两条；全局包络 `3.4 × 26.4 × 12 mm`（x × y × z），x=`866.8…870.2 mm`，z=`266.5…278.5 mm`，根部从 `|y|=4 mm` 起、墙侧到 `|y|=30.4 mm`；在后盖 cavity subtraction 后添加，避开中央 `Ø7 mm` 通孔 |
| 光学基准 | 安装后以中空 M6 光学筒端面为光轴基准，右侧接收端/左侧发射端的装配光学端坐标为 `x=839.85 mm`；不再使用主体轴心作为光束端面基准 |
| 采购球头接口 | 13 mm 球，商品上端固定螺纹为 `1/4-20 外牙`，下端当前默认 `M8×1.25 外牙`；球头保持竖直，上端 1/4-20 外牙从各自 x 后端插入背面中央 boss；下端 M8 直接进入固定网柱顶部 30 mm 上段的中心攻丝底孔；斜立柱下段从黄灰交界 `z=16 mm` 到分型面 `z=230.5 mm`，顶部 30 mm 上段到 `z=260.5 mm`，四枚普通盘头/低矮圆头 M3×40 连接，网布/圆柱功能区至 `z=168.5 mm`，取消横向承托臂和适配连接器 |
| 固定网柱与 M6 支撑边界 | 固定网柱由 `z=16…230.5 mm` 下段和 `z=230.5…260.5 mm` 上段组成；网布/圆柱功能区为 `z=16…168.5 mm`；底面与 C 夹最高承托面共面，不向下插入 C 形座，上段顶面保留中心 `Ø6.8 mm` 攻丝底孔，实物攻 `M8×1.25` 或安装金属嵌件；球头下端 M8 直接进入该承座 |

不采用旧版左右交错托舌；当前是单列竖直安装，全部光学中心和主体中心都在 `y=0`。PETG 首样主体高度由 10 个 `20 mm` 间距通道和上下各 `18 mm` 边框余量决定，后续 CNC 沿用同一包络。线缆不在主体里挖槽，统一套管从底盖开放孔引出。

## 2. 分体壳与线缆（装配候选，不是最终打印放行项）

主体外面使用 PETG 非承力保护壳；当前壳体已经按真实方向和总成接口建出候选，待主体首件验收后按实际六角、45°尾线和球头接口冻结：

- 从 `z+` 俯视，前盖位于 `x-` 光学端，外形为正圆弧；后盖位于 `x+` 线缆端，x- 接驳边保持直角，仅 x+ 后部两个角做圆角，并在 x+ 背面中央（y=0、z 中心）形成加厚 boss；中间只表示前后盖分型边界，不建连线；采购球头上端 1/4-20 外牙沿 x 进入 boss 通孔；
- 前后盖均从主体 `z+` 套入，主体 `y±` 两侧的连续竖直槽由前盖、后盖分别占用 `x-` / `x+` 半段，槽/舌负责定位，沉头螺钉负责固定；
- 后盖 boss 根部在 y± 各有一条实体桥接肋，肋在后盖 cavity 扣除后再加入，连接 boss 根部和后壳侧壁；根部从 `|y|=4 mm` 起，中央 `Ø7 mm` 球头孔周围不被肋侵入；该肋是 PETG 首样的连续承力路径，不是外观装饰；
- 底盖按下方截面盖住壳体，使用两枚沉头螺丝固定，中央开放 `Ø12 mm` 过孔供剥皮后的统一线缆套管通过；该孔没有密封设计。

PETG 壳体负责保护和定位；当前首样冻结“传感器六角/主体 → 后盖 boss 根部 y± 实体桥接肋 → 1⁄4-20 捕获螺母/采购 13 mm 球头 → 下端 M8×1.25 → 固定网柱上段中心攻丝座”的接口。固定网柱由黄灰交界 `z=16 mm` 起的下段和顶部 30 mm 上段组成，分型面为 `z=230.5 mm`，终点为 `z=260.5 mm`，网布/圆柱功能区至 `z=168.5 mm`，不向下插入 C 形座。检测器/球头总成沿 x 移到立柱中心，承力路径在 CAD 中已闭合；实物需验证攻丝/嵌件、啮合深度和载荷。

## 3. 首样与机加工复用清单

每侧打印主体/盖件各一套；机加工预览只保留主体包络，采购球头不导出 STL：

| `PART` | 局部包络 | 作用 |
| --- | ---: | --- |
| `m6_machining_detector_body` | `10 × 56 × 216 mm` | 十路 20 mm 节距光学让位孔、十路 45° L 型安装孔、浅六角防转窝和盖件预留孔；右侧 x+、左侧 x- 外侧装入，主体保持简单矩形 |

`m6_machining_detector_body` 的局部原点为包络 x/y/z 最小点；后盖 boss、前后盖和底盖由完整 PETG 组件预览单独导出。采购球头和商品网夹不进入 STL。

## 4. 竖直采购球头接口

当前视觉占位使用 `13mm球【M8外牙】`，球头本体保持竖直：商品上端 1/4-20 外牙从 x 后端进入后盖背面中央加厚 boss，并由隐藏的标准 1/4-20 螺母锁紧；下端 M8×1.25 外牙从 z− 进入固定网柱上段顶面的中心攻丝底孔。固定网柱下段从 `z=16 mm` 起延伸至 `z=230.5 mm`，顶部 30 mm 上段延伸至 `z=260.5 mm`，四枚普通盘头/低矮圆头 M3×40 自攻钉连接，网布/圆柱功能区到 `z=168.5 mm`，底面与 C 夹共面；不再使用独立适配连接器。可选采购项保留：

```text
13mm球【1/4内牙】
13mm球【1/4外牙】
13mm球【3/8外牙】
13mm球【M6外牙】
13mm球【M8外牙】
13mm球【M10外牙】
```

选项只改变球头一侧的转接螺纹/紧固件，不改变十路 PETG 主体；下单前必须实测球头螺纹所在端、有效长度、旋钮净空、球头直径和开口姿态。

## 5. 首样顺序

1. 用真实 M6 器件验证头部六角 AF、水平总包络、14 mm 外丝段、有效外丝、原配螺帽、光学中心和尾线出口。
2. 先做主体单孔/单件试装，确认 `10 mm` 名义厚度和浅六角窝能让 M6 外丝穿出，并由朝台内平滑面的一枚原配螺帽锁紧；确认光学/外丝轴水平朝球台中心，蓝色尾线先朝 z−、再绕 x 轴 `-45°` 让线。
3. 加工一根完整十路主体，逐孔检查 `+10…+190 mm` 高度、`20 mm` 节距、x 光轴平行度、两侧外向插入、尾线和相邻通道净空，再镜像加工另一侧。
4. 主体验收通过后，按真实器件和金属固定器接口冻结前盖、后盖、底盖；当前候选壳体可用于装配检查，但不作为打印放行件。
5. 到货后把球头装成竖直姿态，确认上端 1/4-20 外牙与后盖 boss 同轴，下端 M8×1.25 外牙从 z− 完整拧入固定网柱上段中心攻丝座，记录有效啮合长度、攻丝/嵌件状态和载荷。确认检测器/球头总成沿 x 对正立柱中心、没有横向适配臂且不碰网布/网架，再检查球头锁紧后的微调保持性。

运行验证：

```text
python3 hardware/cad/test_m6_machining_spec.py
python3 hardware/cad/export_m6_machining_spec.py
python3 hardware/cad/test_m6_machining_previews.py
python3 hardware/cad/export_m6_machining_previews.py --clean
python3 hardware/cad/test_m6_component_previews.py
python3 hardware/cad/export_m6_component_previews.py --clean
```

组件预览包位于 `hardware/cad/exports/desktop-clamp-one-side-x1c-v0.4-top-load/m6-component-previews/`，包含左右完整的 PETG 主体、前盖、后盖和底盖 STL；采购球头、商品网夹及其螺纹不进入打印包。后盖 `Ø7.0 mm` 孔仍按 1/4-20 外牙通孔和隐藏捕获螺母窝建模，STL 不模拟螺旋牙；固定网柱顶端为无孔平顶，M6 下端支撑只保留独立待定义的接口包络。这些输出是首样/报价输入，不替代真实装配强度、球台兼容性、光学精度或 NPN 电气验收。

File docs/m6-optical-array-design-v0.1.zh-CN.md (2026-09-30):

# M6 直角对射十路 45° L 型检测器与球头微调结构 v0.6

状态：`当前 CAD 主线已冻结 PETG 长条主体、传感器姿态和采购球头接口；壳体已按 x 光学端/线缆端分段落地为装配候选，实物尺寸待首样放行`。

用户指定采购目标为 M6 激光 L 型对射、0–20 m、NPN 输出，链接 SKU 为 `6122579349941`。供应商图片资料、M4/M3 同系列尺寸和 NPN 接线图已归档；型号后缀、有效螺纹和实际包装仍需向卖家/实物确认。

## 1. 坐标和方向

- `x`：发射/接收光轴，也是主体的厚度/传感器插入轴；右侧接收器光学面朝 `x-`，左侧发射器镜像后光学面朝 `x+`；
- `z`：竖直向上，球台台面为 `z=0`，10 个通道是 `+10…+190 mm`，中心距 `20 mm`；
- `y`：主体的加宽方向/球台前后方向；M6 L 型器件的出光/受光面和 M6 外丝轴沿 `x` 水平朝球台中心，蓝色护套/尾线局部先朝 `z-`，再绕光束轴 `x` 旋转 `-45°`，因此从主体 `y-` 后方斜向让位；壳体沿 `x` 分成光学前盖和线缆后盖；
- 两侧主体用 `SIDE=1/-1` 做 x 镜像，保持光束方向相反、结构左右对称。

这套定义明确把两条轴分开：光学轴与 M6 外丝同轴、都沿左右方向；垂直于它的蓝色护套/尾线支路才是 L 型的另一条方向。供应商图纸给出总水平包络约 `20 mm`，其中水平 M6×0.75 外丝段约 `14 mm`。同一侧十个器件采用同一 `-45°` 滚转角，尾线沿 `y-/z-` 方向让开相邻通道。

## 2. 长条主体

主体当前是一根可打印 PETG 连续长条，不是旧版梳齿条；后续可按同一包络改做 CNC/金属件：

```text
局部尺寸：x=10 mm，y=56 mm，z=216 mm
原始通道中心：z=+10,+30,...,+190 mm（相对球台面）；总成整体上抬 20 mm 后，实际安装中心为 z=+30,+50,...,+210 mm
上下边框：各 18 mm（按当前传感器外形和 20 mm 节距余量）
```

主体厚度由实物安装杆约束：

```text
14 mm 外丝段 + 2 mm 头部卡入 − 5 mm 一枚外螺帽 − 1 mm 端部余量 = 10 mm 最大主体厚度
当前 CAD 主体厚度 = 10 mm，名义余量 = 0 mm；首件需按实物螺帽/有效外丝复核
```

每个通道包含：沿 x 的 `Ø6.6` 水平 M6 外丝通孔、采购件六角头让位、以及随 `x=-45°` 滚转的蓝色护套/尾线让位和 x 向浅六角窝 AF8×2.1。孔组形成“外侧插入 + 斜向出线”的安装位：右侧器件从 `x+`、左侧器件从 `x-` 外侧进入，水平外丝穿过主体；六角窝只卡住真实金属六角，不能做成深腔而顶住六角/外丝接驳处的平面。每个通道只在主体外表面安装一枚原配螺帽，不能把固定螺丝嵌入主体。主体孔和六角窝是机械定位特征，不是用打印壳承力。

当前是单列竖直安装，光学中心和 PETG 主体都位于 `y=0`，主体包络为 `10×56×216 mm`；不采用左右交错。右侧接收器从外侧 `x+` 装入，左侧发射器从外侧 `x-` 镜像装入；加宽主体用光学过孔、头部让位和浅 x 向六角座承接器件，朝台内平滑面安装一枚原配螺帽，线缆不陷入主体。若实物头部宽度或线缆与当前 45° 让线仍有干涉，先以实测干涉位置调整滚转角/孔位，不恢复旧版梳齿条。

斜立柱下段沿网高保留连续 `3 mm` 网布过道：网布先从球台中心侧穿入，端部止到立柱外表面；再把空心边套套到 Ø10 圆柱插杆，并沿原门洞轴线从 x 侧推入下段侧开接收腔。立柱在距顶部 `30 mm` 处分型，下段和上段用公母键及四枚普通盘头/低矮圆头 `M3×40` 连接；上段安装后封住圆柱入口，连接孔为上段 `Ø3.4 mm` 通孔进入下段 `Ø2.4×10 mm` 导向盲孔。网顶不设置轨道。

## 3. 前后壳和底盖（当前装配候选，待首样放行）

当前前后壳和底盖已经按总成重新建模，用于装配/方向检查；它们仍不是最终打印放行件，需在主体实物单孔试装、线缆走向和球头接口确认后冻结尺寸。当前结构为：

- 从 `z+` 俯视，前盖位于光学端 `x-`，外形为正圆弧；后盖位于线缆端 `x+`，x- 接驳边保持直角，仅 x+ 后部两个角做圆角，并在 x+ 背面中央（y=0、z 中心）增加后盖加厚 1/4-20 boss；boss 根部 y± 各增加一条实体桥接肋，连接到后壳侧壁但避开中央 Ø7 通孔；中间只表示前后盖分型边界，不建连线；采购球头固定的 1/4-20 外牙沿 x 进入 boss 通孔；
- 壳体从主体上方 `z+` 套入，主体 `y±` 两侧各有一条连续竖槽，前盖和后盖分别占用同一条槽的 `x-` / `x+` 半段，舌片保留 `0.25 mm` 装配间隙；
- 前后盖使用沉头螺丝固定到 PETG/CNC 主体，槽/舌负责装配定位；
- 底盖按主体下方截面封住下口，用沉头螺丝固定；底盖中央开放 `Ø12 mm` 过孔，剥去各传感器外皮后用统一套管引出线缆；不做防水声明。
- 完整检测器/球头总成沿 `z` 上抬 `20 mm`，避免壳体压到网布；前后盖和底盖仍保持完整实体，不使用剖切预览。

壳体只应保护和导向；当前包络、槽舌和底盖孔位都是首样候选尺寸，不作为最终加工尺寸。承力路径为：

```text
M6 头部六角/外螺帽 → PETG 长条主体（后续可 CNC/金属化）
→ 后盖 x 背面中央加厚 boss + y± 实体桥接肋 / 必要时金属嵌件 → 采购 13 mm 球头
→ 球头 z− M8×1.25 接口 → 固定网柱上段中心攻丝座；固定网柱自身从 z=16 mm 共面起由下段承载，在 z=230.5 mm 分型，顶部上段延伸至 z=260.5 mm，网布/圆柱区至 z=168.5 mm
```

## 4. 球头和网架连接

不直接打印云台。当前模型使用采购的 13 mm 球头并保持球头主体竖直：

```text
后盖背面中央加厚 boss 的 x 向 Ø7.0 1/4-20 外牙通孔（内藏标准捕获螺母）
        ↓
采购球头固定的 1/4-20 外牙 / 球头壳体
        ↓（竖直下方螺柱）
球头 z− M8×1.25 接口向下 → 固定网柱上段中心攻丝座
固定网柱：黄灰交界 z=16 mm 共面起 → 下段承载，z=230.5 mm 分型，顶部上段延伸至 z=260.5 mm；网布/圆柱功能区至 z=168.5 mm；上段顶面保留 Ø6.8 mm 攻丝底孔
```

允许采购选项为：`13mm球【1/4内牙】`、`13mm球【1/4外牙】`、`13mm球【3/8外牙】`、`13mm球【M6外牙】`、`13mm球【M8外牙】`、`13mm球【M10外牙】`。当前视觉/规格默认 M8 外牙，但未将其他选项伪装成已确定尺寸；到货后只改球头侧转接孔/紧固件。

网架立柱接口仍需实测螺纹和载荷：固定网柱从黄灰交界 `z=16 mm` 共面起由下段承载，在 `z=230.5 mm` 分型，顶部 `30 mm` 上段延伸至 `z=260.5 mm`；网布/圆柱功能区止于 `z=168.5 mm`，上段顶部保留 Ø6.8 mm 攻丝底孔，采购球头 z− 的 M8×1.25 直接进入该承座，不进入 C 形座；商品网夹的固定面、孔距、夹具外伸、垫片和有效啮合长度必须按实物重测。

## 5. 微调方式

球头提供粗调/锁紧，目标是匹配左右发射和接收阵列：

1. 先调球头整体偏航，使低、中、高通道的左右方向都落在接收面；
2. 调俯仰，使最低和最高通道同时通过；
3. 调滚转，使十路竖直间距和对侧十路对应；
4. 球头旋钮锁紧后，以最低/中间/最高三路复核并记录锁紧前后偏移。

球头本体应承担微调和锁紧，不让薄 PETG 壳或细牙顶丝成为唯一承力件。若首样载荷不足，优先在上段中心 M8 座和后盖 boss 内加入金属嵌件或将相应件改做 CNC；不再另造 90°支撑或适配板，也不把不可测的打印摩擦当作调节机构。

## 6. 当前入口和验证

```text
openscad -D 'PART="m6_detector_mount"' -D 'SIDE=1' hardware/cad/net_stand.scad
openscad -D 'PART="m6_detector_mount"' -D 'SIDE=-1' hardware/cad/net_stand.scad
openscad -D 'PART="m6_detector_body"' -D 'SIDE=1' hardware/cad/net_stand.scad
openscad -D 'PART="m6_detector_shell_front"' -D 'SIDE=1' hardware/cad/net_stand.scad
openscad -D 'PART="m6_detector_shell_rear"' -D 'SIDE=1' hardware/cad/net_stand.scad
openscad -D 'PART="m6_detector_bottom_cover"' -D 'SIDE=1' hardware/cad/net_stand.scad
openscad -D 'PART="net_clamp_clip"' -D 'SIDE=1' hardware/cad/net_stand.scad
openscad -D 'PART="net_clamp_clip"' -D 'SIDE=-1' hardware/cad/net_stand.scad
openscad -D 'PART="post_clamp_carrier_lower"' -D 'SIDE=1' hardware/cad/net_stand.scad
openscad -D 'PART="post_clamp_carrier_upper"' -D 'SIDE=1' hardware/cad/net_stand.scad
```

`m6_sensor_rail`、旧三轴模块和旧后背板入口仍保留为兼容诊断，但不属于当前装配主线。当前机加工预览只保留 `m6_machining_detector_body`；完整组件包另含 PETG 前盖、后盖和底盖，采购球头与商品网夹不导出 STL。

当前完整组件包可用 `python3 hardware/cad/export_m6_component_previews.py --clean` 生成，包含左右各一套 PETG 主体、前盖、后盖和底盖，共 8 个完整 STL；其 `manifest.json` 与正式机械打印清单分开，并记录材料、坐标、包围盒、体积和合盖贴合摘要。正式网架打印包另外包含左右各一套一体式 `net_clamp_clip` U 夹、左右各一套 `post_clamp_carrier_lower` / `post_clamp_carrier_upper` 立柱分件和两枚台底圆盘压块；台面上侧保护胶皮现场粘贴，不进入打印清单。正式包当前共 41 个 STL，256 mm 拼盘为 7 张板、0 个超床件；斜立柱下段/载体采用 `rx=0°、ry=51°、rz=45°` 三轴斜放，上段按分型面平放。

## 7. 待实物关闭的项目

- M6×0.75 有效外丝和原配螺帽真实厚度；
- 头部六角 AF、水平总包络、光学中心和蓝色尾线出口的实际偏置；
- 左/右器件是否完全同型、尾线出口和统一套管的最小弯曲半径；
- 13 mm 球头的实际螺纹版本、螺纹有效长度、旋钮净空和竖直姿态；
- 商品网夹安装面和孔位；
- NPN 常开/常闭后缀、接收器独立输出数量，以及供应商所称 5 ms 响应对应的最小有效脉宽/输出脉宽。

供应商资料归档在 [`docs/vendor/m6-laser-opposed/`](vendor/m6-laser-opposed/)，图片中的 M4/M3 资料是低价备选参考，不应直接套用到 M6 主体。

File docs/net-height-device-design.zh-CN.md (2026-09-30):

# 乒乓智配：内置式球网支架、擦网与过网高度设备

> 当前机械主线改为用户选定 SKU `6122579349941` 的 M6 直角对射光电器件：左右各十路，装入 10×56×216 mm 可打印 PETG 长条主体和后盖 x 背面中央加厚 1/4-20 boss，再由竖直采购 13 mm 球头的上端 1/4-20 外牙沿 x 接入后盖隐藏螺母；球头下端默认 M8×1.25 外牙 z− 直接进入固定网柱顶部 30 mm 上段的中心攻丝座。斜立柱由黄灰交界 z=16 mm 起的下段延伸到分型面 z=230.5 mm，再接顶部 30 mm 上段至 z=260.5 mm；四枚普通盘头/低矮圆头 M3×40 只连接这两个立柱段，网布/圆柱功能区仍到 z=168.5 mm。检测器/球头总成沿 x 移到立柱中心，取消横向适配臂和独立连接器。用户资料中“对射”条目标出 M6×0.75、20 m、NPN；同一张图的“反射”条目为 M6×0.5，不是当前器件。该 SKU 的最终型号后缀、有效螺纹长度、光学中心和独立输出数量仍待确认。STG-120ML 采购文档及旧版离散光栅/梳齿条只保留作历史回溯，不代表当前首样器件。

## 1. 当前方案与边界

当前机械方向已经从“夹在原球网立柱两侧的外挂 X 夹具”切换为“直接替换传统球网的内置式球网支架” ：

- 左右立柱、桌下夹持、真实网布和网端传感器安装位组成一套完整球网支架；网顶不设置轨道或承载条；
- 支架像传统网架一样从球台下方夹住台面，使用上下接触面和竖直螺杆夹紧；
- 网顶 PVDF 振动监测在装配时直接安装在支架网顶，不再依赖原球网立柱上的外挂夹片；
- 左右各有一套十路 M6 直角发射/接收器阵列，光学/M6 外丝轴沿 x，十个通道按 `20 mm` 节距单列装入宽体 PETG 主体；后盖 x 背面中央（y=0、z 中心）加厚 boss 开 x 向 Ø7.0 的 1/4-20 外牙通孔并隐藏标准螺母，采购球头保持竖直，上端 1/4-20 外牙沿 x 连接后盖，下端默认 M8×1.25 外牙 z− 直接进入 `z=230.5…260.5 mm` 固定网柱上段中心攻丝座；球头提供可锁紧的偏航/俯仰/滚转微调；
- M6 资料给出 20 m、10–30 V DC、NPN、约 8 mm 头部和约 14 mm 安装杆包络；最终后缀、有效螺纹长度、光学中心、输出数量和发射/接收对应关系仍待卖家/实物确认；
- ESP32-S3 继续生成独立的 `NetEvent v0.1`，与 BLE、WebSocket、MQTT、SSE 和 App 传输解耦；
- 首版不使用相机，不判断过网方向，不处理重叠多球，不宣称正式比赛裁判能力。

尺寸、阈值、时间窗和材料是首轮样机参数。真实球台厚度、网布张力、夹持力、PVDF 贴合方式、光学距离和环境光裕量必须通过实物记录后再收敛，当前不提交最终精度承诺。

旧的外挂方案保留在 `hardware/cad/net_post_x_clamp.scad`，只作为历史设计回溯和旧几何回归；当前机械参数源是 `hardware/cad/net_stand.scad`。

## 2. 系统分层

```text
替换式球网网顶 ── 左/右 PVDF 夹片 ── AFE ── 比较器 ──┐
                                                       ├─ ESP32-S3 业务事件层
M6 发射/接收器阵列 × 2 ── 接口/保护电路 ────────────────────┘       │
                                                               ├─ RGB/蜂鸣器
                                                               ├─ SmartPaddle WebSocket 适配
                                                               └─ RAM 小环形缓存
```

BLE、Wi-Fi、WebSocket、MQTT、SSE、配网和 App 多设备基础设施不在本工程重新设计；本工程只提供传输无关的业务事件和首个适配接点。ESP32-S3 固件通过 `firmware/main/net_event_transport.h` 的连接 hook 预留接入 SmartPaddle/目标连接层；当前工作树未包含该外部连接层，未接入 hook 时保持 fail-closed，不假装已经联网。

## 3. 内置式球网支架与 OpenSCAD

### 3.1 支架主体

`hardware/cad/net_stand.scad` 是当前唯一参数源，坐标为 `x=球台宽度方向、y=球台长度方向、z=台面以上`。首轮参数：

| 项目 | 参数 |
| --- | ---: |
| 球台宽度 | `1525 mm` |
| 首轮台面厚度 | `25 mm` |
| 网顶高度 | `152.5 mm` |
| 网柱外侧边界离台边 | `152.5 mm`（名义网架总宽 `1830 mm`） |
| 立柱中心离台边 | `138.5 mm`（28 mm 立柱宽度扣除半宽） |
| M6 光电阵列 | 左右各 10 路，原始基准 `+10…+190 mm`；总成上抬 `20 mm` 后安装高度 `+30…+210 mm`，中心距 `20 mm` |
| PETG 检测器主体 + 采购球头 | 每侧 1 套；主体为首样打印件，球头提供偏航/俯仰/滚转微调 |
| 网顶 PVDF 安装座 | 左右各 1 个 |
| 桌下夹紧螺杆 | M8×1.25 竖直圆头螺杆 + 双螺母捕获旋钮 |

尺寸依据：[ITTF Statutes 2026 官方文件](https://documents.ittf.sport/sites/default/files/public/2026-02/2026_Statutes_v1_consolidated_clean.pdf) 第 2.1.1、2.2.1–2.2.4 条：比赛面宽 `1525 mm`，网架包含网、悬挂、网柱和夹具，网柱外侧边界应在两侧边线外 `152.5 mm`。另外，[ITTF Technical Leaflet T2](https://documents.ittf.sport/sites/default/files/public/2020-11/2020_BoD_documents_FINAL.pdf) 对网柱水平部分给出不超过台边外 `160 mm` 的边界，并对可拆螺夹给出开口至少 `32 mm`、台下投影不超过 `100 mm`、台下宽度不超过 `60 mm` 的建议/限制。因而本方案把 `130 mm` 作为项目结构下限，把 `152.5 mm` 作为传统球网名义基准，把自定义夹体最外点控制为 `156 mm`；同时固定夹体外端与立柱下段宽端面齐平。它是训练/实验用传感器支架，不宣称 ITTF 认证。网布名义总宽为 `1830 mm`，实际商品网夹接口、台下净空和强度仍须首样量测。

每侧支架由以下部分组成：

- 立柱主体：`post_clamp_carrier_lower` 与 `post_clamp_carrier_upper` 组成斜立柱：下段从黄灰交界 `z=16 mm` 共面起承载绿色底座、连续网布过道和原位置侧开圆柱接收腔，上段在顶部下 `30 mm` 的 `z=230.5 mm` 分型并延伸到 `z=260.5 mm`；底面不向下插入 C 形座，顶部保留中心 `Ø6.8 mm` 攻丝底孔供 M8×1.25 直连。网布从球台中心侧穿入下段连续 y 向 `3 mm` 过道，侧边空心布套套在 `Ø10 mm` 圆柱插杆上，再沿原门洞轴线从 x 侧推入接收腔；门洞横向宽度保持历史 `15.2 mm`，四枚 `M3×40` 只连接立柱上下段；
- 传统桌下夹持：固定 C 形夹体跨过台面边缘，上夹板下表面现场粘贴胶皮压住台面上表面；桌面夹持开口、台底可动圆盘压块和 M8 螺杆区域保留，桌边外侧非接触区改为沿 y 全深的实心桥体；上下两条结构夹持舌头同步向台内延长 `20 mm`，台下有效伸入由 `62 mm` 增至 `82 mm`，下舌头的 M8 压紧件位于该有效区段中点；台底可动圆盘压块放大为 `Ø50 mm`，由下方加长 M8 圆头螺杆顶起，圆头落入压块底面的浅收纳窝并夹紧；上下结构夹臂均加厚到 `14 mm`，固定 C 夹最高水平承托面位于 `z=16 mm`，整根网柱底面与其共面，不向下插入；开口之外的外侧下部为实心渐变支撑，靠球台侧厚 `40 mm`、外侧收口为 `14 mm` 并形成斜底；固定下臂捕获一枚 M8 螺母，螺杆下端再用两枚 M8 螺母预先对锁并装入外径 `36 mm`、18 齿圆角锯齿握持圈，使旋钮与螺杆刚性同步，避免依赖 PETG 内螺纹或形成未定义的双螺纹约束；螺杆圆头和压块始终位于台面下方，不穿过球台，整个支架免打孔安装；实心桥体/渐变支撑的层向、旋钮握持手感、上侧胶皮、圆盘压块顶面摩擦、标准件防松、加长丝杆长度和实际夹紧力仍需实测；
- 网布安装：按网柱外侧边界距台边 `152.5 mm` 的常规尺寸，网布名义总宽为 `1830 mm`；网顶不设置轨道、承载条、拼接片或承托座。网布先穿过立柱连续 `3 mm` 过道，侧边空心布套套到 `Ø10 mm` 圆柱插杆上，再沿原门洞轴线从 x 侧推入接收腔；装上段后由上段封住插入口，不采用旧版矩形卡条、U 形卡夹或 keeper；
- PVDF 安装座：左右各一处，放在网端附近的网布白边/网架接口位置，与立柱保留 `18 mm` 横向净距；`pvdf_film` 由可拆压片夹持，薄膜可替换，线束沿立柱走线；
- M6 光学安装：左右各使用当前 `m6_detector_body`、`m6_detector_mount` 和 `m6_sensor_array`；直角器件的光学/M6 外丝轴沿 x 朝球台中心，尾线局部沿 z- 后绕 x 轴 -45°，十个通道按原始 `+10…+190 mm`、`20 mm` 节距单列布置，完整检测器/球头总成上抬 `20 mm` 后实际安装高度为 `+30…+210 mm`；M6 外丝从各自外侧穿过主体并由主体外表面一枚螺帽锁紧；x- 光学端为加大正球弧前盖，x+ 线缆端为接驳边直角且仅自身后端两角圆滑的后盖，底盖有约 Ø12 mm 统一套管孔。后盖 x 背面中央（y=0、z 中心）为加厚 boss，x 向 Ø7.0 通孔接采购球头上端的 1/4-20 外牙并由隐藏标准螺母锁紧；球头保持竖直，下端默认 M8×1.25 外牙 z− 接入 `z=230.5…260.5 mm` 上段中心攻丝座。固定网柱下段从黄灰交界 `z=16 mm` 延伸到分型面 `z=230.5 mm`，顶部 30 mm 上段到 `z=260.5 mm`，四枚普通盘头/低矮圆头 M3×40 自攻钉连接；网布/圆柱功能区至 `z=168.5 mm`；M6 头部防转、线缆出口、boss 孔和最终网杆接口尺寸在实物量测前不冻结。

OpenSCAD 的 `assembly` 只用于整体关系预览；`left_stand`、`right_stand`、`post` 用于单侧结构装配检查；`post_clamp_carrier_lower`、`post_clamp_carrier_upper`、`clamp_body_segment`、`table_clamp_body`、`clamp_pressure_pad`、`clamp_knob`、`m6_detector_body`、`m6_detector_shell_front`、`m6_detector_shell_rear`、`m6_detector_bottom_cover`、y+ UI 一体式填平固定板和 `calibration_gauge` 用于分件检查/导出，`post_clamp_slide_exploded`、`clamp_slide_fit_section` 与 `net_clamp_fit_section` 是真实装配截面/滑入证据；旧 `post_joint_*`、`net_rail*`、`m6_sensor_rail`、`m6_sensor_test_coupon`、`m6_gimbal` 和旧 `m6_machining_*` 仅保留作兼容/历史诊断。球网、M6 光电器件、采购球头、PVDF 薄膜、线束、M8 螺杆和软垫不被误认为 PETG 打印件；`clamp_top_pad` 是接触保护界面，不承担 C 形夹结构力路。

### 3.2 M6 直角对射、安装与微调

- 当前采购目标为 SKU `6122579349941`：M6 直角对射、NPN、0–20 m；图片中的 `VJTL06-20NZ/N3` 仅作型号映射候选，最终后缀必须让卖家回传确认；
- 图片的当前“对射”条目明确标注 M6×0.75，直角头部约 8 mm、安装杆包络约 14 mm、截面约 10 mm；上方“反射”条目的 M6×0.5 不适用于本项目。左右各 10 只，共 20 只形成 10 个对射高度通道；
- 当前是单列竖直安装，不采用旧版交错托舌；主体为 10×56×216 mm 长条，十个中心按 `20 mm` 节距布置，上下边框余量各 18 mm。每路使用 x 向光学过孔、浅 AF8 六角防转窝和外表面一枚原配螺帽，线缆不陷入铝材；
- 前后盖从 z+ 套入主体并共享 y± 连续边槽，前盖占 x− 半段、后盖占 x+ 半段；前盖只开十个光学孔，真实六角、蓝色护套、线缆和螺帽均收在外壳内，后盖 x 背面中央为加厚 1/4-20 boss，底盖提供开放线缆套管孔；
- 每侧基座采用竖直采购 13 mm 球头；商品上端固定螺纹为 1/4-20 外牙，沿 x 接入后盖隐藏螺母；下端默认选 `13mm球【M8外牙】`，M8×1.25 外牙 z− 直接进入 `z=230.5…260.5 mm` 固定网柱上段中心攻丝座；固定网柱网布/圆柱功能区止于 `z=168.5 mm`。球头锁紧后提供偏航、俯仰和绕光束 x 轴滚转微调，主体/boss/连续立柱承担已冻结的接口载荷，PETG 外壳只负责保护/导向，必要时后续改 CNC 或加金属嵌件。其余 1/4 内牙、1/4 外牙、3/8 外牙、M6、M10 选项只有在实物螺纹确认并重新匹配接口后才替换；
- NPN 图示为棕线 +V、蓝线 0 V、黑线开集电极输出。传感器是 10–30 V 设备，必须经过光耦/晶体管电平转换再进入 ESP32-S3，不能直连 GPIO；
- 商家确认的 `5 ms` 是状态变化到输出完成变化的响应时间，不是必须连续遮挡 5 ms 的最小检测门槛；最小输入脉宽、输出脉宽和高速球体漏检率按 [`M6 5 ms 响应/最小遮挡实测方案`](m6-response-time-validation-v0.1.zh-CN.md) 验收；
- 没有卖家确认的独立接收输出数量、逐通道遮挡波形和发射/接收对应关系前，不把 10 个机械位置自动当成 10 个有效 `beam_mask` 位；
- 供电、线缆弯曲半径、环境光抑制和邻道串扰必须在接板前确认。

机械首样首先确认：台面厚度是否适配、上下夹持面是否压稳、立柱是否倾斜或滑移、网布张力是否拉偏支架、左右光学模块是否平行。

## 4. 擦网检测

网顶白边左右各装一条可拆卸 PVDF 压电薄膜片。PVDF 用于动态应变、振动和冲击，不作为静态拉力传感器。

每路信号链为：

```text
PVDF → 输入保护/偏置 → 放大与带通滤波 ──→ 可调阈值比较器 → GPIO 低延迟触发
                                      └──→ ESP32-S3 ADC1 连续采样 → 短波形证据
```

首轮默认采样窗口：双通道、`16 kHz`、触发前 `20 ms`、触发后 `80 ms`。任一路达到有效阈值即可生成擦网候选，同时保留左右峰值、能量、持续时间、一致性质量和 `waveform_ref`。比较器只提供低延迟触发时间点，事件层等待 ADC1 波形完成后再计算特征。

若波形在等待窗口内没有完成，事件仍可超时输出，但必须带 `waveform_incomplete`；冷启动预触发历史不足时也不能把后窗口采满冒充完整帧。阈值、滤波和时间窗必须基于真实支架/真实网布记录收敛。

参考资料：[TE Connectivity 压电薄膜资料](https://www.te.com/en/product-CAT-PFS0004.html)。

## 5. 过网高度业务边界

当前硬件只能先冻结“检测窗口和机械安装边界”，不能提前冻结逐点高度算法：

- 若放大器能给出逐光点编号/位图，两段结果再映射成带段号的高度区间；
- 若放大器给出模拟位置量，经保护、分压和实测标定后换算高度；
- 若放大器只有单一 NPN/PNP 遮挡开关量，只能判断该分段有遮挡，不能独立证明过网高度；
- 事件层继续保留 `beam_mask`、最低/最高命中点、`beam_height_mm` 和 `quality_flags` 的兼容字段，但在放大器证据不足时必须为 `unknown` 或标记字段未验证；
- 外部设备、SmartPaddle/App 和 `NetEvent v0.1` 仍按时间戳传输，但不把某种传输协议当作传感器输出能力的证明。

启动自检或安装标定未通过时，事件保持 `unknown`（由校准健康门控制），并可附加 `beam_self_test_invalid`、`beam_channel_unhealthy` 或 `piezo_baseline_invalid`。当前仓库不虚构没有接入的发射器/接收器测量值。

## 6. 事件状态机

事件归并只面向单球、事件可分离场景：

1. 第一根光束被打断时开始光栅事件；
2. 所有光束恢复并保持短暂安静后结束光栅事件；
3. 在事件前后可配置窗口内关联 PVDF 擦网候选；
4. 关联成功为 `touch_over`，无擦网为 `clean_over`；
5. 擦网候选超时仍未形成光栅事件为 `touch_no_cross`；
6. 标定失效、波形不完整、传感器健康门失败、队列溢出或事件边界无法判断为 `unknown`。

事件契约独立于传输层，核心字段包括：

```json
{
  "type": "net_event",
  "schema_version": "0.1",
  "event_id": "uuid",
  "timestamp_us": 0,
  "calibration_id": "calibration-id",
  "beam_mask": 0,
  "beam_height_mm": [10, 40],
  "ball_bottom_gap_mm": [0, 10],
  "net_touch": {
    "triggered": true,
    "sensor_mask": 1,
    "peak": [0, 0],
    "energy": [0, 0],
    "duration_us": 0,
    "waveform_ref": "waveform-id"
  },
  "state": "touch_over",
  "quality_flags": []
}
```

RGB 灯和蜂鸣器区分正常过网、擦网过网、擦网未过网和无效状态。断链时事件进入设备 RAM 小环形缓存，恢复连接后按序补发；事件不绑定 BLE、WebSocket、MQTT 或 SSE 中的任何一种传输。

## 7. 阶段门

### 阶段 A：方案切换与边界固化

- 标记外挂 X 夹具为历史方案并保留旧几何回归；
- 以 `net_stand.scad` 建立当前参数源、打印清单、意图预览和验证脚本；
- 同步根目录 `README.md` 的当前结构说明；
- 不承诺最终精度或比赛级能力。

### 阶段 B：内置支架 CAD 与桌下夹持

- 编译左右完整支架、传统桌下夹持和光学/PVDF 安装位；
- 用同厚度样块检查上夹板、台底可动压块、M8 螺杆行程和软垫空间；
- 打印左右支架首样，确认安装/拆卸、倾斜、滑移和网布张力。

### 阶段 C：完整替换式球网样机

- 安装真实网布、PVDF 夹片和线束；网布从球台中心侧穿过两侧立柱的 `3 mm` 过道，侧边空心布套套在 `Ø10 mm` 圆柱插杆上，再沿原门洞轴线从 x 侧推入侧开接收腔；将立柱上段对准公母键并使用四枚 `M3×40` 连接；记录网布/绳张力、圆柱插杆防拔行程、实际夹持力和拆下上段后的抽出力；不装穿钉；
- 先用一孔主体/fit coupon 验证 M6×0.75 直角器件、浅六角防转、单枚螺帽和 -45° 线缆让位，再安装左右两套 M6 PETG 长条主体、前后盖、底盖和采购球头，装入 20 个器件和线束；球头上端 1/4-20 外牙直接从各自 x 后端进入后盖背面中央加厚 boss，下端 M8×1.25 外牙 z− 直接拧入固定网柱上段中心攻丝座；同时复核立柱下段底面 `z=16 mm` 共面、`z=230.5 mm` 分型和上段到 `z=260.5 mm`、网布/圆柱功能区止于 `z=168.5 mm`，以及从 `z=16` 起 `30 mm` 连续实心渐变到 `z=46` 后恒定 `28×38 mm` 的一体立柱；
- 用最低/最高/中间通道调偏航、俯仰、滚转，再做通道级高度补偿并锁紧；器件输出能力保持 `pending`，直到卖家资料、接线保护和实测波形闭环。

### 阶段 D：传感器与业务固件

- 复用 SmartPaddle 的 ESP32-S3 基础设施模式；
- 按 [`hardware/electronics/m6-capture-carrier-stm32g031k8-pinmap-v0.1.zh-CN.md`](../hardware/electronics/m6-capture-carrier-stm32g031k8-pinmap-v0.1.zh-CN.md) 以 `STM32G031K8U6/UFQFPN32` 作为独立载板工程候选，再把 10 路隔离输入、双边沿时间戳、SPI 从机 TX 预装、IRQ/CS 事务和时钟同步接到 ESP32-S3；CMSIS 寄存器绑定已通过目标架构 compile-only，但没有 DMA/定时器实测原型、最终 PCB 和联合 target 证据前，载板选择与 `kUseM6Carrier` 继续保持关闭；
- 保持两路 PVDF ADC1 短波形、M6 器件接口适配、健康门、事件归并、提示和 RAM 缓存；在接口证据不足时输出 `unknown`，不伪造逐点高度；
- 优先接 SmartPaddle WebSocket，同时保留多传输适配边界。

### 阶段 E：完整样机验证

按 [`validation-matrix.zh-CN.md`](validation-matrix.zh-CN.md) 验证正常过网、擦网过网、擦网未过网、逐光束遮挡、启动自检、机械误报、断链补发、单球分离和外部时间戳回放；另外必须关闭载板 MCU/PCB、SPI/IRQ/时钟同步、SmartPaddle `/ws` 联合 target 和 1–10 ms M6 波形门。主机测试、CI 和 CAD 渲染不能替代真实球台、网布、PVDF、光电器件、ESP32-S3 接板或 SmartPaddle/App 联调记录。

## 8. 当前明确的待实测项

- 球台真实厚度、边缘形状、夹持空间、立柱材料和支架兼容范围；
- PETG 立柱/夹持件在目标夹紧力下的变形、倾斜和滑移；
- 网布张力、网顶白边刚度、PVDF 夹片压力、AFE 增益、带宽和阈值；
- M6 器件最终后缀、M6×0.75 有效长度、头部防转、光学中心、供电电流、NPN 输出语义/数量、环境光抑制、邻道串扰、5 ms 响应对应的最小输入脉宽/输出脉宽和球体遮挡宽度；
- 事件归并窗口、安静时间、单球分离能力；
- 载板 MCU/封装与 PCB 引脚复用、启动自检实测、SPI/IRQ/时钟同步、SmartPaddle 联合 target/真实传输联调。

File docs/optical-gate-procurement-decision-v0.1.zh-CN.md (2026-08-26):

# 光栅采购与接口决策 v0.2（历史方案）

状态：`STG-120ML` 机械包络已纳入首样 CAD，但已被用户指定的 M6 十路光电阵列主线替代；本文仅保留采购回溯、接口风险和供电边界。当前机械方案见 [`m6-optical-array-design-v0.1.zh-CN.md`](m6-optical-array-design-v0.1.zh-CN.md)。

本文不是比赛级裁判能力承诺，也不是已经冻结的电子 BOM。淘宝商品页只能证明当前选中的商品和详情图可见字段；没有显示的电流、输出协议和逐光束数据，不在本文中补猜。

## 1. 当前选中的采购件

商品链接：[对射 STG-120ML 金属线 / 精度 3.87 mm](https://item.taobao.com/item.htm?id=878648735163&skuId=5719414916652)。Chrome 扩展当前读到的选中 SKU 是：`对射 STG-120ML 金属线/精度3.87mm 推荐`，商品页详情图可见以下机械/光学字段：

| 项目 | 当前证据 | 工程含义 |
| --- | --- | --- |
| 类型 | 对射型、侧面出光、金属护套光纤头 | 不是十个独立的发射/接收 GPIO 模块 |
| 检测面 | `120 mm` | 适合覆盖网顶上方约 120 mm 的竖直窗口 |
| 光点排列 | `32 × Ø0.25 mm` 纤芯 | 商品图标注点距 `3.870 mm`，理论上可形成 32 个高度采样位置 |
| 头部包络 | 约 `130 × 19 × 6 mm`；有效纤芯段约 `120 mm` | CAD 以实物量具复核前的安装包络建模 |
| 光纤插口 | `Ø2.2 mm` | 线缆不能在打印托架内急弯或被压住 |
| 最大检测距离 | `1000 mm` | 一对头不能直接跨过 `1525 mm` 球台全宽 |
| 配套要求 | 详情图写明“光纤线需搭配放大器一起使用” | 当前购物车中的 STG-120ML SKU 不是完整放大器系统 |

详情图还展示了 `12–24 V DC` 的放大器供电标识。这个字段证明的是配套放大器图示的输入范围，不等于已经确认 STG 光纤头本体的独立供电参数；光纤头本身更像无源探头，最终仍要以放大器铭牌和接线表为准。

## 2. 对球台全宽的机械结论

单对 STG-120ML 的最大检测距离小于球台宽度 `1525 mm`，不能把两只头直接装在左右立柱上后宣称覆盖全宽。当前 CAD 改为两段方案：

```text
左外侧头  ─────── ≤1000 mm ───────  中央背靠背头
中央背靠背头  ───── ≤1000 mm ─────  右外侧头
```

- 每段跨度约 `763 mm`，给 1000 mm 标称距离留余量；
- 中央使用一个背靠背支撑桥，同时承载左右两段的中央光纤头；
- 左右外侧使用独立 `stg120_outer_carrier`；
- 头部窗口朝向对应分段，打印托架只包住 130×19×6 mm 外形，不把商品的 M3 螺纹孔位未经量测写死；
- 这会增加中央支撑件和一组放大器/线束，首样必须实测中央支撑是否干扰球路、网布和张力。

因此，首样采购数量按 `2 对 STG-120ML 光纤头` 估算，而不是当前单个购物车数量直接等于全宽方案数量。

## 3. 高度信息目前还没有被证明

`3.87 mm` 是光纤点距，不自动等于 ESP32-S3 能收到的高度位图。商品页同时出现 NPN、PNP 和模拟量放大器选项，但当前选中的 SKU 只证明了 STG-120ML 头部，并没有证明以下任一能力：

- 输出 32 路逐光束 `beam_mask`；
- 输出最高/最低被挡光点编号；
- 输出与高度对应的模拟电压；
- 两段光纤头能否由同一放大器独立读出。

所以当前业务层不把 `NetEvent` 直接改成 64 路位图。拿到放大器铭牌、引脚图和一帧实测输出后，再选择：

1. 逐光束位图/编号输出：映射为两段带段号的高度区间；
2. 模拟位置量：经保护、分压和 ADC 标定后换算高度；
3. 只有单一 NPN/PNP 遮挡输出：只能判断“该段有球/有遮挡”，不能独立证明过网高度。

## 4. 5 V、功耗和充电宝

当前能确认的结论很直接：**不能把 5 V 充电宝直接接到该商品的配套放大器上。** 商品详情图写的是放大器 `DC 12–24 V`；商品证据没有给出工作电流或峰值电流，因此现在不能诚实地回答“耗电多少瓦”。

现场供电分两种：

| 方案 | 当前判断 |
| --- | --- |
| 5 V 充电宝直连放大器 | 不可接受；电压不在已见的 12–24 V 标识范围内 |
| 充电宝 + 5 V→12 V 升压 | 原理上可行，但必须按放大器实测峰值电流选升压模块，并留启动余量、限流和欠压保护 |
| 12 V 电池/电源包直接供电 | 更简单；仍需确认两套放大器总电流和线缆压降 |
| 24 V 供电 | 只有在确认放大器额定范围和发热后才采用，不为首样优先方案 |

现场估算公式：

```text
输入电流 ≈ (12 V × 放大器总电流) / (5 V × 升压效率)
```

例如不能把未知的“某个电流”当成结论；必须拿到实物空载、正常遮挡、启动瞬间三组电流记录，再决定普通充电宝是否带得动。ESP32-S3、PVDF AFE、指示灯和蜂鸣器还要在此基础上另加预算。

## 5. ESP32-S3 接口边界

首样不要把 12–24 V 工业输出直接接进 ESP32-S3：

```text
12–24 V 电源
    ├──> STG-120ML 光纤头 × 2 对
    └──> 配套放大器 × 2
                  └── NPN/PNP/模拟量（待确认）
                         └── 光耦或保护电平接口
                                └── ESP32-S3 GPIO / ADC
```

若最终采购 NPN/PNP 版本，至少需要确认输出是否为开集电极、共地方式、常开/常闭逻辑和最大漏电流；若采购模拟量版本，需要确认电压范围，不能把 12–24 V 量程直接接到 ADC。传输层继续复用 SmartPaddle 的 BLE/WebSocket/MQTT/SSE，传感器业务适配独立于传输层。

## 6. 需要补齐的采购件

首样不只买“光纤头 + 一个适配器”：

1. `STG-120ML` 光纤头 `2 对`；
2. 与该头匹配的放大器 `2 套`，优先询问能否输出逐光束/位置量；
3. 放大器到 ESP32-S3 的光耦/电平或模拟量保护接口；
4. `12 V` 现场电源，或经过实测选定的 5 V→12 V 升压模块；
5. 配套光纤/金属护套线、应变释放、弯曲半径保护和备用接头；
6. 新版两侧外托架、中央背靠背支撑桥；
7. 用于 3.87 mm 高度基准的机械标定规和量具记录。

## 7. 下单/接线前问卖家

```text
1. STG-120ML 详情图中的“双数显 N53N / 模拟量放大器”分别对应哪些具体型号？
2. 放大器额定输入是否确实为 DC12–24V？空载、正常工作和启动峰值电流分别是多少？
3. NPN/PNP 输出是单一遮挡开关量，还是能读出 32 个光点的编号/位图？
4. 模拟量输出的电压范围、零点、满量程、响应时间和负载要求是什么？
5. 一套放大器能否同时接左右两段，还是每对 STG-120ML 必须配一套？
6. STG-120ML 两个金属头的实际外形、孔位、线缆长度和最小弯曲半径能否提供 CAD/尺寸图？
7. 1000 mm 检测距离是在 12–24V、目标球体和室内环境下的保证值，还是仅为经验上限？
```

在卖家回答和实物电流记录回来前，项目只冻结机械包络和“分两段”的安装方向，不冻结 5 V 供电、不冻结放大器型号，也不把高度识别写成已经完成。

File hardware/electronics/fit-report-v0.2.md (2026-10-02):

# Pingpang SmartGear electronics system fit report v0.2

- Overall mechanical/package status: **PASS**
- Generated: `2026-10-02T01:39:00.941286+00:00`
- Mechanical source: `hardware/cad/net_stand.scad`
- Native KiCad status: `PASS`
- Native KiCad projects: `4` `.kicad_pcb` / `4` `.kicad_pro`; schematic PDF export: `PASS`
- Atopile `.ato`: validate `PASS`, build `PASS` (interface contract only; native KiCad remains the PCB source of truth)
- Native schematics exported: `4/4`; ERC is intentionally OPEN for the first-article review files.
- Retained legacy schematic connector contract: `PASS` (obsolete P2.00/P2.54/PinHeader tokens are rejected).

## Board files and signal budget

| board | outline | copper layers | footprints | 3D models | nets | tracks | unconnected |
|---|---:|---:|---:|---:|---:|---:|---:|
| `esp32-control-v0.1.kicad_pcb` | 86.0 x 32.0 mm | 2 | 38 | 26 | 46 | 2 | 56 |
| `m6-receiver-carrier-v0.2.kicad_pcb` | 80.0 x 32.0 mm | 2 | 27 | 23 | 41 | 0 | 48 |
| `emitter-power-v0.2.kicad_pcb` | 68.0 x 32.0 mm | 2 | 11 | 7 | 30 | 0 | 6 |
| `ui-panel-v0.2.kicad_pcb` | 58.0 x 28.1 mm | 2 | 15 | 11 | 16 | 0 | 32 |

The PCB files and board STL/STEP exports are real KiCad artifacts. The main board still has an open copper gate (`56` unconnected items); it is not a fabrication/Gerber release.

- ESP32 native assembly contract: **PASS**; the KiCad `.kicad_mod` pads, exposed GND pad, STEP model and antenna keepout share one datum, assembled at +90° so the antenna points to board `-X`, while J7 remains on the `+Y` UI edge.
- Physical cable connectors pass the generated `MX1.25`/1.25 mm pad-pitch contract, and every such PCB connector has a matching MX1.25 schematic instance; USB-C and button footprints are separate interfaces.
- Ordered connector pin-to-net contracts pass for the mother board, receiver 3-wire inputs, emitter 2-wire outputs and UI harnesses.
- Cross-board harness contract: **PASS**; J4↔J_HOST and J7↔J_MOTHER are pin-for-pin, while J8↔J_PWR explicitly maps `sensor_fused/sensor_gnd` to `sensor_v/sensor_gnd` and keeps the sensor return out of MCU `gnd`.
- Native PCB DRC aggregate: `PASS`; errors, expected isolated-copper warnings and unconnected airwires are reported separately below.

## Same-datum enclosure fit

| assembly | result | critical minimum margin |
|---|---|---:|
| right ESP32 mother board | **PASS** | 4.000 mm |
| left emitter power board | **PASS** | 4.000 mm |
| y+ side UI board | **PASS** | 0.560 mm |
| internal battery envelope | **PASS** | 2.000 mm |
| vertical M6 receiver carrier | **PASS** | 1.500 mm |

Mother-board retention is the native `esp32-control-v0.1.kicad_pcb` Edge.Cuts contour plus two opposing x-end printed `[`/`]` C-brackets; the full-height webs stay outside the board pocket and the lower/upper lips capture the board without shell bosses or locating pins.

## Interference and exploded-view evidence

- AABB fit: conservative x/y/z envelope checks for every imported KiCad board and both internal battery packs.
- Boolean interference: `PASS` across both clamp sides and both M6 sides.
- OpenSCAD view compilation: `PASS` for full cutaway, physical shell cutaway, per-side exploded views, M6 integration, and M6 exploded assembly.
- Harness geometry: **OMITTED** from SCAD; KiCad connector/net contracts remain in the electrical review, while only real device envelopes and required pass-through openings participate in mechanical checks.
- Printable package: `39/39` STL files closed and positive volume.

## UI panel direct interface

- Direct datum status: **PASS**. START/MODE and both 0603 LEDs use their footprint centers; USB-C uses the measured component-model front-profile datum from the KiCad export.
- Power interface contract: **PASS**. The shell exposes `1` external charge port (y+ UI Type-C); VBUS/GND cross J_MOTHER/J7 pins 13/14, local CC1/CC2 Rd pull-downs are present, and the mother board has no second USB socket.
- Insert-panel contract: screen opening `27.4 × 16.4 mm`, button pocket `Ø4.9 mm` with `Ø1.6 mm` plungers, LED bores `Ø2.2 mm`, speaker opening `Ø12.0 mm`, USB-C fit tunnel `9.4 × 3.7 mm` from the GCT USB4105 `.kicad_mod` F.Fab rounded metal-shell profile (solder/contact legs and F.CrtYd rectangle excluded), with the larger rounded bowl ending at the placed KiCad housing front; a `0.6 mm` annular printed floor remains around that bowl, while the smaller KiCad-fit tunnel is open through the centre for the Type-C housing; no subtraction widens through the C-clamp wall; board-to-panel gap `0.6 mm`; panel inserts from the cavity with `0.6 mm` side clearance and finishes `0.0 mm` from the wall datum.
- Integrated UI panel-mount contract: the faceplate and cavity-side capture ring are one fused print with `8` cavity-side holes, a `2.5 mm` mounting flange at y=`17.5..20.0 mm` plus a window capture bridge at y=`20.0..26.0 mm` (panel perimeter overlap `0.4 mm`), outer/inner borders `7.0/1.6 mm`, window clearance `0.2 mm`, Ø`2.3 mm` clearance holes for 2 mm mushroom-head self-tapping screws into Ø`1.6 mm` blind pilots cut directly in the solid C-clamp wall; pilot depth `8.3 mm` leaves `0.7 mm` outer-wall floor, with no positive boss and `1.2 mm` minimum edge land. Panel hidden relief cutouts: `none`; outer face screw openings: `none`.
- USB-C mating axis: `PCB normal -> y+ panel`; its KiCad footprint model is `USB_C_Receptacle_GCT_USB4105-xx-A_16P_TopMnt_Horizontal.step (component-filtered KiCad export, rotated +90° for y+)`. The final purchased receptacle dimensions/part number remains an explicit first-article item.

## PCB DRC evidence

| board | DRC status | errors | warnings | unconnected |
|---|---|---:|---:|---:|
| `esp32-control-v0.1.kicad_pcb` | **PASS** | 0 | 0 | 56 |
| `m6-receiver-carrier-v0.2.kicad_pcb` | **PASS_WITH_EXPECTED_WARNINGS** | 0 | 1 | 38 |
| `emitter-power-v0.2.kicad_pcb` | **PASS_WITH_EXPECTED_WARNINGS** | 0 | 2 | 6 |
| `ui-panel-v0.2.kicad_pcb` | **PASS** | 0 | 0 | 18 |

The isolated-copper warnings are expected at this review stage because zones surround intentionally unrouted nets; they do not close the electrical fabrication gate.

## Release boundary

- Mechanical/package gate: **PASS**.
- Electrical fabrication gate: **OPEN** until copper routing, DRC, power-current bench validation, and the placeholder optocoupler/MCU selections are frozen.
- UI panel interface gate: **PASS**; the real button/LED/USB-C footprints and KiCad 3D models are checked against the printed y+ insert-panel datum. Screen/speaker/battery remain the off-board SCAD envelopes; the purchased USB-C dimensions/part number remains open until first article.
- Lid fit is treated as a flush, no-visible-gap mechanical interface; this is not an IP waterproof certification.

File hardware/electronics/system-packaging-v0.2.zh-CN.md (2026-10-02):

# ESP32 主控系统：机械—电气接口合同 v0.2

状态：**机械统一坐标、板件包络、壳内安装、过线和盒盖贴合检查已完成；KiCad/Atopile 文件已在仓库，电气生产释放仍 OPEN。**

本文件是 `hardware/cad/net_stand.scad`、ESP32 母板和三个子板的共同约束。当前版本已经把真实 KiCad 板框/器件 3D 包络放进壳体同一坐标系，并由 [`validate_system_fit.py`](validate_system_fit.py) 做 AABB、布尔干涉、OpenSCAD 视图和打印清单自检；正式走线、器件实测和实物首样仍是下一道电气放行门。

## 1. 机械分工与装配位置

| 位置 | 板/器件 | 首样外形包络 | 装配方式 |
| --- | --- | ---: | --- |
| 右侧夹具下方梯形腔 | ESP32-S3 + 1S 充放电/3.3 V 母板 | PCB `86 × 32 × 1.6 mm` | 按 KiCad Edge.Cuts 板形相减出板形让位，x−/x+ 两端各一件打印 [ / ] C 形端部夹件承托/防上浮；端部竖根留在实心端墙内，不设主板 boss 或定位柱，板边保留 FDM 装配余量 |
| 右侧 M6 接收端附近 | 接收载板/线束汇聚 | 原生 KiCad `m6-receiver-carrier-v0.2`，`80.1 × 32.1 mm` | 10 路三芯对插 + 8 芯主控口 + 2 芯传感器电源口；线束先汇聚再插接，不允许飞线焊死 |
| 左侧夹具下方梯形腔 | 发射端内置电源子板 + 受保护 1S 电池 | 子板 `68 × 32 mm`；电池约 `65 × 30 × 7 mm` | 电池软包放在少器件的一端，泡棉/压条限位；子板由四个电池外侧边缘支撑/压片固定，避免 boss 穿过电池宽面 |
| y+ 侧壁操作面 | UI 子板 | `58 × 28 × 1.6 mm` | 通过 14 芯 MX1.25 锁扣线束连接母板，其中 13/14 脚带回 Type-C VBUS/GND；START/MODE、2 个 LED、唯一外部充电口直接在板上并对准 y+ 封口板，屏幕仅用排线连接 |
| 两侧 M6 壳体 | 十路发射/接收头和线缆接口 | 现有 `10 × 56 × 216 mm` 主体/壳体包络 | CAD 只保留真实光电头/壳体包络和底盖过线开口；线束走向、导向条和压紧件不建三维实体 |

### 母板的尺寸结论

当前梯形腔有效范围为 `102.8 × 40 mm`。母板 `86 × 32 mm` 放入后：

- x 向总余量 `16.8 mm`，理论两端各 `8.4 mm`；
- y 向板框总余量 `8 mm`，实际按器件包络与插拔方向校核；
- PCB 上表面到腔顶预留 `5 mm`，按最高顶面器件 `4 mm` 加 `1 mm` 装配余量；
- 四个安装孔中心距母板边 `4.5 mm`，孔为 `Ø2.8 mm NPTH`，不会侵入 ESP32 天线禁布区；
- 母板不把侧插连接器硬塞进 3 mm 边隙；主机外部充电只由 y+ UI 面板 Type-C 接入，J3 仅是传感器 10–30 V 现场电源，J_EXT 仅是发射板腔内维护/后备输入。J3/J8 的回路标成 `0V_SENSOR`，由 J8 pin2 映射到接收载板 J_PWR pin2，不与 MCU `GND` 混用。

因此母板尺寸足够，且不会干涉梯形腔；所有需要较多现场接线的部分拆到子板，避免“板虽能放下、插头却插不进去”。板框尺寸按空腔允许范围尽量收紧，但保留器件间距、走线通道和插拔操作空间。

### 光学间距与 PCB 尺寸解耦

发射头/接收头的距离和 `20 mm` 光学排列只决定两侧光学头集模组及其线束长度，不决定接收载板的长度。十路接收头的 `BN/BU/BK` 三芯线先在机械侧汇成线束，再分别插入紧凑接收板的 `J_RX00…J_RX09`；因此接收板改为 `80 × 32 mm` 的两排五路接口/采集区，板内排列不表示光学头的物理间距。十路发射头的 `BN/BU` 两芯线同样在进入发射电源板前汇线，板上用 `J_TX_A/J_TX_B` 两个 10 芯段承接。

统一坐标检查的关键实测于 CAD 包络为：母板实际模型到腔体侧壁最小余量 `0.395 mm`、最高器件到腔顶余量 `1.005 mm`；发射板最小余量 `3.000 mm`，UI 板 `6.000 mm`，电池包 `2.000 mm`。M6 载板竖直放入接收壳后最小边界余量 `1.500 mm`，实际器件包络与光学壳体之间保守余量 `2.910 mm`。这些是模型包络值，不替代打印收缩和真实连接器试装。

## 2. 接线方式

现场可拔插线全部采用以下方式之一：

1. 带防呆的锁扣式线对板连接器，物理节距统一为 `MX1.25`（1.25 mm）；
2. UI 面板 Type-C 是主机唯一外部充电口；传感器 10–30 V 仍使用独立的可插拔螺钉端子或压接端子，不与逻辑/电池电源并联；
3. 电池使用带极性防呆和锁扣的 2 芯端子；
4. M6 传感器按 `RX00…RX09` / `TX00…TX09` 编号做成线束，端头压接后插入对应 MX1.25 锁扣座；发射端在板上分为 `J_TX_A`/`J_TX_B` 两个 10 芯接口。

不采用裸焊盘接外部线、不采用没有应力释放的飞线。每根线束两端都贴 `SIDE / CH / SIGNAL` 标签，并在子板上留测试点。

## 3. ESP32-S3 信号预算

主控采用 ESP32-S3-WROOM-1-N16R8 首样模块。低 GPIO 区域按下面合同使用，已经覆盖当前功能，不再额外占用启动、USB、PSRAM 或调试专用脚：

| 功能组 | 信号 | GPIO |
| --- | --- | --- |
| PVDF | `pvdf_adc_l/r` | GPIO1 / GPIO2 |
| 交互按钮 | `ui_btn_start/mode` | GPIO3 / GPIO4 |
| 载板复位 | `carrier_reset_n` | GPIO5 |
| 扬声器 I2S | `ui_spk_bclk/ws/dout` | GPIO6 / GPIO7 / GPIO17 |
| 蜂鸣器 | `ui_buzzer` | GPIO8 |
| 电池采样 | `bat_sense` | GPIO9 |
| M6 载板 SPI/IRQ | `sck/mosi/miso/cs/irq` | GPIO10…GPIO14 |
| UI I2C 屏 | `ui_scl/sda` | GPIO15 / GPIO16 |
| 指示灯 | `ui_led_status/battery` | GPIO18 / GPIO21 |
| 原生 USB 调试保留 | GPIO19 / GPIO20 未接入 UI Type-C | 当前 Type-C 充电专用，D+/D−/SBU 留空 |
| 启动/调试保留 | `BOOT`, UART0 | GPIO0, GPIO43/44 |

这套分配是当前低 GPIO 功能预算；如果以后要增加屏幕复位、旋钮或更多按键，应在 UI 子板上加 I2C GPIO 扩展器，不得临时抢占 M6 SPI、启动脚，或把 Type-C 充电口误改成未验证的数据接口。

## 4. 电源域

```text
主控腔：受保护 1S 电池 -> IP5305T 5 V -> TPS62162 3.3 V -> ESP32/UI/逻辑
主控充电：y+ UI Type-C（充电专用） -> J_MOTHER/J7 14 芯 pin13/14 -> PTC -> IP5305T -> 电池/5 V
接收端：外部 10–30 V -> 保险/TVS -> SENSOR_RAIL -> 接收载板/接收头
发射端：内置受保护 1S 电池 -> 独立升压/限流模块 -> TX_RAIL -> 十路发射头
```

- 发射器默认内置电源，电池和升压模块放在左侧零件较少的腔体；
- 发射电源子板保留 `EXT_TX_IN` 作为腔内维护/后备输入，不能把它当作 C 夹外壳上的第二个充电口；
- 发射端电源不能从 ESP32 的 3.3 V/5 V 逻辑电源直接取；
- 传感器外部电源入口的保险丝/PTC、TVS、反接和线束应力释放都在传感器端子侧完成；主控 Type-C 入口的 PTC 位于主控板，CC1/CC2 Rd 位于 UI 板；
- 电池只允许带保护板的成品 1S 电池包，电量采样只用于估算，不替代保护电路。

## 5. 交互件与盖板

- 两个面板按钮：3.9×3.0×2.0 mm 两脚 SMD PCB 直装按键，封口板用浅凹面和腔内 1.6 mm 导向柱接触，分别对应 `START`、`MODE`；
- 屏幕：预留 0.96 英寸 I2C OLED 区域，屏幕与封口板之间用透明窗/内侧支承，不让屏幕裸露在腔体缝隙；
- 指示灯：两个 0603 单色 LED 直接焊在 UI PCB 上，使用 KiCad 封装 3D 模型随板 STL 导出，各自对准封口板 2.2 mm 直孔；不在 SCAD 中重复创建 LED 芯片或 LED 包络，也不引入额外 RGB/WS2812 走线；
- 蜂鸣器：使用带声学膜/防护网的器件，不能在盖板上留下裸通孔；
- 扬声器：使用带防尘防溅声学膜的单元，封口板只开受控的声学窗口并配压框；
- USB-C：16 针插座直接焊在 UI PCB 上，使用 KiCad 库模型随板 STL 导出，并在 UI 垂直安装坐标中旋转到 y+ 面板法向；仅 VBUS/GND/CC 使用，D+/D−/SBU 留空。J_MOTHER/J7 改为 14 芯并以 13/14 脚把 VBUS/GND 带回主控板，主控板不再放第二个 USB 插座；端口穿过封口板并配硅胶帽。具体厂家尺寸/料号在首样前冻结；屏幕仍保留排线连接，屏幕/扬声器等非贴板实体由 SCAD 装配层定义，线束本身不生成三维实体。

## 6. UI 面板与过线要求

电子腔不再使用独立底盖、连续垫或旧的 UI 压框。y+ 侧窗由一体式 UI 填平固定板从腔内 y- 侧推入，外表面与 C 夹壁齐平；腔内法兰、捕获环和 8 个通孔与面板同一 STL，使用 8 枚 2 mm 蘑菇头自攻钉直接进入 C 夹内壁盲导孔。这里的“齐平”只指装配后不能出现明显错台或松动，不宣称 IP 等级。

- UI 面板保留连续承托边和腔内装配导向；固定力由 8 个腔内螺钉均匀传回 C 夹实心内壁，不靠外侧装饰孔或旧 boss；
- 面板周边保持打印配合余量，不能让单个螺钉把面板拉成翘曲；
- M6 前盖、后盖、底盖均有连续搭接/压合面；底部出线改为多孔压紧件或灌封压线套，并配滴水弯/应力释放；
- 过线参考固定为“每侧独立汇线”：右侧 `RX00…RX09` 三芯线进入接收子板，左侧 `TX00…TX09` 两芯线进入发射电源子板；左右不共用一根无标签线束；
- 盖板装好后只用塞尺/纸条和开合手感检查周边贴合，目标是无可见贯通缝、无明显错台、无松动；不安排浸水、压力气密或 IP 等级测试。

## 7. 当前放行门

已关闭：母板/电池包络、母板四点 boss 位置、发射子板边缘支撑/压片位置、信号预算、母板—子板接口分工、主控唯一 Type-C 充电口（UI 14 芯 VBUS/GND 回路与 CC Rd）、发射端内置电源和腔内后备接口、按钮/屏/声学/USB-C 的机械预留方向、KiCad 贴板器件模型与板 STL 统一、光学间距与 PCB 尺寸解耦规则、真实 KiCad 板模型与壳体同坐标放置、两侧 M6 过线开口（只保留开口/沉台，不建线束实体）、UI 一体式填平固定板和 39 件打印矩阵（含斜立柱顶部 30 mm 分型、四枚普通盘头/低矮圆头 M3×40 立柱连接螺钉与下段 M2.4 盲孔、Ø10 圆柱插杆和侧开接收腔）。

已由生成器和 CAD 校验关闭：母板和子板 Edge.Cuts 尺寸、安装孔、线束连接器包络、UI 一体式填平固定板的捕获面、两侧 M6 过线开口、KiCad 贴板器件与真实外接实体的世界坐标对位（SCAD 不生成线束实体）、实际板/电池/壳体的布尔干涉、左右爆炸/剖切视图编译和 39/39 打印件闭合性；斜立柱分型还需首件确认公母键滑入、四枚 M3 螺钉有效啮合和侧开接收腔的 Ø10 圆柱插入力/防脱。

仍需实物/电气验证：真实 MX1.25 连接器厂家/料号、线径与插拔空间、真实电池厚度与弯折半径、IP5305T/升压模块的发射电流余量、UI 面板自攻钉拉脱强度、M6 传感器输出后缀和十路线束的实际长度；PCB 铜箔布线、ERC/DRC 生产门、光耦/MCU 最终料号和电源波形仍保持 OPEN。当前库中的 JST-GH 1.25 mm 模型只是审查包络代理，不等于已采购的 MX1.25 具体料号。完整证据索引见 [`fit-report-v0.2.md`](fit-report-v0.2.md)。

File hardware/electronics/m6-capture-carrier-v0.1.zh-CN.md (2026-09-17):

# M6 十路边沿采集载板接口 v0.1

状态：`协议与 ESP32-S3 SPI master/IRQ 读取路径已实现并通过 ESP-IDF 5.5.1 编译；STM32G031K8U6/UFQFPN32 已有寄存器绑定和可链接参考 ELF/bin；运行时时钟校准门和板级 hook 已接入但默认关闭；光耦最终型号、PCB、线长和实物时序仍待确认`。

这份输入解决 SmartPaddle 参考主板的实际 GPIO 冲突。它不把 10 路输入接到当前 `net_sensor_config.h` 的占位 GPIO，也不使用普通 I²C 轮询去替代短脉冲采集。

## 1. 推荐分层

```text
M6 接收器 BK × 10
        │ 10–30 V NPN 开集电极
        ▼
每路独立 R_IN + 光耦隔离 + 3.3 V 逻辑
        │
        ▼
独立边沿采集 MCU（10 路 GPIO/定时器 + FIFO）
        │ 3.3 V SPI，带 IRQ
        ▼
SmartPaddle ESP32-S3
        │
        ▼
现有 NetEvent / SmartPaddle 设备端 /ws / App
```

一个逻辑高度通道对应一只发射器和一只接收器；当前机械主线因此是 10 个光束、20 枚 M6 实物（10 发射 + 10 接收）。载板只采集 10 路接收端 BK，发射端 BN/BU 由受保护的传感器电源独立供电。

### 线束汇聚与载板尺寸边界

每只接收头仍是 `BN / BU / BK` 三芯，每只发射头仍是 `BN / BU` 两芯；线束在光学头侧完成整理/汇聚后，才在载板的连接器处插接。接收载板当前采用 `80 × 32 mm`、两排五路的集中式布局，发射电源板采用 `J_TX_A/J_TX_B` 两个 10 芯接口承接十路发射线束。M6 头之间的 `20 mm` 光学间距属于头部机械阵列和线束长度，不是 PCB 长度约束。所有板级线束连接器的物理节距统一按 `MX1.25`（1.25 mm）候选执行；原理图 `Conn_01xNN` 仅是逻辑符号，不代表 2.54 mm 排针。

载板 MCU 的唯一职责是：对 10 路隔离后的数字输入捕获上升/下降边沿、保存本地微秒时间戳、检测 FIFO 溢出，并通过 SPI 提供带 CRC 的事件帧。它不解释 `clean_over`、不计算高度，也不把传感器连接状态伪装成健康快照。

## 2. SmartPaddle 侧连接分配

SmartPaddle 参考 checkout 的 `pcb/lib/esp32s3wroom1/pinmap.py` 显示以下 GPIO 未被其当前项目绑定占用；机器可读候选保存在 [`firmware/main/m6_carrier_config.h`](../../firmware/main/m6_carrier_config.h)，仍需在最终 PCB 原理图和启动日志上复核：

| SmartPaddle GPIO | 载板信号 | 方向 | 说明 |
| --- | --- | --- | --- |
| GPIO10 | `CARRIER_SCK` | ESP32-S3 → 载板 | SPI mode 0；首样从 1 MHz 开始 |
| GPIO11 | `CARRIER_MOSI` | ESP32-S3 → 载板 | 事件读取事务填 `0x00`；时钟同步事务发送 `CLOCK_SYNC_REQUEST`，仍保持固定 152-byte 事务 |
| GPIO12 | `CARRIER_MISO` | 载板 → ESP32-S3 | 事件帧 |
| GPIO13 | `CARRIER_CS_N` | ESP32-S3 → 载板 | 每个事务重新对齐帧 |
| GPIO14 | `CARRIER_IRQ_N` | 载板 → ESP32-S3 | FIFO 非空/边界错误，开漏或 3.3 V 推挽按 PCB 定义 |
| GPIO5 | `CARRIER_RESET_N` | ESP32-S3 → 载板 | 低有效复位；上电默认保持复位 |
| GND | `CARRIER_GND` | — | 只允许 3.3 V 逻辑侧共地 |

GPIO19/20 的 USB、GPIO43/44 的 UART0、GPIO0/45/46 的启动脚和 GPIO35–37 的 N16R8 OPI PSRAM 不得改作载板信号。可重复审计命令：

```text
python3 tools/validate_smartpaddle_reference.py
```

当前审计会报告现有 Pingpang 直连占位与 SmartPaddle 的冲突；这正是选择独立载板的依据，不是让当前占位数组直接上板。

## 3. 事件帧协议

协议实现位于 [`firmware/main/m6_carrier_protocol.h`](../../firmware/main/m6_carrier_protocol.h) 和 `.cpp`；ESP32-S3 的固定最大帧 SPI master 位于 [`firmware/main/m6_carrier_spi.h`](../../firmware/main/m6_carrier_spi.h)/`.cpp`，载板侧的固定 FIFO/打包核心位于 [`firmware/carrier/m6_carrier_capture_core.h`](../../firmware/carrier/m6_carrier_capture_core.h)，MCU 无关的 SPI 从机事务边界位于 [`firmware/carrier/m6_carrier_spi_slave_transport.h`](../../firmware/carrier/m6_carrier_spi_slave_transport.h)。帧采用小端序：

| 偏移 | 长度 | 字段 |
| ---: | ---: | --- |
| 0 | 2 | magic `A5 5A` |
| 2 | 1 | protocol version `1` |
| 3 | 1 | type `EDGE_BATCH=1` |
| 4 | 2 | payload 长度 |
| 6 | 4 | 单调递增 `sequence` |
| 10 | 1 | `edge_count`，最多 16 |
| 11 | 1 | flags：bit0=`fifo_overflow`，bit1=`timestamp_invalid` |
| 12 | 2 | 保留，必须为 0 |
| 14 | 8 | `base_timestamp_us`，载板本地单调时钟 |
| 22 | N×8 | 每条记录：`channel:u8, level:u8, reserved:u16, delta_us:u32` |
| 22+N×8 | 2 | CRC-16/CCITT，覆盖 magic 到最后一条记录 |

解码边界和从机 TX 生命周期已经有主机测试：完整帧、逐字节分片、噪声重同步、CRC 损坏、通道越界、时间差越界、序号跳变、FIFO 溢出标志、同步请求/响应 CRC 与 t2/t3、对称事务时钟偏移估计、运行时多样本校准门、152-byte 预装缓冲和 CS 提前释放。主控适配层必须遵守：

1. 先做 CRC、长度、通道范围和序号连续性检查；
2. 用主控发出/收到时间戳与载板收到/发出时间戳做对称事务估计，再把载板时钟转换到 ESP32 `esp_timer` 单调时间域；协议实现提供 `m6_carrier_estimate_clock_offset()` 和 `M6CarrierClockCalibration`。运行时校准默认要求至少 3 个已完成且显式标记 `exchange_verified=true` 的交换、往返时间不超过 50 ms、offset spread 不超过 250 us、相邻样本时钟漂移不超过 500 us，并优先采用最低往返样本；真实载板仍需周期性复测漂移，不能直接把两个时钟当成同一个时钟；
3. 每条记录按原始 `level` 送入现有 `BeamCapture`，由最终 NPN/光耦实测极性决定 `blocked`；
4. `fifo_overflow`、`timestamp_invalid`、序号跳变、时钟同步失效或 SPI 帧损坏时，清空当前边界并让下一业务事件保持 `unknown`；
5. ESP32 master 的事件读取路径当前用 IRQ 触发一次最大 `152 bytes` SPI mode 0 事务（MOSI 填 `0x00`）；独立时钟同步路径则发送 `CLOCK_SYNC_REQUEST`，随后再读取 `CLOCK_SYNC_RESPONSE`。载板 SPI 从机应在拉低 IRQ 前预装对应 TX 缓冲，并保持到 CS 释放；主控再按类型、长度和 CRC 解码。不在 SPI 任务里生成 JSON 或决定高度，`beam_channel_map` 和 `NetEventAggregator` 仍是唯一业务解释层。

时钟同步不是事件帧里的隐含字段，而是独立的两个固定长度事务：

| 类型 | wire payload | 含义 |
| --- | ---: | --- |
| `CLOCK_SYNC_REQUEST=2` | 4 bytes | 载板收到完整请求后记录 `t2=carrier_received_us`，并准备下一事务响应 |
| `CLOCK_SYNC_RESPONSE=3` | 20 bytes | 载板在响应 CS assertion 时记录 `t3=carrier_sent_us`，返回 `t2/t3` 和有效标志 |

ESP32 master 的 `exchange_clock_sync()` 用请求开始的 `t1=host_sent_us`、响应事务结束的 `t4=host_received_us` 解码成一份 `M6CarrierClockSyncSample`；载板传输层、ESP32-S3 参考载板和 STM32G031 参考端口都已实现这个两事务生命周期。它解决的是代码/协议边界，不等于实板已经测得 SPI/IRQ 延迟、时钟漂移或最小有效脉宽。

当前 v0.1 的事件帧和独立同步事务代码均已实现，但 `firmware/main/m6_carrier_config.h` 中 `kCarrierClockOffsetConfirmed` 仍必须保持 `false`；主循环只有在 `exchange_clock_sync()` 或板级 `smartgear_board_read_m6_carrier_clock_sync()` 提供真实四时间戳，且 `M6CarrierClockCalibration::confirm()` 通过后才更新适配器 offset。弱 hook 默认返回不可用。校准失效或尚未确认时，ESP32 主循环会清空载板边界，不会生成有效高度事件；改变 offset 时也会丢弃旧时间域中的半截边界。实际选定 MCU、PCB、示波器/逻辑分析仪波形和漂移记录仍是现场放行门。

## 4. 板级首样输入

- 每一路 M6 BK 先按 [`m6-npn-interface-v0.1.zh-CN.md`](m6-npn-interface-v0.1.zh-CN.md) 经过独立输入电阻和光耦；不得让 10–30 V 到达载板 MCU；
- 每路保留 `TP_SENSOR_BK[n]`、`TP_OPTO_LED[n]`、`TP_CARRIER_IN[n]`；首样同时测传感器侧和载板侧边沿；
- 载板每路必须能在本地定时器中捕获双边沿，不能用“主控读一次 GPIO”推断没有漏脉冲；
- FIFO 深度、SPI 服务周期和线缆传播延迟必须以最坏 10 路同时变化、1–10 ms 参考脉冲实测；
- 最大 16 边沿帧为 `152 bytes`，SPI 纯传输时间在 `1 MHz` 下约 `1.216 ms`、`4 MHz` 下约 `0.304 ms`；这只是总线占用预算，不能替代载板本地捕获和 FIFO 深度实测；
- 输入电源、发射器电源和逻辑 3.3 V 分开去耦，传感器侧按 10–30 V 保护方案执行；
- 当前工程候选为 `STM32G031K8U6 / UFQFPN32`，具体 pin map 见 [`m6-capture-carrier-stm32g031k8-pinmap-v0.1.zh-CN.md`](m6-capture-carrier-stm32g031k8-pinmap-v0.1.zh-CN.md)；候选必须至少提供 10 路边沿输入、硬件定时器、SPI 从机、非易失校准版本和掉电安全复位。DMA/定时器寄存器绑定、最小启动/链接脚本和参考 ELF/bin 已完成源码/链接级检查，`daughter-boards-v0.2/m6-receiver-carrier-v0.2.kicad_pcb` 也已生成用于机械/端子/3D 包络；选型闸门、铜箔生产释放、实物波形和最终载板原理图仍未关闭。

## 5. 放行门

1. 空载 SPI 读写：CRC 正确、序号连续、复位后第一帧可识别；
2. 单路 1/2/3/4/5/6/8/10 ms 参考脉冲：传感器侧、光耦侧和载板事件时间戳一一对应；
3. 十路同时变化：无 FIFO 溢出、无丢帧、无错误通道；
4. 断开/短接/过压保护故障：载板上报边界错误，业务层输出 `unknown`；
5. 完成 SmartPaddle `/ws` 适配后，再按 [`bring-up-v0.1.zh-CN.md`](bring-up-v0.1.zh-CN.md) 执行逐路映射、健康快照和真实球体验收。

在上述证据完成前，本载板是“已有 KiCad 首样板框/器件/端子包络、可制造接口和可测试协议”，不是已验证的 M6 最小脉宽或真实球速性能结论。首样连接器、测试点、隔离器件位置和画板顺序见 [`m6-capture-carrier-first-article-bom-v0.1.zh-CN.md`](m6-capture-carrier-first-article-bom-v0.1.zh-CN.md)；当前 PCB 仍不等于完成布线、ERC/DRC 关闭和可下单生产板。

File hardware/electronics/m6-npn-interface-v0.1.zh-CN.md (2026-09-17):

# M6 十路 NPN 隔离前端参考设计 v0.1

状态：`参考电气拓扑和首样数值已冻结；最终光耦型号、传感器负载能力、常开/常闭极性和 PCB 引脚仍待卖家/实物确认`。

本文把 M6 直角对射器件的三线 NPN 输出接到隔离输入载板的边界具体化。针对 SmartPaddle 主板，光耦输出应进入 [`m6-capture-carrier-v0.1.zh-CN.md`](m6-capture-carrier-v0.1.zh-CN.md) 的本地边沿采集 MCU；“每路直连 ESP32 GPIO”只保留为台式单通道 bring-up 参考，不是 10 路最终接法。它不是把未知 SKU 当成已验证器件，也不是最终 PCB 原理图；首样应先做一条通道，再复制到 10 路。

## 1. 首选拓扑：每路光耦隔离

```text
传感器侧（10–30 V）                         MCU 侧（3.3 V）

      +V_SENSOR                                      3V3
          │                                           │
       R_IN 1.8 kΩ / 1 W                         R_PULL 4.7 kΩ
          │                                           │
          ├──► 光耦 LED ─── BK（M6 NPN 黑线）       CARRIER_IN[i]
          │                                           │
      BN=+V_SENSOR                              载板 GPIO/定时器输入
      BU=0 V_SENSOR                              光耦发射极
          │                                           │
      24 V 入口保护/保险                         GND_MCU
```

- 每个接收端黑线只驱动本路光耦 LED；不把 10–30 V 引到 GPIO。
- 光耦输出侧采用开集电极上拉，当前只把“遮挡为低”作为候选；`net_sensor_config.h` 中的 `kBeamPolarityConfirmed` 默认是 `false`，因此主循环会拒绝任何健康快照授权。只有卖家型号/常开常闭、光耦输入输出波形和逐路遮挡自检都确认后，才把 `kBeamPolarityConfirmed` 改为 `true` 并重新编译；若实测为高有效，则同时选择 `BeamInputPolarity::kBlockedHigh`，不能只改健康位图。
- 首样选用数据手册明确保证在约 5 mA LED 电流下 CTR、传播延迟和温度范围的工业光耦；`PC817` 不能仅凭型号名直接冻结，若其低电流 CTR/速度不满足就换高速逻辑光耦。
- 10 个接收输出必须分别进入 10 路光耦，不能把十路黑线并联成一个高度开关量；光耦后的双边沿时间戳由独立载板 MCU 捕获，不能由 SmartPaddle 主控低速逐路轮询替代。

## 2. 输入负载计算

以供应商资料中的 `10–30 V DC` 为设计范围、光耦 LED 正向压降保守取 `1.2 V`、`R_IN=1.8 kΩ ±1% / 1 W`：

| 条件 | LED 电流 | 电阻功耗 | 结论 |
| --- | ---: | ---: | --- |
| `10 V`、`R=1.818 kΩ` | 约 `4.84 mA` | 约 `0.043 W` | 首样必须选在此电流仍有明确 CTR 保证的光耦 |
| `24 V`、标称电阻 | 约 `12.67 mA` | 约 `0.29 W` | 推荐的 nominal 工作点 |
| `30 V`、`R=1.782 kΩ` | 约 `16.16 mA` | 约 `0.46 W` | 低于 1 W，仍需确认 M6 输出允许该负载 |

计算脚本：[`tools/validate_m6_interface.py`](../../tools/validate_m6_interface.py)。它会拒绝低于 4.5 mA 的最小 LED 电流、超过 20 mA 的最大 LED 电流、超过 0.5 W 的最大电阻功耗和过大的输入 RC 时间常数。

这里的 `150 mA` 只来自用户上传参数表的最大负载电流记录，不是卖家已确认的最终值；若卖家给出更低的允许负载，必须按卖家数据重算 `R_IN`，不能直接打样。

## 3. 载板/MCU 侧脉冲边界

- 首样 `R_PULL=4.7 kΩ`，每路 GPIO 前串 `100 Ω`，ESD/测试位置预留可选 `1 nF` 到 MCU 地；首轮短脉冲测试默认不装大电容。
- `4.7 kΩ × 1 nF = 4.7 µs`，相对 1 ms 最短测试脉冲约为 `0.47%`；它是抗尖峰的可选项，不是 5 ms 软件去抖。
- 任何硬件 RC、光耦传播延迟、GPIO 中断延迟都必须在传感器侧和 MCU 侧同时测量。不能用 `kBeamQuietUs=5 ms` 代替输出响应验收。
- 如果光耦在 1 ms 脉冲下漏检，先记录为接口失败；不要在固件中把脉冲延长或把漏检改写成有效高度。

## 4. 电源、连接器和测试点

### 传感器侧

- 每侧 10 个发射器和 10 个接收器的 BN/BU 由独立保险/限流后的传感器电源供电；总电流按 20 个实物铭牌和实测启动电流选电源，不能按光耦电流估算。
- 电源入口预留反接保护、保险丝或 PTC、`33 V` 级 TVS、`100 nF + 47 µF` 近端去耦；TVS 和电容耐压、浪涌能力按最终电源选择。
- 线束按 `TX/RX`、通道号、左右侧固定编号；接收端 BK 不与相邻通道共线。

### MCU 侧

- 验收通道表中的 `output_bit` 记录主控原始输入 bit；固件再通过 `kBeamLogicalIndexByInput` 映射到 `+10…+100 mm` 的逻辑高度。当前映射是 identity，连接到占位 `kBeamGpioPins[0…9]` 前仍必须做最终 PCB/SmartPaddle 冲突复核；实测线序不同就更新该 permutation 并重编译，不能只改 JSON。
- 每路至少留 `TP_SENSOR_BK[i]`、`TP_OPTO_LED[i]`、`TP_MCU_BEAM[i]` 三个测试点；首样用示波器同时探测 `TP_SENSOR_BK` 和 `TP_MCU_BEAM`。
- 传感器 0 V 与 MCU 地是否共地由隔离方案决定；光耦输出侧不应因为“方便测量”擅自把 10–30 V 接到 MCU 地或 GPIO。

## 5. 不允许的替代接法

```text
禁止：M6 BK ─────────────── ESP32 GPIO
禁止：把 10 个 BK 并联后接一个 GPIO
禁止：在未确认推挽/开集电极前，用 3.3 V 上拉直接替代隔离
禁止：用 5 ms 软件去抖掩盖光耦/传感器漏掉的短脉冲
```

只有卖家明确确认 BK 是开集电极、最大外部电压不会被施加到该节点、传感器与 MCU 共地方案通过 EMC/误接保护评审时，才可以把“每路 3.3 V 上拉 + 输入保护”的非隔离方案作为低成本备选；当前首样默认不采用。

## 6. 首样放行顺序

1. 不接 ESP32，先用可限流的 24 V 电源给一对 M6 供电，确认 BN/BU 极性和 BK 空载/负载状态；
2. 只装一个 `R_IN + 光耦` 通道，测 10 V、24 V、30 V 三个点的 LED 电流和电阻温升；
3. 用电子开关/不透光挡片施加 1、2、3、4、5、6、8、10 ms 参考脉冲，记录传感器侧与 MCU 侧边沿；
4. 通过 30 次重复、无额外脉冲、无漏检的通道后，再复制到 10 路；
5. 逐个接收端做通道映射、常开/常闭极性和启动自检，最后才把 `healthy_beam_mask` 与高度位图放行。

完整波形 CSV 格式和自动分析见 [`docs/m6-response-time-validation-v0.1.zh-CN.md`](../../docs/m6-response-time-validation-v0.1.zh-CN.md)。

## 7. 首样参考物料

| 物料 | 数量 | 备注 |
| --- | ---: | --- |
| 输入光耦（每路 1 个） | 10 | 需保证约 5 mA LED 电流下 CTR/速度；最终型号待选型 |
| `1.8 kΩ ±1% / 1 W` | 10 | 每个 BK 一只；根据卖家允许负载复核 |
| `4.7 kΩ ±1%` MCU 上拉 | 10 | 3.3 V 侧 |
| `100 Ω ±1%` GPIO 串联电阻 | 10 | 可放在 MCU 侧连接器附近 |
| `1 nF` 可选电容 | 10 | 首轮短脉冲测试默认 DNP |
| 33 V TVS、保险/PTC、100 nF、47 µF | 各若干 | 传感器电源入口及每侧去耦 |
| 10 路传感器连接器 + 10 路 MCU 连接器 | 各 1 组 | 线束先汇聚再插接；板级物理节距统一 MX1.25，通道号、左右侧和 TX/RX 防呆标记 |

本参考设计完成的是“安全接入和可测量边界”，不证明 M6 传感器本身的最小遮挡脉宽、输出数量或高速球体检出率；这些仍由实物证据关闭。

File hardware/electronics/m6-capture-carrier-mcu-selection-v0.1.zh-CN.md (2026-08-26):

# M6 十路边沿采集载板 MCU 选型与引脚预算闸门 v0.1

状态：`工程候选已选；STM32G031 无 HAL 参考固件已完成构建自检；MCU 量产放行、PCB 和实机载板证据仍 pending`。

本文件解决的是“可以开始画载板，但还不能把某个 MCU 伪装成已决定”的边界。机器可读的待确认清单见 [`m6-capture-carrier-mcu-selection.example.json`](m6-capture-carrier-mcu-selection.example.json)，可用下面的命令校验：

```text
python3 tools/validate_m6_carrier_mcu_selection.py
python3 tools/test_validate_m6_carrier_mcu_selection.py
```

## 1. 不可改变的载板契约

载板 MCU 不直接接收 M6 的 10–30 V NPN 输出；每一路必须先经过独立负载/光耦或等效隔离与 3.3 V 逻辑整形。MCU 只看到 10 路隔离后的数字输入，并负责：

- 对 10 路输入捕获上升沿和下降沿，不设置未经实测的去抖或最小脉宽过滤；
- 给每个边沿提供单调时间戳，目标时间分辨率为 `1 µs` 量级；
- 通过 3.3 V SPI 从机、mode 0、首样 `1 MHz`，发送预装的最大 `152 bytes` 事件帧；
- 在帧可读时拉低低有效 `IRQ_N`，接受主控低有效 `RESET_N`，并具备看门狗/安全复位；
- 保留可重复烧录、调试和首样测量入口，不能为了多挤出两根输入线而永久牺牲 SWD/JTAG/USB/UART；
- 把 FIFO 溢出、时间戳异常和复位原因显式报告给 ESP32-S3，不在载板上猜测球高或 `clean_over`。

当前主控侧 SPI/IRQ 候选分配、帧格式和 fail-closed 边界见 [`m6-capture-carrier-v0.1.zh-CN.md`](m6-capture-carrier-v0.1.zh-CN.md)。这里的 `152 bytes` 是已经实现并经主机测试的最大协议帧边界，不是说 MCU 必须用某一种 DMA API；具体实现要通过载板波形和最坏边沿突发验证。

## 2. 引脚和资源预算

| 资源 | 数量 | 属性 | 选型门 |
| --- | ---: | --- | --- |
| `CARRIER_IN[0..9]` | 10 | 隔离后的数字输入，双边沿时间戳 | 必须能处理十路同时变化；不能用单次轮询代替 |
| `SPI_SCK/MOSI/MISO/CS_N` | 4 | 3.3 V SPI 从机，mode 0 | 必须能在 CS 释放前保持预装 TX 缓冲 |
| `IRQ_N` | 1 | 载板 → ESP32-S3，低有效 | 中断产生和 SPI 帧准备顺序要能测量 |
| `RESET_N` | 1 | ESP32-S3 → 载板，低有效 | 上电默认安全、复位后首帧可识别 |
| `SWD/JTAG/USB 调试` | 至少 2 | 首样烧录、故障定位和固件更新 | 必须保留；不能只依赖一次性量产烧录 |
| `UART_TX/RX` | 0–2 | 可选日志/产测 | 推荐保留测试焊盘，必要时与调试接口复用 |
| `STATUS_LED` | 0–1 | 可选状态指示 | 仅用于 bring-up，不得占用关键输入 |

因此，必须 GPIO 预算是 `18` 根，带 UART、状态灯和产测余量建议按 `22` 根以上规划。这个数字只是接口数量预算，不等于某个封装可直接使用的 GPIO 数；最终还要排除电源、地、启动脚、晶振、调试复用、模拟专用脚和封装未引出的引脚。

时间资源同样要单独审计：至少需要一个自由运行的微秒计数基准、十路边沿捕获路径、SPI 从机接收/发送路径、FIFO 和看门狗。若采用“GPIO 中断读自由运行定时器”，必须用最坏十路同时边沿测量 ISR 延迟和乱序风险；若采用 PIO、定时器输入捕获或 DMA，必须把 FIFO 深度、溢出行为和调试日志一并验证。

## 3. 候选 MCU 对比

以下是进入首样评审的候选，不是采购指令：

| 候选 | 适合点 | 首样必须补的证据 | 当前倾向 |
| --- | --- | --- | --- |
| **RP2040** | 官方规格列出 30 个用户 GPIO、2 个 SPI 和 PIO；PIO 适合把十路并行输入做成确定性采集路径 | PIO 输入捕获程序、FIFO/DMA、SPI 从机预装 152-byte TX、复位/调试/量产烧录流程 | 倾向作为“时序优先”候选，未冻结 |
| **STM32G031K8** | ST 官方资料列出 Cortex-M0+、最高 64 MHz、64 KB Flash、8 KB RAM、DMA 和 SPI；`K8U6` 的 UFQFPN32 有足够的独立 EXTI 线和 SWD 余量 | 具体 `UFQFPN32` pinout、DMA/定时器分配、SPI 从机 TX 预装和 SWD 产测 | 当前工程候选，仍未量产放行 |
| **ESP32-C3** | 可复用 ESP-IDF、日志和 SPI 从机软件生态；官方 ESP-IDF 文档支持 SPI slave 和握手 GPIO | 152-byte 帧必须走 DMA；10 路输入的 ISR/FIFO 延迟、功耗/启动时间、无线功能是否值得引入 | 倾向作为“软件复用”候选，不是默认首选 |

RP2040 的 PIO 只是提供了值得验证的硬件路径，不代表本项目已经有可烧录的载板固件。STM32G031K8U6 的系列页面能力也不能替代选定封装的 pinout 审计。ESP32-C3 若不使用 DMA，官方文档的无 DMA 事务边界不足以直接承诺 `152 bytes`；不能因为主控侧已经是 ESP-IDF 就跳过这项验证。

官方资料入口：

- [Raspberry Pi RP2040 specifications](https://www.raspberrypi.com/products/rp2040/specifications/)
- [RP2040 datasheet](https://datasheets.raspberrypi.com/rp2040/rp2040-datasheet.pdf)
- [ST STM32G031K8 product page](https://www.st.com/en/microcontrollers-microprocessors/stm32g031k8.html)
- [STM32G031K8 datasheet](https://www.st.com/resource/en/datasheet/stm32g031k8.pdf)
- [Espressif ESP32-C3 SPI slave API](https://docs.espressif.com/projects/esp-idf/en/latest/esp32c3/api-reference/peripherals/spi_slave.html)

## 4. 选型放行顺序

1. **工程候选**：当前先以 `STM32G031K8U6 / UFQFPN32` 作为成本/简单度方向的工程候选；这不是已下单的量产决定。
2. **封装 pinout 复核**：具体分配见 [`m6-capture-carrier-stm32g031k8-pinmap-v0.1.zh-CN.md`](m6-capture-carrier-stm32g031k8-pinmap-v0.1.zh-CN.md) 和机器可读 JSON；仍需按实物封装、启动脚、电源、SWD 和 DMA 工程复核。
3. **采集路径原型**：用选定 MCU 的最小板或开发板验证十路同时边沿、双边沿时间戳、FIFO 溢出和复位后的首帧。
4. **SPI 从机原型**：验证 ESP32-S3 主控的 mode 0 / 1 MHz / 152-byte 事务；载板在 IRQ 前预装 TX，测量 IRQ 到 CS、CS 到首字节和帧保持时间。
5. **联合时钟验证**：实现独立同步交换，记录载板时钟到 ESP32 `esp_timer` 的 offset 和漂移；在证据写入验收包前保持 `kCarrierClockOffsetConfirmed=false`。
6. **冻结 PCB rev**：只有上述证据和成本/供货决定都完成，才把 `mcu_model`、`package`、`pcb_revision` 从 `pending` 改为具体值，并开始十路 PCB 首样。

## 5. 当前结论

现在可以按 `STM32G031K8U6 / UFQFPN32` 画最小原型、使用 [`firmware/carrier/stm32g031-reference/`](../../firmware/carrier/stm32g031-reference/) 的寄存器绑定/启动链参考镜像，并继续做协议、隔离前端和机械线束并行工作；仍不能声称“载板已能制造”或“参考镜像已在实板运行”。下一件硬件证据是用最小原型证明十路边沿采集和 152-byte SPI 从机事务。验收包的 `carrier_integration` 保持 `pending` 是有意的放行门，不是遗漏。

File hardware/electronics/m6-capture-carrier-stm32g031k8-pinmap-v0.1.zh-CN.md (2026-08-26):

# STM32G031K8U6 载板候选引脚表 v0.1

状态：`工程候选已选；寄存器绑定与参考 ELF/bin 已完成构建自检；PCB、DMA、波形和实机边沿证据仍 pending`。

这是从“候选列表”进入“可以画最小原型”的输入，不是量产放行。当前候选为 `STM32G031K8U6`，封装 `UFQFPN32`；机器可读版本见同目录的 `m6-capture-carrier-stm32g031k8-pinmap.example.json`，无 HAL 的端口生命周期外壳和可选 CMSIS 寄存器绑定见 [`firmware/carrier/stm32g031-reference/`](../../firmware/carrier/stm32g031-reference/)，校验命令为：

```text
python3 tools/validate_m6_carrier_stm32_pinmap.py
python3 tools/test_validate_m6_carrier_stm32_pinmap.py
```

官方依据：

- [STM32G031K8 产品页](https://www.st.com/en/microcontrollers-microprocessors/stm32g031k8.html)
- [STM32G031K8 数据手册](https://www.st.com/resource/en/datasheet/stm32g031k8.pdf)

数据手册给出该系列最高 `64 MHz`、`64 KB Flash`、`8 KB SRAM`、DMA、SPI 和 SWD；UFQFPN32 的 pinout 和 AF0 映射是本表的唯一引脚依据。`RESET_N` 直接接 `PF2-NRST`，不是把复位线冒充普通 GPIO。

## 1. 选择理由

- 10 路输入选用 `PA1/2/3/4/5/6/7/9/10/15`，对应 EXTI `1/2/3/4/5/6/7/9/10/15`，把 EXTI0 留给 CS；
- SPI1 使用 `PB0/PB3/PB4/PB5` 的 AF0，分别作为 `NSS/SCK/MISO/MOSI`，并把 `PB0/NSS` 映射到专用 EXTI0，保留固定 152-byte mode-0 从机事务；
- `PB8` 作为低有效 `IRQ_N`；`PA13/PA14` 保留 SWD；`PF2-NRST` 接主控低有效复位；
- 不为首样强行挤入 UART/状态灯，先保留 `PB1/PB2/PC6/PA12` 作为测试/后续扩展；SWD 是首样烧录和调试主入口；
- 采集实现仍采用“GPIO EXTI + 自由运行微秒定时器 + FIFO”，而不是轮询。十路同时边沿的 ISR 延迟、DMA 和 SPI TX 预装必须在最小板上实测后才能关闭选型闸门。

## 2. 载板引脚分配

| 信号 | MCU 引脚 | UFQFPN32 pin | EXTI/复用 | 方向 | 状态 |
| --- | --- | ---: | --- | --- | --- |
| `CARRIER_IN[0]` | `PA1` | 8 | EXTI1 | 输入 | pending |
| `CARRIER_IN[1]` | `PA2` | 9 | EXTI2 | 输入 | pending |
| `CARRIER_IN[2]` | `PA3` | 10 | EXTI3 | 输入 | pending |
| `CARRIER_IN[3]` | `PA4` | 11 | EXTI4 | 输入 | pending |
| `CARRIER_IN[4]` | `PA5` | 12 | EXTI5 | 输入 | pending |
| `CARRIER_IN[5]` | `PA6` | 13 | EXTI6 | 输入 | pending |
| `CARRIER_IN[6]` | `PA7` | 14 | EXTI7 | 输入 | pending |
| `CARRIER_IN[7]` | `PA9` | 19 | EXTI9 | 输入 | pending |
| `CARRIER_IN[8]` | `PA10` | 21 | EXTI10 | 输入 | pending |
| `CARRIER_IN[9]` | `PA15` | 26 | EXTI15 | 输入 | pending |
| `CARRIER_CS_N` | `PB0` | 15 | SPI1_NSS / AF0 + EXTI0 | 输入 | pending |
| `CARRIER_SCK` | `PB3` | 27 | SPI1_SCK / AF0 | 输入 | pending |
| `CARRIER_MISO` | `PB4` | 28 | SPI1_MISO / AF0 | 输出 | pending |
| `CARRIER_MOSI` | `PB5` | 29 | SPI1_MOSI / AF0 | 输入 | pending |
| `CARRIER_IRQ_N` | `PB8` | 32 | 普通 GPIO | 输出 | pending |
| `CARRIER_RESET_N` | `PF2-NRST` | 6 | 硬件 NRST | 输入/复位 | pending |
| `SWDIO` | `PA13` | 24 | SWD | 双向 | pending |
| `SWCLK` | `PA14` | 25 | SWD | 输入 | pending |

SmartPaddle 主控侧连接沿用 [载板接口文档](m6-capture-carrier-v0.1.zh-CN.md) 的 GPIO10/11/12/13/14/5 候选：`SCK/MOSI/MISO/CS_N/IRQ_N/RESET_N`。`RESET_N` 在主控侧必须以开漏或经过明确电平/复位器件驱动，不能让两个推挽输出相互顶住。

## 3. 还未放行的项目

1. 将已通过目标架构 compile-only 和参考 ELF/bin 链接自检的寄存器绑定、启动链和 PB0/EXTI0 CS 边沿接入最终 PCB，并证明 SPI1 从机 DMA 配置在 CS 期间不会替换 TX 缓冲；
2. 用 TIM2 或等效自由运行定时器完成 1 µs 量级时间戳，并测量十路同时边沿的 ISR 延迟、顺序和 FIFO 深度；
3. 测量 `IRQ_N → CS_N → 首字节 → CS_N release`，并完成复位原因/首帧/看门狗证据；
4. 画 UFQFPN32 首样 PCB，保留 SWD、每路 `TP_CARRIER_IN`、SPI/IRQ/RESET 测试点和隔离电源分区；
5. 未完成上述证据前，`kUseM6Carrier`、`kCarrierClockOffsetConfirmed` 和验收包 `carrier_integration` 继续保持关闭/pending。

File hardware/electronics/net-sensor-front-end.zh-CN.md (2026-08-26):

# 网顶传感器前端首轮实现说明

这是一份板级实现边界说明，不是已经冻结的 PCB 原理图或最终 BOM。具体放大器、保护器件、光电二极管和阈值必须以真实波形、环境光和通道串扰测试为依据。

## PVDF 双通道

每个 PVDF 夹片保持可拆卸，尽量只把网顶白边的动态振动耦合进传感器：

```text
PVDF
  ├─ 串联限流/钳位与输入保护
  ├─ 中点偏置
  ├─ 可调增益 + 带通滤波 ──→ ADC1 连续采样
  └─ 可调阈值比较器 ───────→ ESP32-S3 GPIO/中断
```

设计约束：

- PVDF 不用于测静态网张力；
- 比较器路径只负责低延迟候选触发，不能替代 ADC 波形证据；
- ADC1 初始为 16 kHz，20 ms 预触发、80 ms 后触发，每路最多 1600 点；
- 保护和偏置必须保证最大冲击不会把 ESP32-S3 ADC 输入推到危险电压；
- 左、右通道分别记录峰值、能量、持续时间和波形引用；
- 安静基线在启动自检和每次安装后采集，阈值从基线加裕量开始。

## 10 路 M6 NPN 光电输入

```text
M6 发射器 × 10 ── 对射光路 ── M6 接收器 × 10
                                      │ BN/BU/BK
                                 10 路 NPN 开集电极
                                      │
                           每路 R_IN + 光耦隔离
                                      │
                              3.3 V 上拉 + GPIO
```

- 每路独立输出，禁止用低速逐路轮询或把十路 BK 并联代替并行采集；
- 发射端只按卖家确认的 BN/BU 供电，接收端 BK 经过额定的 `R_IN + 光耦`，不得把 10–30 V 节点直接接 ESP32-S3 GPIO；
- 首样参考拓扑、`1.8 kΩ/1 W` 输入电阻、3.3 V 侧上拉、测试点和功耗边界见 [`m6-npn-interface-v0.1.zh-CN.md`](m6-npn-interface-v0.1.zh-CN.md)；
- 5 ms 只表示状态变化到输出完成变化的响应语义；1–10 ms 已知脉冲的输入/输出波形必须按 [`docs/m6-response-time-validation-v0.1.zh-CN.md`](../../docs/m6-response-time-validation-v0.1.zh-CN.md) 留档；
- 接收前端必须考虑环境光、球网白边反射、邻道串扰和光耦/线缆传播延迟；
- 每路都需要启动自检：发射端断开、接收端偏移、持续遮挡和正常对准至少要能区分；
- 光学座提供 z 轴偏航、y 轴俯仰和 x 轴滚转微调，参考线提供机械高度复核；
- 只有 `+10…+100 mm` 的 10 根有效光束参与业务事件。

## ESP32-S3 接口边界

本工程采用单个 ESP32-S3 主控，左右两侧通过线缆接入。`firmware/main/net_sensor_config.h` 中的 GPIO/ADC、RGB 和蜂鸣器引脚只是首轮占位映射，必须在最终 PCB 和 SmartPaddle 既有引脚约束确认后替换。

业务层不依赖 BLE、Wi-Fi、MQTT、SSE 或 WebSocket；通信层只消费序列化后的 `NetEvent`。SmartPaddle 的 WebSocket、配网、连接管理和 App 集成沿用既有基础设施，不在本仓库复制一套。

## 需要实测后冻结的项目

1. PVDF 夹片的机械预紧量与最佳贴合位置；
2. AFE 的输入保护、偏置电压、增益、带通频段和比较器迟滞；
3. 光电二极管有效距离、调制频率、接收增益和阳光/室内灯抗扰；
4. 10 根光束之间的串扰、实际球体遮挡宽度和 M6 5 ms 响应对应的最小输入/输出脉宽（按 [`docs/m6-response-time-validation-v0.1.zh-CN.md`](../../docs/m6-response-time-validation-v0.1.zh-CN.md) 留存波形）；
5. 采样缓存、GPIO 中断负载和最终板级引脚复用。

板级 hook、逻辑通道顺序、fail-closed 规则和可运行 CSV 回放见 [`docs/sensor-interface-v0.1.zh-CN.md`](../../docs/sensor-interface-v0.1.zh-CN.md)；实物装配、逐光束自检、PVDF 原始波形和断链补发按 [`docs/field-validation-record-template.zh-CN.md`](../../docs/field-validation-record-template.zh-CN.md) 留档；第一次接板按 [`bring-up-v0.1.zh-CN.md`](bring-up-v0.1.zh-CN.md) 顺序执行。

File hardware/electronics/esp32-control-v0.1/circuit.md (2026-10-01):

# 电路连接审查表 v0.2

本文、原生 [`esp32-control-v0.1.kicad_sch`](esp32-control-v0.1.kicad_sch) 和 `generate_board.py` 共同描述首样板；真正的网名和焊盘连接以生成的 `.kicad_pcb` 为机器可读基线。这里的 v0.2 是可打开、可审查的首样/放置网表，尚不是完成布线的量产原理图。

## 电源

| 区块 | 连接 | 备注 |
| --- | --- | --- |
| UI 面板 Type-C（唯一外部充电口） | `J_USB_PANEL VBUS → J_MOTHER/J7 pin13 usb_vbus → F1 → vbus_limited → U2.1 VIN`；pin14 `gnd` 返回 | F1 候选 PTC 1.1 A；充电专用，D+/D−/SBU 不接 |
| Type-C CC | UI 板 `CC1/CC2 → 各 5.1 kΩ Rd → gnd` | 让标准 USB-C 供电源识别为受电端 |
| 1S 电池 | `J2.1 bat_p → U2.6 BAT`；`J2.2 → gnd` | 仅带保护 1S 包 |
| 电池检测 | `bat_p → R5 1 MΩ → bat_sense → R6 1 MΩ → gnd`；`bat_sense → C1 100 nF → gnd` | GPIO9，估算用途 |
| 5 V | `U2.7 boost_sw ↔ L1 2.2 µH ↔ U2.8 sys_5v` | IP5305T 升压环路 |
| 3.3 V | `U3.2 sys_5v`，`U3.3 buck_en`，`U3.6 3v3`，`U3.7 buck_sw ↔ L2 2.2 µH`，`U3.5 FB → gnd` | TPS62162 固定 3.3 V 候选连接 |
| 按键/指示 | `U2.5 power_key ↔ SW1 ↔ gnd`；`U2.2 led_charge → R8 1 kΩ → D1 → gnd` | LED2/LED3 为 `ip_led2_nc/ip_led3_nc` |

## 外部接口

| 连接器 | 1 | 2 | 3 | 4 |
| --- | --- | --- | --- | --- |
| J3 传感器电源 | `sensor_ext` | `sensor_gnd` (`0V_SENSOR`) | — | 传感器域回路，不接 MCU `gnd` |
| J8 接收载板电源 | `sensor_fused` | `sensor_gnd` (`0V_SENSOR`) | — | 与接收载板 `J_PWR` pin1/pin2 一一对应 |
| J5 PVDF ADC | `pvdf_adc_l` | `gnd` | `pvdf_adc_r` | `gnd` |
| J6 PVDF 比较器辅助 | `pvdf_cmp_aux_l` | `pvdf_cmp_aux_r` | — | — |

J3 后面预留 F2 PTC 与 D2 33 V TVS。它只是 10–30 V 外部电源入口；`sensor_gnd`/`0V_SENSOR` 是独立的传感器回路，当前板没有把外部传感器黑线引到 ESP32 的 MCU `gnd`。J6 明确是辅助/DNP 接口，因为 GPIO14 已给 M6 载板 IRQ，不能在板上偷偷复用。

J8 是 J3 保护后的两芯 MX1.25 可插拔电源 hand-off，pin1/pin2 直接映射接收载板 `J_PWR` 的 `sensor_v`/`sensor_gnd`，和 J4 的 3.3 V 逻辑线分开。`sensor_gnd` 不应在主控板、线束或接收载板上误接 MCU `gnd`；是否采用真正隔离的 DC/DC 与屏蔽接地仍是首样电气放行门。接收载板上的十路 `J_RX00…J_RX09` 均为三芯 MX1.25 锁扣接口，发射端另有独立电源子板，并以 `J_TX_A/J_TX_B` 两个 10 芯 MX1.25 接口承接十路两线线束；现场线束不采用裸焊盘或飞线。这里的线束汇聚与插接位置不改变光学头的 20 mm 机械间距。

## J7 UI 子板

| J7 | 网名 | ESP32-S3 GPIO | UI 子板负载 |
| ---: | --- | ---: | --- |
| 1 / 2 | `3v3 / gnd` | — | OLED、按钮、LED、音频公共电源 |
| 3 / 4 | `ui_sda / ui_scl` | GPIO16 / GPIO15 | 0.96 英寸 I2C OLED 排线接口 |
| 5 / 6 | `ui_btn_start / ui_btn_mode` | GPIO3 / GPIO4 | 两个面板按钮 |
| 7 | `ui_buzzer` | GPIO8 | 蜂鸣器驱动 |
| 8 / 9 / 10 | `ui_spk_bclk / ui_spk_ws / ui_spk_dout` | GPIO6 / GPIO7 / GPIO17 | I2S 扬声器模块 |
| 11 / 12 | `ui_led_status / ui_led_battery` | GPIO18 / GPIO21 | UI PCB 上的 0603 单色直装指示灯 |
| 13 / 14 | `usb_vbus / gnd` | — | UI 面板 Type-C 的充电电源回路 |

## ESP32-S3 关键焊盘

| 模块焊盘 | 网名 | 功能 |
| ---: | --- | --- |
| 1 / 40 | `gnd` | 地 |
| 2 | `3v3` | 主电源 |
| 3 | `esp_en` | CHIP_PU |
| 5 | `carrier_reset_n` | GPIO5 |
| 4 / 7 / 8 / 9 / 10 / 11 / 12 / 13 / 16 / 23 | `ui_btn_mode / ui_spk_bclk / ui_spk_ws / ui_scl / ui_sda / ui_spk_dout / ui_led_status / ui_buzzer / ui_btn_start / ui_led_battery` | GPIO4 / GPIO6 / GPIO7 / GPIO15 / GPIO16 / GPIO17 / GPIO18 / GPIO8 / GPIO3 / GPIO21 |
| 17 | `bat_sense` | GPIO9 / ADC1_CH8 |
| 18…22 | `carrier_sck/mosi/miso/cs_n/irq_n` | GPIO10…14 |
| 27 | `boot` | GPIO0 启动脚 |
| 38 / 39 | `pvdf_adc_r / pvdf_adc_l` | GPIO2 / GPIO1 |
| 36 / 37 | `uart_rx / uart_tx` | 调试串口保留 |

GPIO35…37 的 OPI PSRAM/模块专用限制、GPIO0/45/46 启动约束和 USB/UART 引脚不能因下一轮布线方便而改变。

## 放行顺序

1. 在 KiCad 中把 `U1/U2/U3/J2/J3/J4/J7/J8` 换成已经核对过的厂商库封装；逐焊盘对照本表和数据手册。
2. 先布 USB/电池/5 V/3.3 V 电源环路，再布 J4 SPI/IRQ；天线禁布区保持原生 rule area。
3. ERC/DRC 关闭真实违规后，限流电源、空载/低电量/Wi-Fi/LED 工况逐项测量。
4. 电源与主控稳定后，再接独立 M6 载板，测 CS/IRQ/RESET 方向、1 MHz 首样事务和四时间戳同步。
5. y+ 侧 UI 采用一体式填平固定板从腔内安装，8 枚腔内自攻钉均匀固定；这里只要求面板齐平、无明显错台或松动，不把它写成 IP 防水等级。USB-C、按钮、屏和声学件均通过面板开口/硅胶帽/声学膜处理。

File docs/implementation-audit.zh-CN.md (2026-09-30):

# 乒乓智配首轮实现审计

本文只把当前仓库能够复核的结果写成已完成；主机测试、OpenSCAD 编译和 PCB 包络检查不替代实物、电气波形或生产释放。旧版离散光栅、网顶轨道、圆柱卡网件和独立外挂托架只保留在历史文件中，不属于当前主线。

## 当前主线结论

| 范围 | 当前可复核结果 | 仍需实物/生产证据 |
| --- | --- | --- |
| 机械源与装配 | [`hardware/cad/net_stand.scad`](../hardware/cad/net_stand.scad) 已包含完整球台截面、左右夹体/立柱、无网顶轨道的网布路径、PVDF 端部安装位、20 个 M6 外购件包络、M6 分体壳、球头、电子腔、y+ 一体式 UI 填平固定板和线缆导向。 | 网布真实厚度/张力、M6 SKU 实物尺寸、球头螺纹、线缆弯曲半径和装配对准。 |
| 夹体分体 | 左右 C 形夹按 y=0 分型为两半，斜立柱和绿色载体再在顶部下 `30 mm` 分成下段/上段；下段底面与 C 夹黄灰交界 `z=16 mm` 共面，上段延伸到 `z=260.5 mm`，不向下插入 C 形座；网布/圆柱功能区止于 `z=168.5 mm`。取消脚、裤裆、滑轨和外套圈；必要的网布过道和侧开接收腔仍保持功能开口。 | 实际打印间隙、共面落座插入力、反复拆装耐久和真实夹紧/网布张力下的变形。 |
| 立柱分件落座 | `post_clamp_carrier_lower` 承载绿色底座、网布过道和 Ø10 圆柱插杆侧开接收腔，`post_clamp_carrier_upper` 是顶部 `30 mm` 可替换段；两件 C 夹半体沿 y=0 分型面合拢，主板由两端夹件承托。下段底面与 C 夹最高承托面共面，上段带公母键、四个 `Ø3.4 mm` 通孔和中心 `Ø6.8 mm` 攻丝底孔，球头下端 M8×1.25 直接进入该座，四枚普通盘头/低矮圆头 M3×40 进入下段 `Ø2.4×10 mm` 导向盲孔；网布/圆柱功能区为 `z=16…168.5 mm`。 | 打印收缩、共面落座插入力、M8 攻丝/嵌件啮合、振动/倾覆/网布张力测试。 |
| 网布安装 | 网顶不设置轨道。网布从球台中心侧穿过两侧立柱的连续 `3 mm` 过道，端部止到立柱外表面；空心边套套到 Ø10 圆柱插杆后沿 x 推入下段侧开接收腔，立柱在距顶部 `30 mm` 处分成上下两段，由公母键和四枚普通盘头/低矮圆头 `M3×40` 连接；上段安装后封住入口。 | 网布白边实际厚度、张力、侧开接收腔防脱行程与释放手感、插杆推入力、螺钉啮合和长期疲劳。 |
| UI 面板与 M6 盖件 | 电子腔使用 y+ 一体式 UI 填平固定板；M6 前/后/底盖和线缆压紧件独立验证；目标是装后齐平、无明显错台或松动。 | 实物面板收缩、8 枚自攻钉固定强度、M6 盖件贴合和现场塞尺/纸条检查；不宣称 IP 等级。 |
| 打印包 | 导出脚本当前生成 `41` 个正式 STL：`37` 个 PETG、`4` 个 TPU/柔性。256 mm 拼盘为 `7` 张板、`41` 件已排版、`0` 件超尺寸；两件下段载体采用 `rx=0°、ry=51°、rz=45°` 三轴斜放，上段按分型面平放，并按当前排版清单复核。 | 切片器支撑/首层、G-code、打印机实际成形、材料和实物装配。 |
| ESP32/电子机械 | 已有 4 个原生 KiCad PCB/项目、4 个原理图 PDF、Atopile 接口合同、板级 STL/STEP、主控/接收/发射电源/UI 分板、左右内置电池、端子化线束、按钮/屏幕/指示灯/蜂鸣器/扬声器/USB-C 预留和统一 fit report。 | 铜箔布线、最终器件料号、ERC/DRC 生产门、升压峰值/温升/纹波、真实电池/连接器/波形和上电。 |
| 功能/协议 | M6 十路逻辑映射、SPI/IRQ/FIFO、PVDF 波形窗口、事件状态、断链缓存和 Atopile/主机回归链已有代码证据。 | 20 枚 M6 实物逐通道输出、NPN 极性/电平、光耦波形、左右光轴、真实球事件和 App/设备联调。 |

## 当前验证入口

```text
python3 hardware/cad/validate_net_stand.py
python3 hardware/cad/export_net_stand_printables.py --clean
python3 hardware/cad/build_print_platter.py --preset x1c-256 --clean
python3 hardware/cad/test_preview_consistency.py
python3 hardware/electronics/validate_system_fit.py
```

`validate_net_stand.py` 负责 OpenSCAD 参数探针、左右镜像、当前打印件编译/包络、分段斜立柱与 C 夹接触/装配合同、网布过道/Ø10 圆柱插杆侧开接收腔和四枚立柱分型螺钉合同、桌下免打孔路径以及组合诊断件。`validate_system_fit.py` 负责原生 KiCad 板框/安装孔/3D 模型、电子腔 AABB/布尔干涉、M6 载板竖放包络、Atopile/原理图和当前 `41` 件打印包摘要。

## 证据边界

- “KiCad 文件存在”证明板框、器件占位和接口可审查，不证明铜箔已经完成或可直接下 Gerber 生产单。
- “Atopile validate/build 通过”证明接口合同可解析，不替代原理图 ERC、PCB DRC、上电和波形。
- “STL watertight、拼盘 0 超尺寸”证明封闭几何和矩形排版，不证明首层、切片、打印强度或实际安装。
- “盒盖水密”在本项目中只表示盖合后无明显开缝/错台/松动，不是防水等级认证。

现场放行统一使用 [`validation-matrix.zh-CN.md`](validation-matrix.zh-CN.md) 和 [`field-validation-record-template.zh-CN.md`](field-validation-record-template.zh-CN.md)。没有照片、量具、示波器/逻辑分析仪或真实事件日志时，状态保持 `pending`。

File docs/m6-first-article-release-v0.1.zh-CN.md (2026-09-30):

# M6 45° L 型检测器首样加工与装配放行 v0.7

状态：`主体和传感器姿态已同步；壳体按 x 光学端/线缆端分段完成装配候选，等待单孔/十孔首样与真实接口证据放行`。

本文件只规定首样顺序。权威参数来自 [`hardware/cad/net_stand.scad`](../hardware/cad/net_stand.scad) 和机器清单 [`hardware/cad/export_m6_machining_spec.py`](../hardware/cad/export_m6_machining_spec.py)。

## 每侧清单

| 项目 | 数量/侧 | 处理 |
| --- | ---: | --- |
| `m6_machining_detector_body` | 1 | PETG 首样；简单矩形 `10×56×216 mm`，后续可按同一包络改 CNC；后盖 boss 不并入主体 |
| `m6_detector_shell_front` | 1 | x- 光学端正球弧前盖候选；首样后冻结 |
| `m6_detector_shell_rear` | 1 | x+ 线缆端后盖；x- 接驳边为直角，仅 x+ 后部两个角圆角；x+ 背面中央（y=0、z 中心）有加厚 boss、x 向 Ø7.0 1/4-20 通孔和隐藏捕获螺母；boss 根部 y± 各有一条避开中央孔的实体桥接肋，连接到后壳侧壁 |
| `m6_detector_bottom_cover` | 1 | Ø12 mm 统一套管过孔候选；按实物线束冻结 |
| `post_clamp_carrier_lower` + `post_clamp_carrier_upper` | 各 1 | PETG 斜立柱下段/顶部下 `30 mm` 上段；下段含网布门洞和 Ø10 圆柱插杆侧开接收腔，上段含公母键、四枚 `Ø3.4 mm` 通孔和中心 `Ø6.8 mm` 攻丝底孔；四枚普通盘头/低矮圆头 `M3×40` 进入下段 `Ø2.4×10 mm` 导向盲孔；不再另设 U 形卡网夹 |
| 13 mm 采购球头 | 1 | 外购件，不打印、不加工；上端固定 1/4-20 外牙；下端当前默认选 M8×1.25 外牙，直接拧入固定网柱上段中心攻丝座 |
| M6 L 型对射器件 | 10 | 外购件；高度 `+10…+190 mm`，节距 `20 mm` |

## 首样放行顺序

1. **实物测量**：记录 M6×0.75 有效外丝、头部六角对边、水平总包络和 14 mm 外丝段、光学中心偏置、原配螺帽厚度、蓝色尾线出口和最小弯曲半径。
2. **单件试装**：验证主体 `10 mm` 名义厚度不超过 `14+2−5−1=10 mm` 的当前首样限制；后方浅 AF8、深 `2.1 mm` 六角窝只防晃，不遮住六角/外丝接驳平面；确认水平光学/外丝轴朝球台中心，蓝色尾线先沿局部 `z-` 再绕 x 轴 `-45°` 斜向让位；M6 外丝直接穿出主体，由朝台内平滑面的一枚原配螺帽锁紧，固定螺丝不嵌入主体。
3. **完整主体**：逐孔确认 10 个 `20 mm` 节距通道（`+10…+190 mm`）的中心高度、光学面水平朝球台中心、光学/外丝轴沿 x、尾线 45° 斜向后让位、左右件为 x 镜像；禁止把旧版 y 交错梳齿条装到当前主体。
4. **壳体放行**：当前 x- 前盖为正圆弧、x+ 后盖仅后部两个角圆角且 x- 接驳边为直角，并在背面中央形成加厚 1/4-20 boss；boss 根部 y± 两侧各有避开中央 Ø7 孔的实体桥接肋；底盖采用同一组合俯视轮廓；主体单孔和十孔姿态验收通过后，根据真实六角、尾线和球头接口冻结沉头孔、共享边槽/分体舌、boss 孔和底盖线缆孔。
5. **采购球头**：球头本体保持竖直，商品上端固定的 1/4-20 外牙沿 x 穿入后盖 boss 并由隐藏螺母锁紧；z− 接口向下，M8×1.25 外牙直接拧入固定网柱上段中心攻丝座；检测器/球头总成沿 x 对正立柱中心，取消横向适配臂；确认球头锁紧后承担偏航、俯仰、旋转微调，实物验证攻丝/嵌件、啮合深度与弯矩承载。
6. **网架立柱接口**：实测商品网夹安装面、立柱总高与分型面球头承座高度、球头 z− 有效啮合长度、夹具向外伸出量、垫片和周边净空，确认蓝色检测器总成通过 M8×1.25 直连座落到立柱中心承座；当前取消横向适配臂和独立连接器。立柱下段/绿色载体从桌外侧沿 x 滑入夹体内段母槽，燕尾肩承力、M4 只防滑脱；再把顶部 30 mm 上段沿 z 对准分型面滑入，用公母键定位和四枚普通盘头/低矮圆头 `M3×40` 从上段通孔拧入下段 `Ø2.4×10 mm` 导向盲孔。网布先从球台中心侧穿过下段 `3 mm` 过道并止到立柱外表面，把空心边套套到 Ø10 圆柱插杆后沿原门洞轴线从 x 侧推入下段侧开接收腔，最后安装上段封住入口。
7. **光学微调**：球头锁紧前，从低/中/高三个通道分别调偏航、俯仰和滚转，使左右 10 条光束对应；锁紧后再次复核，记录回差和保持性。
8. **电气验收**：NPN 黑线先进入光耦/晶体管电平转换，不直接接 ESP32-S3；逐路记录对准、遮挡、发射端断电、接收端偏移和邻道遮挡波形。供应商所说的 5 ms 是状态变化到输出完成变化的响应时间，不是必须连续遮挡 5 ms 才检测。

## 退回条件

- 有效螺纹或螺帽厚度不满足主体厚度契约；
- 六角窝太深，无法让六角/外丝接驳平面贴靠主体沉孔平面；
- 盖件槽/舌无法从上方装入，或沉头螺丝侵入光学孔/线缆孔；
- 后盖 boss 的 1/4-20 孔与采购球头固定上端不同轴，或固定网柱上段中心 M8×1.25 攻丝座与球头下端外牙不匹配；
- 球头螺纹版本、旋钮净空、竖直姿态或网夹接口与 CAD 假设不一致；
- 任一通道只能靠打印件摩擦固定，或球头锁紧后出现明显漂移；
- NPN 极性、输出脉宽、最小有效输入脉宽没有原始示波器/逻辑分析仪证据。
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

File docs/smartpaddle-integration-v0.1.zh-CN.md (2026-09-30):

# SmartPaddle 复用与接入边界 v0.1

> 当前硬件已切换为用户指定的 M6 直角十路光电器件阵列 + 10×56×216 mm PETG 长条主体/后盖 x 背面中央加厚 1/4-20 boss + 竖直采购球头；球头下端 M8×1.25 直接进入固定网柱上段中心攻丝座。本文提到的 10 路光栅位图和 GPIO 只是业务契约背景；在 M6 NPN 输出数量、电流、接口保护和最终引脚确认前，ESP32-S3/App 不得把机械十个通道位置当作已冻结的物理接口或有效高度数据。
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

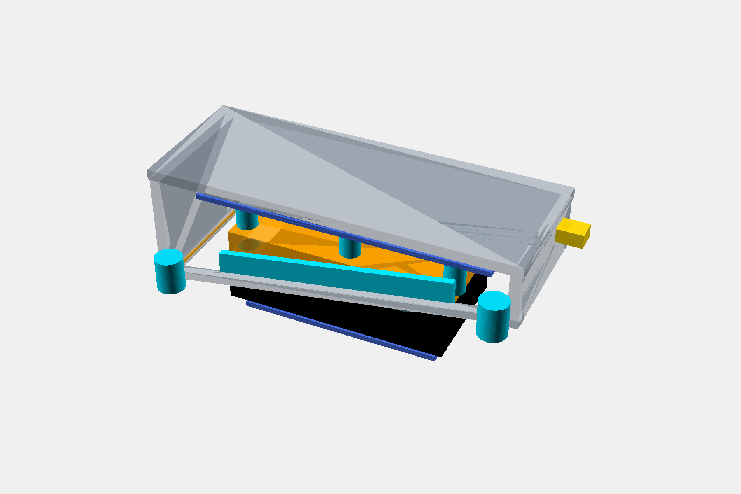
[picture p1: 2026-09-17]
hardware/cad/review/electronics-full-cutaway-daylight.png

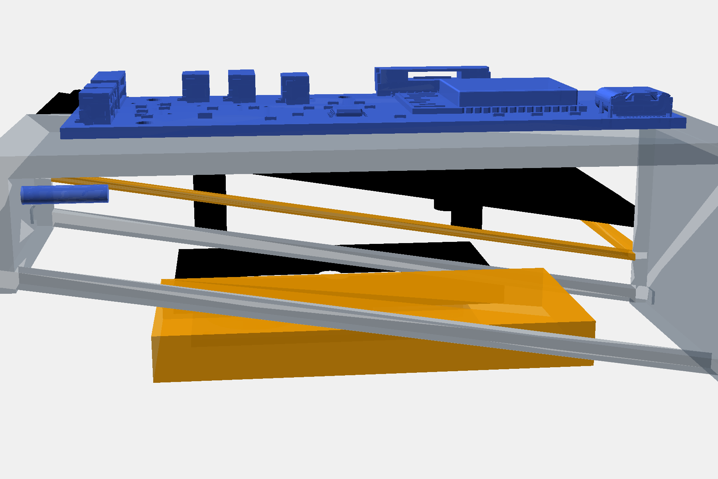
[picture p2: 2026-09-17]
hardware/cad/review/electronics-right-exploded-low.png

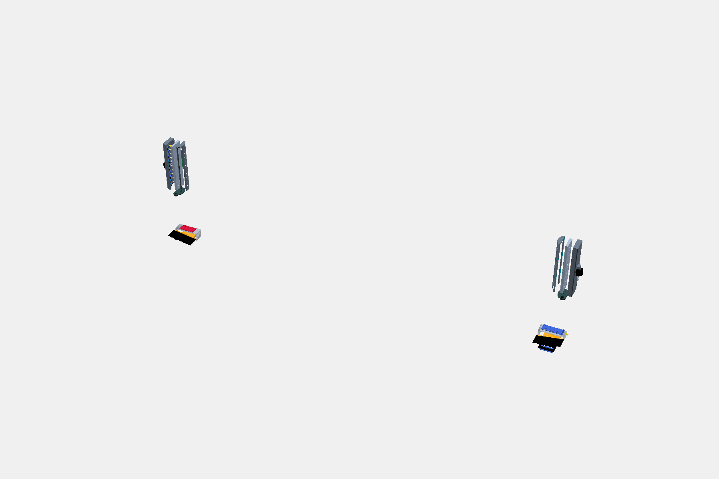
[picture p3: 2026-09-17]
hardware/cad/review/electronics-system-exploded.png

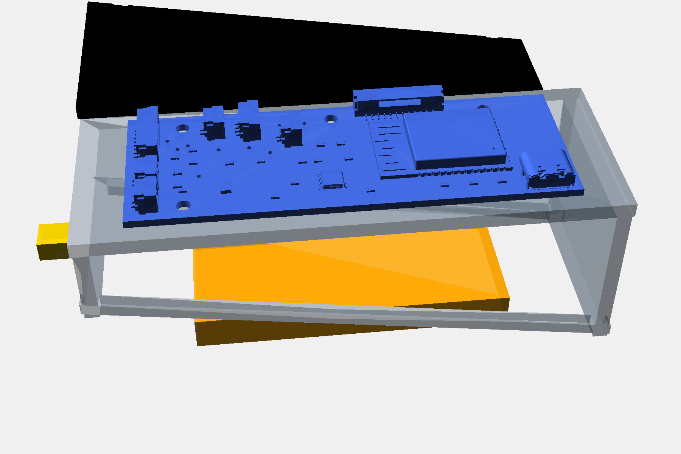
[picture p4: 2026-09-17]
hardware/cad/review/electronics-right-exploded-rear.png

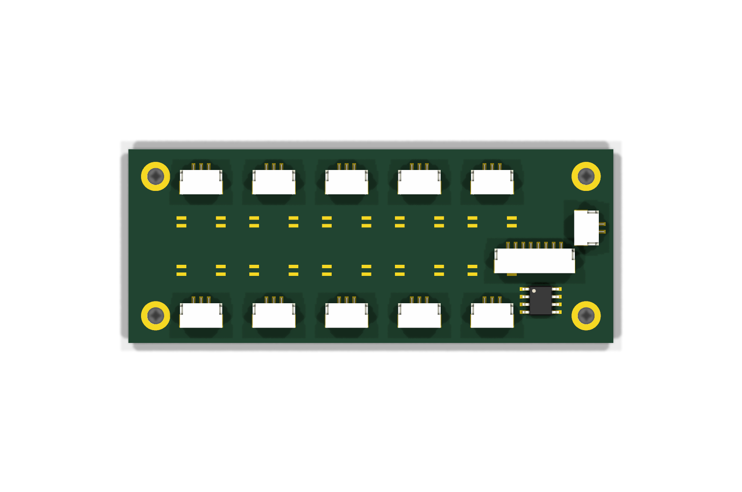
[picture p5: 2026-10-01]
hardware/electronics/daughter-boards-v0.2/m6-receiver-carrier-v0.2-top.png

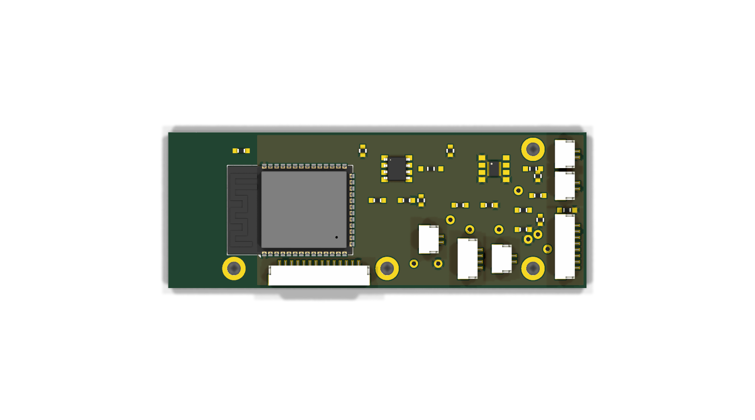
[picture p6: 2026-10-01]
hardware/electronics/esp32-control-v0.1/esp32-control-v0.1-top.png

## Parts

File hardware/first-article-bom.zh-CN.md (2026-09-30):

# 乒乓智配首样采购与装配清单 v0.4

本文服务于第一套“替换传统球网”的实体样机。打印件数量以 [`cad/print-manifest.zh-CN.md`](cad/print-manifest.zh-CN.md) 和导出 `manifest.json` 为准；这里区分打印件、标准紧固件、外购器件和仍需实测的项目。

## 1. 打印件

由 [`cad/net_stand.scad`](cad/net_stand.scad) 导出当前 `41` 件正式包：`37` 件 PETG、`4` 件 TPU/柔性。当前 256 mm 拼盘结果为 `7` 张板、`41` 件已排版、`0` 件超尺寸；斜立柱下段/绿色载体采用 `rx=0°、ry=51°、rz=45°` 三轴斜放，上段按分型面平放，按当前 X1C 排版清单复核支撑和首层。正式矩阵包括：

| 打印件 | 数量 | 作用 |
| --- | ---: | --- |
| `post_clamp_carrier_lower`、`post_clamp_carrier_upper` | 各 2 | 斜立柱下段/顶部下 `30 mm` 上段；下段含绿色底座、连续 `3 mm` 网布过道和 x 侧开圆柱接收腔，上段含公母键、四枚 `Ø3.4 mm` 通孔和中心 `Ø6.8 mm` 攻丝底孔供 M8×1.25 球头直连；两段在 `z=230.5 mm` 分型并用普通盘头/低矮圆头 M3×40 自攻钉连接 |
| `clamp_body_half_user`、`clamp_body_half_opponent` | 各 2 | y=0 分型的操作者侧/对手侧 C 形夹半体；合拢形成完整桌下 C 形固定主体和梯形电子腔，主板由两端 `[`/`]` 夹件承托，不再使用旧整件夹体 |
| `clamp_electronics_ui_panel_mount` | 2 | y+ 外侧齐平 UI 填平固定板；面板、腔内 72×42 mm 搭接法兰、捕获环和 8 个通孔融合为一件，从腔内装入并用 2 mm 蘑菇头自攻钉固定 |
| `m6_detector_body`、前盖、后盖、底盖、底盖 gasket、cable gland | 各 2 | 左右十路 M6 发射/接收壳体；主体包络 `10 × 56 × 216 mm` |
| `net_clamp_rod` | 2 | 独立 `Ø10 mm × 152.5 mm` 圆柱插杆；平放打印，先穿过球网空心边套，再沿原门洞轴线从 x 侧推入下段侧开接收腔 |
| `clamp_pressure_pad`、`clamp_printed_screw`、`clamp_body_nut`、`clamp_knob`、`clamp_knob_nut` | 各 2 | 台底压块、12 mm/4 mm PETG 锥形粗牙螺杆（2 mm 牙根/2 mm 凹槽/0.4 mm 锥尖）、固定螺母、旋钮和每侧两枚对锁螺母 |
| `sensor_mount_body`、`sensor_clamp_lip` | 各 2 | 网端 PVDF 座和可拆压片 |
| `calibration_gauge` | 1 | 过网高度标定规 |

正式清单不包含网顶轨道、轨道拼接片、传统圆柱卡网件、旧立柱套筒/内芯或历史外挂光学载台。旧名字只可用于回溯诊断，不能混入本次打印包。

## 2. 机械标准件和网布

| 物料 | 数量 | 当前接口和作用 | 状态 |
| --- | ---: | --- | --- |
| M4 连接螺钉 + 螺母 | 4 套 | 绿色整体底座推入灰色让位腔后的接口锁紧；钢珠只定位，不承主载荷 | 首样采购 |
| M5 分型面螺钉 + 六角螺母 | 18 套 | 每只 C 夹 9 处横向连接；只在电子仓空腔边界使用 boss | 首样采购 |
| M4×30 螺钉 + 螺母 | 0 | 当前斜立柱上下段与固定 C 夹不使用旧版滑轨防滑脱件；若首样另需定位件，必须单独复核，不计入当前正式结构 | 不进入当前打印/装配主线 |
| 4 mm 钢球 + 3 mm 短压簧 + 保持头 | 0 | 当前版本不使用旧版滑轨咯噔定位件 | 不进入当前打印/装配主线 |
| 真实乒乓球网/网布及白边 | 1 套 | 先把空心边套套到 Ø10 圆柱插杆，再从球台中心侧穿过立柱 `3 mm` 网布过道并沿 x 推入侧开接收腔 | 待实物确认 |
| 台面上侧 TPU/硅胶保护片 | 2 | 粘贴在固定上夹板与桌面之间，防滑和保护台面 | 现场裁切 |
| 台底薄软垫 | 2 | 可贴在台底压块接触面；压块主体仍是刚性 PETG 试样 | 按目标台面确认 |

立柱与 C 夹的承力原则：

- 固定灰色完整 C 形主体除网布/边套过道外保持实心；`post_clamp_carrier_lower` 的底面直接落座到 C 夹黄灰交界 `z=16 mm`，上段在 `z=230.5 mm` 与下段分型并延伸到 `z=260.5 mm`；网布/圆柱插杆功能区止于 `z=168.5 mm`，不向下插入 C 形座。
- 从 `z=16 mm` 承托面向上 `30 mm`（至 `z=46 mm`）做封闭实心连续渐变，底端 `35×58 mm` 收至 `28×38 mm` 顶端截面；立柱本体没有上下接缝、脚、裤裆、滑靴或外套圈，也不切固定网柱顶端 M8 直连孔。
- 结构载荷由连续立柱实体、C 夹固定基台和桌下夹紧路径承担；网端由套在 Ø10 圆柱插杆上的空心边套定位，圆柱插杆沿 x 推入下段侧开接收腔并由上段封住入口；网布张力、插杆和立柱实体的实际承载仍需首样确认。

## 3. 传感器和电子样件

| 物料/模块 | 数量 | 接口边界 |
| --- | ---: | --- |
| PVDF 压电薄膜片 | 2 | 左右网端各 1，装在可拆座和压片内；只能做动态振动采集 |
| M6 直角对射 NPN 发射/接收器 | 20 | 左右各 10；按 `+10…+190 mm`、`20 mm` 节距布置；最终后缀、供电和有效螺纹待卖家/实物确认 |
| ESP32-S3 主控/1S 电源母板 | 1 | KiCad `86 × 32 mm` 两层候选板；梯形腔内 4 个 M2.5 安装孔；USB-C、3.3 V、电池采样、PVDF ADC、SPI/IRQ 和 UI 接口，板级线束接口按 MX1.25 |
| M6 十路接收载板 | 2 | 左右各 1；当前 KiCad 候选为 `80 × 32 mm` 两层板，10 路光耦隔离输入/本地边沿/FIFO，经 MX1.25 锁扣主控口输出 SPI/IRQ；不按 20 mm 光学间距拉长 PCB |
| 发射端电源子板 | 1 | KiCad `68 × 32 mm` 两层候选板；默认内置受保护 1S 电池升压供十路发射器；另留可插拔 `EXT_TX_IN` 外接接口，十路线束由两个 MX1.25 10 芯段接入 |
| 受保护 1S 电池包 | 2 | 主控腔 1 个、发射端 1 个；按少器件的一端放置，使用带防呆锁扣端子 |
| UI 子板 | 1 | KiCad `58 × 28 mm` 两层候选板；`START/MODE` 按钮、0.96 英寸 I2C OLED 预留、状态/电量灯、蜂鸣器、扬声器和 USB-C 面板接口 |
| 13 mm 采购球头 | 2 | 竖直安装；上端 1/4-20、下端默认 M8 外牙，具体有效长度按到货确认 |

全部现场线束必须采用锁扣对插、可插拔螺钉端子或压接端子；不允许裸焊盘飞线。M6 线束按 `RX00…RX09` / `TX00…TX09` 标签分组，外部电源和电池均采用防呆端子。

## 4. 首样装配顺序

1. 按 manifest 打印并检查左右两片 C 夹半体、斜立柱下段/上段、UI 一体式填平固定板、M6 壳体、圆柱插杆、PVDF 件和夹紧件；先不装网布和通电器件，使用目标台厚样块确认 C 形夹开口、压块和粗牙螺杆行程。
2. 将左右 `clamp_body_half_user` 与 `clamp_body_half_opponent` 在 y=0 分型面合拢并固定到目标球台边缘，再装入 `post_clamp_carrier_lower`，把 `post_clamp_carrier_upper` 滑入 `z=230.5 mm` 分型面并用四枚普通盘头/低矮圆头 M3×40 自攻钉连接；确认立柱底面与 C 夹承托面 `z=16 mm` 共面，实体到 `z=260.5 mm`，网布/圆柱功能区止于 `z=168.5 mm`，且没有下插段、旧版滑轨、滑靴或额外防滑脱件。
3. 确认上下立柱分件的公母键、四枚 M3×40 螺钉和上段中心 M8×1.25 攻丝座；网布通道在下段，球头下端直接由该座承载。
4. 把球网侧边空心布套套到 `Ø10 mm × 152.5 mm` 圆柱插杆上，从球台中心侧把这套组件穿过立柱的 `3 mm` 网布过道，再沿原门洞轴线从 x 侧推入下段侧开接收腔；确认插杆落座并保持入口可由上段封住，随后安装上段捕获圆柱。实际布套内径、插杆材料和推入力需首样实测。
5. 安装两侧十路 M6 器件、接收载板、发射电源子板和两只受保护电池；按 `RX/TX` 标签接入端子，检查线缆弯曲、应力释放和左右发射/接收方向。
6. 安装 PVDF 薄膜/压片、主控板和 UI 子板；将左右一体式 `clamp_electronics_ui_panel_mount` 从腔内 y- 侧推入 y+ 侧窗，再从腔内拧入 8 枚 2 mm 蘑菇头自攻钉。检查按钮、屏幕窗口、指示灯、声学窗口和 USB-C 碗槽，确认无明显贯穿缝、错台或翘边。
7. 按电子 bring-up 文档完成断电检查、限流上电、M6 输出、PVDF 基线、SPI/IRQ 和电池采样记录。任何健康门失败时，系统状态保持 `unknown`。

## 5. 尚不能由 CAD/BOM 证明的项目

- PETG 夹体在真实夹紧力、网布张力和反复拆装下的滑移/变形/耐久；
- 立柱与固定 C 夹的实际打印配合间隙、落座稳定性、侧开接收腔的防脱可靠性和圆柱插杆耐久；
- 盒盖压合件的打印收缩、胶条压缩量、实际线缆弯曲半径和盖面开口贴合；
- 电池容量、升压峰值电流、温升、M6 供电/输出语义、光耦波形和最终铜箔 DRC/ERC；
- 真实球台厚度、网布白边厚度、网高、左右平行度以及光轴对准。

这些项目须记录照片、量具、示波器/逻辑分析仪或实物装配结果后再改为 `PASS`。当前“水密”只代表盒盖装好后严丝合缝，不代表 IP 防水等级。

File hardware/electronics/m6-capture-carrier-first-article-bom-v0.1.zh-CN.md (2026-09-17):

# M6 十路边沿采集载板首样 BOM 与画板输入 v0.1

状态：`首样接口/BOM 输入已整理；STM32G031K8U6/UFQFPN32 有无 HAL 参考 ELF/bin，连接器物理节距冻结为 MX1.25（1.25 mm），准确厂家/料号、光耦型号和 PCB 铜箔仍未冻结`。

本文件是给画板和首样采购使用的边界，不是可直接下单的最终 BOM。当前仓库已经有 `daughter-boards-v0.2/m6-receiver-carrier-v0.2.kicad_pcb/.kicad_pro` 和板级 3D 导出，但仍没有独立的最终载板原理图/铜箔生产释放；在真实 M6 型号、光耦时序和 MCU 封装确认前，不能把首样放置板冒充制造数据。

关联输入：

- [`m6-npn-interface-v0.1.zh-CN.md`](m6-npn-interface-v0.1.zh-CN.md)：每路 NPN 隔离拓扑和电流/功耗边界；
- [`m6-capture-carrier-v0.1.zh-CN.md`](m6-capture-carrier-v0.1.zh-CN.md)：ESP32-S3 侧 SPI/IRQ、帧协议和载板职责；
- [`m6-capture-carrier-mcu-selection-v0.1.zh-CN.md`](m6-capture-carrier-mcu-selection-v0.1.zh-CN.md)：MCU 候选、封装和 GPIO/时序放行门；
- [`m6-capture-carrier-stm32g031k8-pinmap-v0.1.zh-CN.md`](m6-capture-carrier-stm32g031k8-pinmap-v0.1.zh-CN.md)：当前工程候选的具体 pin map 和 EXTI 约束；
- [`../../firmware/carrier/esp32s3-reference/`](../../firmware/carrier/esp32s3-reference/)：可编译的 ESP32-S3 载板平台参考，不是生产板冻结；
- [`../../docs/m6-first-article-release-v0.1.zh-CN.md`](../../docs/m6-first-article-release-v0.1.zh-CN.md)：机械首样、网夹和 M6 实物放行顺序。

## 1. 电气分区和承诺边界

```text
J_PWR  V_SENSOR 10–30 V ── fuse/PTC ── TVS ── sensor distribution
                                      │
J_RX[0..9]  BK ── R_IN ── optocoupler LED   optocoupler transistor ── CARRIER_IN[0..9]
TX00..TX09  BN/BU ── sensor power only       3V3 + R_PULL + R_GPIO ── MCU

MCU 3V3 domain ── SPI_SCK/MOSI/MISO/CS_N + IRQ_N + RESET_N ── J_HOST ── ESP32-S3
                                  │
                               J_DEBUG / test points
```

- `V_SENSOR` 与 `V_LOGIC=3.3 V` 分区布线；10–30 V 只允许出现在传感器/光耦 LED 侧。
- 每一个接收器 BK 单独进入一只光耦；禁止十路并联、禁止把 BK 直接接 ESP32-S3 或载板 MCU。
- 发射器只需要 BN/BU 受保护供电，不进入边沿采集 MCU；接收器使用 BN/BU 供电并把 BK 送入独立输入通道。
- 光耦输出默认按开集电极 `3V3 → R_PULL → CARRIER_IN`；“遮挡为低”仍只是候选，最终极性必须以实物波形和卖家后缀确认。
- 载板 MCU 不负责高度、球状态或 WebSocket，只负责双边沿时间戳、FIFO、CRC 帧和边界错误。

## 2. 连接器和测试点命名

通道编号固定从低到高：`CH00=+10 mm` 到 `CH09=+100 mm`。左右两侧各自保持同样顺序；左右侧在线束标签中增加 `L/R`，不能靠线缆颜色猜通道。

| 位号/命名 | 数量 | 引脚/信号 | 首样要求 |
| --- | ---: | --- | --- |
| `J_PWR` | 1 | `V_SENSOR`, `0V_SENSOR` | 2-pin MX1.25 载板电源口；屏蔽/PE 如需处理走独立机壳端接，不作为第三个 PCB 信号；首样测启动峰值与压降 |
| `J_RX00…J_RX09` | 10 | `BN`, `BU`, `BK` | 每个接收器独立 3-pin；通道号永久印在丝印/线标 |
| `J_TX_A/J_TX_B` | 2 | `BN`, `BU` × 5 路/接口 | 物理为两组 10-pin MX1.25；承接逻辑通道 `TX00…TX04` 与 `TX05…TX09`，不把发射/接收插座混用 |
| `J_HOST` | 1 | `3V3`, `GND`, `SCK`, `MOSI`, `MISO`, `CS_N`, `IRQ_N`, `RESET_N` | 推荐锁定或带防呆 2×5/1×8；SPI mode 0、首样 1 MHz |
| `J_DEBUG` | 1 | 具体按 MCU：SWD/JTAG/USB/UART | 即使量产不留，也必须为首样保留可探测焊盘 |
| `TP_SENSOR_BK00…09` | 10 | 每路传感器侧 BK/负载节点 | 与 `TP_OPTO_LED` 同时探测，不接 MCU 地以外的错误参考 |
| `TP_OPTO_LED00…09` | 10 | 光耦 LED 电流/回路节点 | 用于 10/24/30 V 电流和温升验证 |
| `TP_CARRIER_IN00…09` | 10 | 3.3 V MCU 输入 | 与逻辑分析仪地和 MCU 侧参考一致 |
| `TP_SPI_* / TP_IRQ / TP_RESET` | 至少 6 | SPI 四线、IRQ、RESET | 必须能在不拆板时测量 IRQ 到 CS、帧保持和复位 |

`J_HOST` 的信号方向与 SmartPaddle 侧一致：ESP32-S3 输出 `SCK/MOSI/CS_N/RESET_N`，载板输出 `MISO/IRQ_N`；两侧只共 3.3 V 逻辑地，不把 `0V_SENSOR` 是否与 MCU 地相连写成默认结论，按实际隔离/电源方案审查。

## 3. 首样参考 BOM

数量是“一块十路载板”的参考数量；`待选型` 不是可采购料号。画板时每个 `DNP` 位置必须保留焊盘和丝印，不得为了省位置删除短脉冲实验能力。

| 类别 | 参考位号 | 数量 | 规格/边界 | 状态 |
| --- | --- | ---: | --- | --- |
| 输入限流 | `R_IN00…09` | 10 | `1.8 kΩ ±1% / 1 W`；按卖家允许负载重算 | 参考值，待 M6 确认 |
| 输入隔离 | `U_OPTO00…09` | 10 | 约 5 mA LED 电流下有明确 CTR、传播延迟和温度保证的逻辑/高速光耦 | 型号待选 |
| MCU 上拉 | `R_PULL00…09` | 10 | `4.7 kΩ ±1%` 到 3.3 V | 参考值 |
| MCU 串阻 | `R_GPIO00…09` | 10 | `100 Ω ±1%`，靠近 MCU/连接器 | 参考值 |
| 输入滤波 | `C_EDGE00…09` | 10 | `1 nF`，默认 `DNP`；仅作为实测后可装选项 | DNP |
| 传感器入口保护 | `F1/PTC1`, `D1` | 1 套 | 保险/PTC、反接保护、约 33 V TVS；按最终电源峰值选额定值 | 型号待选 |
| 传感器去耦 | `C_SENSOR` | 1 套 | `100 nF + 47 µF`，耐压按 `V_SENSOR` 选择 | 参考值 |
| 载板 MCU | `U_MCU1` | 1 | `STM32G031K8U6`，UFQFPN32；必须覆盖 10 输入、SPI slave、IRQ/RESET、SWD 和看门狗 | 工程候选；待原型 |
| MCU 去耦 | `C_MCU` | 按数据手册 | 每个电源脚就近 100 nF，另留 1–10 µF | 待 MCU 确认 |
| 主控接口 | `J_HOST` | 1 | 8 信号/电源，MX1.25 1×8 锁定或防呆候选 | 厂家/料号待实物核对 |
| 传感器接口 | `J_RX00…09`, `J_TX_A/J_TX_B` | 12 | RX 为 10 个独立 3-pin；TX 为两组 10-pin（每组承接 5 路两芯线）；线缆防呆和锁紧优先 | 物理节距冻结 MX1.25；厂家/料号待实物核对 |
| 调试接口 | `J_DEBUG` | 1 | SWD/JTAG/USB/UART 之一或复合焊盘 | 随 MCU 冻结 |
| 状态/产测 | `LED_STATUS`, `R_TEST` | 1 套 | 可选，不能占用 10 路输入或启动脚 | 待选 |

## 4. 画板规则

1. 先画 `V_SENSOR` 与光耦 LED 区，再画 `3V3` 和 MCU 区，最后画 `J_HOST`；不要让传感器线束先穿过 MCU 区再回到光耦。
2. 每路 `R_IN → U_OPTO LED → BK` 的回路单独编号，光耦输出、上拉、串阻和测试点按同一通道成组放置；`CH00…CH09` 不允许通过“布局顺序”隐式决定。
3. 10 路 MCU 输入尽量放在同一 GPIO/定时器资源组；如果候选 MCU 需要 EXTI 共享或 PIO 分组，必须在选型记录中留下实际 pin mux 和中断延迟证据。
4. SPI、IRQ 和 RESET 走短线并留测试点；`IRQ_N` 的上拉/开漏方式必须在原理图上明确，不能只写在固件注释中。
5. 传感器电源入口、MCU 逻辑电源和主控接口分别标注电压域、地参考和允许探测点；所有连接器丝印必须包括 `L/R`、`TX/RX` 和 `CHxx`。
6. MCU 启动脚、调试脚、晶振/USB/Flash 专用脚不能被十路输入“临时借用”；选型 JSON 的 18/22 根 GPIO 门和具体封装 pinout 是画板放行条件。

## 5. 首样验收顺序

1. 不插 M6：检查 `V_SENSOR` 与 `3V3/GND` 无短路，确认保险、TVS、反接保护和连接器防呆；
2. 只装一条 `R_IN + U_OPTO + R_PULL + R_GPIO`：用受控 10/24/30 V 测 LED 电流、温升、光耦输出边沿和 1/2/3/4/5/6/8/10 ms 脉冲；
3. 复制十路后，用逻辑源对 `CARRIER_IN[0..9]` 同时制造 20 个边沿，验证载板本地 FIFO、最大 16-edge 分帧、SPI TX 预装和 IRQ/CS 生命周期；
4. 接 SmartPaddle ESP32-S3，确认 mode 0、1 MHz、152-byte 事务、CRC/序号和错误帧 fail-closed；
5. 最后才插入真实 M6，逐路记录 `TP_SENSOR_BK`、`TP_OPTO_LED`、`TP_CARRIER_IN`、传感器极性和通道映射。

没有完成第 1–4 步的原始记录前，不能把 `carrier_integration` 或任何通道标成 `pass`；没有真实 M6 与网夹机械记录前，不能把整机验收包标成 `pass`。

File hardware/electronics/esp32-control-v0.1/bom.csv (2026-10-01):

ref | qty | value | role | status | notes
U1 | 1 | ESP32-S3-WROOM-1-N16R8 | 主控 | 候选 | 按模块官方 land pattern 与 N16R8 OPI 限制复核
U2 | 1 | IP5305T-HSOP8-1EP | 1S 充电/5V 升压 | 候选 | 按现有 SmartPaddle 电源架构复核 VIN/BAT/SW/VOUT/EP
U3 | 1 | TPS62162-QFN8-EP | 3V3 降压 | 候选 | 固定 3.3V；FB 接地；PG 保留测试点
J2 | 1 | MX1.25_PROTECTED_1S_LOCK_2P | 受保护 1S 电池 | 候选 | 物理节距锁定 1.25 mm；禁止裸电芯；确认极性与线束防呆
J3 | 1 | MX1.25_SENSOR_10-30V_IN | 外部 M6 电源 | 首样 | 物理节距锁定 1.25 mm；pin2 为 sensor_gnd/0V_SENSOR，与 MCU GND 分离
J4 | 1 | MX1.25_M6_CARRIER_HOST_8P | STM32G031 载板 | 接口已落板 | 物理节距锁定 1.25 mm；3V3/GND/SCK/MOSI/MISO/CS/IRQ/RESET
J5 | 1 | MX1.25_PVDF_ADC_AUX_4P | PVDF ADC | 辅助 | 物理节距锁定 1.25 mm；GPIO1/2；AFE 仍待设计
J6 | 1 | MX1.25_PVDF_CMP_AUX_DNP_2P | PVDF 比较器辅助 | 不装 | 物理节距锁定 1.25 mm；GPIO14 给载板 IRQ；避免隐式复用
J7 | 1 | MX1.25_UI_PANEL_LOCK_14P_CHARGE | UI 子板 14 芯对插 | 候选 | 物理节距锁定 1.25 mm；1-12 为 UI 控制，13/14 为 Type-C VBUS/GND；按真实锁扣座核对
J8 | 1 | MX1.25_M6_SENSOR_RAIL_LINK_2P | 接收载板传感器电源 | 候选 | 物理节距锁定 1.25 mm；pin1/pin2 映射 sensor_fused/sensor_gnd 到接收载板 J_PWR
F1 | 1 | PTC 1.1A | UI Type-C 充电输入限流 | 候选 | 实测 UI 面板 Type-C 输入峰值和温升
F2 | 1 | PTC SENSOR | 传感器电源保护 | 候选 | 电流按 M6 实物确认
D2 | 1 | TVS 33V SENSOR | 传感器电源 TVS | 候选 | 型号随外部 10–30V 瞬态记录冻结
L1 | 1 | 2.2uH BOOST XFL4020 | IP5305T 升压电感 | 候选 | 按 U2 推荐布局/饱和电流复核
L2 | 1 | 2.2uH BUCK XFL3012 | TPS62162 降压电感 | 候选 | 按 U3 推荐布局/电流复核
R5 | 1 | 1M BAT_TOP | 电池分压上臂 | 候选 | GPIO9 sense
R6 | 1 | 1M BAT_BOTTOM | 电池分压下臂 | 候选 | GPIO9 sense
R7 | 1 | 100k BUCK_EN | 降压使能上拉 | 候选 | 与 C6 形成首样启动控制
R8 | 1 | 1k CHARGE_LED | 充电指示限流 | 候选 | LED 电流实测
C1 | 1 | 100n BAT_SENSE | 电池采样滤波 | 候选 | 靠近 ESP32 ADC
C2 | 1 | 22u BAT | 电池去耦 | 候选 | 按 IP5305T 推荐值复核
C3 | 1 | 10u VBUS | 输入去耦 | 候选 | 靠近 U2 VIN
C4 | 1 | 22u SYS5V | 升压输出去耦 | 候选 | 靠近 U2 VOUT
C5 | 1 | 10u 3V3 | 3V3 输出去耦 | 候选 | 靠近 U3/ESP32
C6 | 1 | 100n BUCK_EN | 使能滤波 | 候选 | 按 EN 启动波形复核
D1 | 1 | GREEN STATUS | 充电/电源指示 | 候选 | LED1 路径
SW1 | 1 | IP5305 KEY | 电源按键 | 候选 | 确认 IP5305T KEY 时序

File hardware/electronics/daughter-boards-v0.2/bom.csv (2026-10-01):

board | ref | qty | value | role | status | notes
m6-receiver-carrier-v0.2 | U_OP00..U_OP09 | 10 | opto-isolator + input resistor | 十路 NPN 隔离前端 | 候选 | 按 M6 输出极性/电流和 STM32 输入阈值冻结
m6-receiver-carrier-v0.2 | J_RX00..J_RX09 | 10 | MX1.25_LOCK_3P_RX | 十路接收器三芯对插 | 候选 | 线束汇聚后插入；按线径和插拔空间核对真实 MX1.25 封装
m6-receiver-carrier-v0.2 | J_HOST | 1 | MX1.25_MOTHER_HOST_LOCK_8P | 母板逻辑接口 | 候选 | 3V3/GND/SPI/IRQ/RESET；物理节距锁定 1.25 mm
m6-receiver-carrier-v0.2 | J_PWR | 1 | MX1.25_SENSOR_RAIL_LOCK_2P | 接收器外部电源接口 | 候选 | 与母板逻辑线分开；物理节距锁定 1.25 mm
m6-receiver-carrier-v0.2 | U_MCU | 1 | STM32G031_PLACEHOLDER | 十路边沿采集 MCU | 候选 | 占位封装；最终按独立载板方案冻结
emitter-power-v0.2 | J_BAT | 1 | MX1.25_PROTECTED_1S_LOCK_2P | 内置受保护 1S 电池接口 | 候选 | 物理节距锁定 1.25 mm；禁止裸电芯；需防呆/锁扣
emitter-power-v0.2 | J_EXT | 1 | MX1.25_EXT_TX_10-30V_2P_CURRENT_GATE | 发射端外接后备电源 | 候选 | MX1.25 物理接口；额定电流/端子温升仍需核对，不与电池裸并联
emitter-power-v0.2 | U_BOOST | 1 | TX_BOOST_CURRENT_RATED_PLACEHOLDER | 发射端升压/限流 | 候选 | 按十路同时点亮电流和温升冻结
emitter-power-v0.2 | F_TX | 1 | PTC_OR_FUSE | 发射端过流保护 | 候选 | 按内置电池/外部输入分别核算
emitter-power-v0.2 | D_TVS | 1 | TVS_BY_MODULE | 发射端输入瞬态保护 | 候选 | 外部输入路径按 10–30 V 边界复核
emitter-power-v0.2 | J_TX_A/J_TX_B | 2 | MX1.25_TX_A/B_10P | 十路发射器两芯线束 | 候选 | TX00..TX04 与 TX05..TX09 各 10 芯；不使用 2.54 mm 或错误 1.27 mm 20P 模型
ui-panel-v0.2 | J_MOTHER | 1 | MX1.25_MOTHER_UI_LOCK_14P_CHARGE | 母板 UI 对插 | 候选 | 物理节距锁定 1.25 mm；13/14 脚带回 Type-C VBUS/GND；核对真实锁扣座
ui-panel-v0.2 | J_OLED | 1 | MX1.25_I2C_OLED_FPC_4P | 0.96 英寸 OLED 排线接口 | 候选 | 屏幕独立安装；物理节距锁定 1.25 mm；盖板透明窗/压框
ui-panel-v0.2 | SW_START/SW_MODE | 2 | SW_SPST_TS-1088-xR020 | PCB 直装 START/MODE 贴片按键 | 候选 | 3.9×3.0×2.0 mm 两脚 SMD；面框内置 1.6 mm plunger 直接顶按键
ui-panel-v0.2 | D_STATUS/D_BAT | 2 | LED_0603_1608Metric_GREEN/YELLOW | PCB 直装状态/电池 0603 LED | 候选 | 单色 0603 顶发光；面框开 2.2 mm 直孔；不引入 WS2812/RGB 新走线
ui-panel-v0.2 | J_BUZ | 1 | MX1.25_BUZZER_LOCK_2P | 蜂鸣器接口 | 候选 | 物理节距锁定 1.25 mm；盖板声学膜/防护网
ui-panel-v0.2 | J_SPK | 1 | MX1.25_I2S_SPEAKER_LOCK_5P | 扬声器 I2S 接口 | 候选 | 物理节距锁定 1.25 mm；按峰值电流/声学窗口核对
ui-panel-v0.2 | J_USB_PANEL | 1 | USB_C_Receptacle_GCT_USB4105-xx-A_16P_TopMnt_Horizontal | PCB 直装 Type-C 充电插座 | 候选 | 16 针 KiCad 库模型随板 STL 导出并旋转到 y+ 面板法向；仅 VBUS/GND/CC 使用，D+/D−/SBU 留空；端口穿过面框并配硅胶帽；待首样冻结具体厂家料号
ui-panel-v0.2 | R_CC1/R_CC2 | 2 | R_0603_1608Metric 5k1 | Type-C CC 下拉 | 候选 | CC1/CC2 各一颗 5.1 kΩ Rd 到 GND

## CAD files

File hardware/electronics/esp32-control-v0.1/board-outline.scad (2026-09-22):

// AUTO-GENERATED from esp32-control-v0.1.kicad_pcb Edge.Cuts; do not edit.
// Used by net_stand.scad to form the main-PCB insertion pocket/x-end C-brackets.
esp32_control_board_edge_points = [
    [0.000000, 0.000000],
    [86.000000, 0.000000],
    [86.000000, 32.000000],
    [0.000000, 32.000000],
];

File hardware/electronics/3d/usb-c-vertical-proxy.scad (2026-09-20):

// Mechanical first-article envelope for a vertical 16-pin USB-C receptacle.
// The purchased connector remains the electrical source of truth; this model
// keeps the panel-side opening and board-to-panel clearance reviewable until
// the exact vendor STEP is frozen.
$fn = 48;

body_w = 9.0;
body_d = 5.2;
body_h = 5.8;
mouth_w = 7.4;
mouth_d = 3.4;
mouth_depth = 1.8;

difference() {
    translate([-body_w / 2, -body_d / 2, 0])
        cube([body_w, body_d, body_h]);
    // The mating opening faces local +z, which becomes the y+ service face
    // after the UI PCB is installed vertically in the enclosure.
    translate([-mouth_w / 2, -mouth_d / 2, body_h - mouth_depth])
        cube([mouth_w, mouth_d, mouth_depth + 0.2]);
}

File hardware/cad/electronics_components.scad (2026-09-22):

// Canonical physical electronics envelopes for the net-stand assembly.
//
// Units: mm.  Every module is a reusable local-frame model.  The origin is
// the component's mechanical datum (usually the PCB land centre), and the
// positive local z direction is the service-facing direction.  Assemblies
// must place these modules with translate()/rotate(); do not copy their
// geometry into a second module.
//
// These are only the mechanical envelopes for purchased parts that are not
// soldered to a PCB.  The button, LED and USB-C bodies are deliberately not
// duplicated here: their KiCad footprint models are exported with the board
// and are the authoritative solids used by the assembly collision checks.
// Exact vendor dimensions, electrical ratings, and first-article fit still
// require the selected part datasheets and a physical sample.

module electronics_rounded_prism_positive(length_x, width_y, height_z,
                                          corner_r = 1.0, fn = 32) {
    // A hull of four vertical cylinders gives a printable rounded XY outline
    // without changing the nominal X/Y envelope.  The vertical faces remain
    // planar, which is appropriate for a pouch cell and small enclosures.
    assert(length_x > 2 * corner_r && width_y > 2 * corner_r &&
           height_z > 0 && corner_r > 0,
           "electronics rounded prism dimensions are invalid");
    hull()
        for (x = [corner_r, length_x - corner_r])
            for (y = [corner_r, width_y - corner_r])
                translate([x, y, 0])
                    cylinder(r = corner_r, h = height_z, $fn = fn);
}

module electronics_battery_model_positive(length_x = 65, width_y = 30,
                                           thickness_z = 7,
                                           corner_r = 1.5) {
    // Protected 1S pouch-cell envelope.  The small terminal tab is kept
    // inside the model's X/Y envelope so rails can be checked against the
    // whole bought part without inventing a second battery solid.
    color("orange", 0.82)
        electronics_rounded_prism_positive(
            length_x, width_y, thickness_z, corner_r);
}

module electronics_screen_model_positive(length_x = 25, width_y = 14,
                                          thickness_z = 1.2,
                                          corner_r = 1.0) {
    // Cable-fed OLED/LCD module.  The glass is a thin inset layer on the
    // service-facing face; the body remains one canonical screen instance.
    assert(thickness_z > 0.3 && length_x > 2 && width_y > 2,
           "screen envelope dimensions are invalid");
    color("black", 0.86)
        electronics_rounded_prism_positive(
            length_x, width_y, thickness_z, corner_r);
    color("slategray", 0.70)
        translate([1.0, 1.0, thickness_z - 0.08])
            cube([length_x - 2.0, width_y - 2.0, 0.16]);
}

module electronics_speaker_model_positive(diameter = 16, height_z = 2.2,
                                           diaphragm_d = 12) {
    // Small round speaker body behind the acoustic opening.  The connector
    // remains on the KiCad UI board; this module is the separate loudspeaker
    // body that is mounted once at each world-space speaker location.
    assert(diameter > 0 && height_z > 0 && diaphragm_d > 0 &&
           diaphragm_d < diameter, "speaker envelope dimensions are invalid");
    color("darkslategray", 0.90)
        cylinder(d = diameter, h = height_z, $fn = 64);
    color("black", 0.76)
        translate([0, 0, height_z - 0.12])
            cylinder(d = diaphragm_d, h = 0.14, $fn = 64);
}

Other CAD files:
hardware/cad/laser_micro_mount.scad
hardware/cad/net_post_x_clamp.scad
hardware/cad/net_stand.scad
hardware/cad/receiver_mount.scad

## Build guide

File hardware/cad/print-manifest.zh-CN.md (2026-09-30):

# 内置式球网支架首样打印与装配清单 v0.7-split-c-scheme

本清单以 [`net_stand.scad`](net_stand.scad) 为唯一机械参数源。当前主线是不打孔的桌下 C 形夹：PETG 粗牙螺杆完全位于台面下方，采用 `12 mm` 大径、`9.6 mm` 芯径和 `4 mm` 螺距，牙根宽约 `2 mm`、凹槽宽约 `2 mm`、外侧锥尖约 `0.4 mm`，顶部扁球头向上进入独立台底压块；压块用贯穿球头窝和下方粗牙防脱压环把球头完整包住，压环无胶旋入。配套 PETG 粗牙固定螺母从下臂上侧六角沉孔装入，旋钮内再捕获两枚 `AF16 × 6 mm` 粗牙对锁螺母。夹体底面不再开一个相反方向的螺母窝，也不把旧的 M8×1.25 细牙钢件混入当前打印主线。当前 CAD 按 `12…40 mm` 台面厚度冻结，默认 `25 mm`，超过 `40 mm` 必须重新设计夹体和承力壁。夹体分成“y=0 分型的操作者侧/对手侧两个 C 形半体”和“带绿色整体底座的斜立柱下段/顶部 30 mm 上段”；两个半体沿 ±y 合拢，用 9 套横向 M5 连接，两侧 y=0 分型内侧浅凹槽底对应阳刻 `1…9` 编号，便于分开后按号装配；字顶低于分型基准，不出现在外壁且不影响分型贴合；左下角连接孔向外侧移动，电子仓左下角和右下斜加强边沿各增加连接点，其中 6、7 号连接点及其 boss/孔位整体沿 Z− 下移 `9 mm`；前半圆头沉孔朝外、后半六角螺母窝朝外。只有贴着电子仓空腔面的连接点增加 boss/十字肋，实心夹臂里的连接点只保留通孔/沉孔。电子仓位于 C 夹右侧桥体的整段内缩区域，约 `117×40 mm`，上方保留约 `15.5 mm` 承力层、两侧各 `9 mm` 承力壁和一体化 `4 mm` 斜底；两半分开后从 `y=0` 分型面装入 PCB/电池，主控板按 KiCad Edge.Cuts 板形相减出插入让位。x− 端是一件截面为 `[` 的打印端部夹件，x+ 端是一件镜像的 `]` 端部夹件；每件夹件由留在实心端墙内的整条竖根、下承托唇和上限位唇组成，合拢后形成 `[——主板——]`，不设置主板 boss/定位柱，也不要求螺丝刀进入闭合腔体；电池放在主控板器件层上方的第二层托位，避开端部夹件，不再压穿电池；`x+` 外侧墙和 M5 boss 保持完整，不再使用下方底盖和连续垫。绿色底座从 x+ 开放端推入灰色让位腔，黄色立柱在 `z=16 mm` 与底座相接，分型面为 `z=230.5 mm`，上段继续到 `z=260.5 mm`。绿色底座保留两枚 `Ø4 mm` 通孔、中央 `Ø6×2 mm` 底坑和两侧 `15 mm` 外伸；灰色夹体对应两枚 `Ø4.4 mm` 连接孔与下方钢珠定位孔。网布/圆柱插杆功能区仍为 `z=16…168.5 mm`，不使用 T 槽、公轨或第二个独立滑靴。

这里的“水密”只表示盒盖装好后应严丝合缝、没有明显贯通缝、错台或翘边；不代表 IP 等级、防水认证或实物密封测试已经完成。

## 结构主线

- 网顶不设置轨道、承载条、拼接片或承托座。网布总宽基准为 `1830 mm`，网顶高度为 `152.5 mm`。
- 真实网布侧边空心布套先套在 `Ø10 mm` 圆柱插杆上，再沿原门洞轴线从 x 侧一起推入每根立柱下段的侧开接收腔；门洞横向宽度仍为历史 `15.2 mm`，装上段后由上段封住插入口。
- 球网侧边采用一根独立 `Ø10 mm × 152.5 mm` 圆柱插杆。先把圆柱穿过网布空心边套，再从下段立柱的原门洞方向沿 x 推入接收腔，最后装上上段将插杆捕获；不使用外侧矩形 U 夹、长方形卡条或 keeper。
- 斜立柱由下段和顶部下 `30 mm` 的上段组成，绿色整体底座并入下段；固定 C 形主体沿 `y=0` 分成操作者侧 y- 半体和对手侧 y+ 半体。先把后半的 9 枚 M5 六角螺母装入防转窝，再让两个半体沿 y 合拢，从操作者侧拧入 9 枚 M5 圆头螺钉；两侧 y=0 分型内侧浅凹槽底对应阳刻 `1…9`，按编号定位每个连接位，字顶低于分型基准；左下角连接孔已向外侧移动，电子仓左下角和右下斜加强边沿各增加连接点；分型总间隙 `0.20 mm`。只有碰到电子仓空腔面的连接点才有 printed boss/十字肋，完全位于实心夹臂里的连接点只保留通孔/沉孔，避免外壳凸起。合拢后从 x+ 开放端把绿色底座沿 x 推入灰色让位腔，确认两枚 M4 穿过灰色 `Ø4.4 mm` 孔和绿色 `Ø4 mm` 孔，再让下方 `4 mm` 钢珠进入绿色 `Ø6×2 mm` 底坑。黄色立柱在 `z=16 mm` 与底座相接，分型面为 `z=230.5 mm`，上段延伸到 `z=260.5 mm`；四枚普通盘头或低矮圆头 M3×40 自攻钉只从上段 `Ø3.4 mm` 通孔锁入下段 `Ø2.4 mm×10 mm` 盲孔，不用 90° 沉头或台阶肩螺钉。不存在 T 槽、公轨、第二个滑靴或旧版直接共面座；图示间隙只用于打印装配，不是实体强度或防水承诺。
- 网布接近左右网架末端的位置各放一个 PVDF 振动传感器座，传感器座与立柱保留 `18 mm` 横向净距。

## 现行独立打印件：41 件

运行 `python3 export_net_stand_printables.py --clean` 实际导出并由 `test_export_net_stand_printables.py` 锁定为 `41/41`：

| 组别 | 数量 | 正式 `PART` |
| --- | ---: | --- |
| 立柱分件/分型夹体 | 8 | `post_clamp_carrier_lower` ×2、`post_clamp_carrier_upper` ×2、`clamp_body_half_user` ×2、`clamp_body_half_opponent` ×2 |
| 桌下电子腔 | 2 | 电子仓由 C 夹本体一体内缩形成；左右各一件 y+ 外侧齐平 UI 填平固定板（面板、72×42 mm 腔内固定法兰、捕获环和 8 个孔融合为一件）进入正式打印矩阵，旧的底盖、连续垫和 UI boss 入口已移除 |
| M6 壳体 | 12 | `m6_detector_body`、前盖、后盖、底盖、底盖垫、出线环各左右 1 件 |
| 卡网/夹紧件 | 14 | `net_clamp_rod` ×2、`clamp_pressure_pad` ×2、`clamp_pressure_pad_guard` ×2、`clamp_printed_screw` ×2、`clamp_body_nut` ×2、`clamp_knob` ×2、`clamp_knob_nut` ×2（每个 STL 含一侧两枚螺母） |
| PVDF/历史工具 | 5 | `sensor_mount_body` ×2、`sensor_clamp_lip` ×2、`calibration_gauge` ×1 |

逐文件的 `PART`、左右侧、材料、包围盒、体积和封闭拓扑摘要见 [`exports/desktop-clamp-one-side-x1c-v0.7-split-c-scheme/manifest.json`](exports/desktop-clamp-one-side-x1c-v0.7-split-c-scheme/manifest.json)。

正式清单不包含球台、网布、PVDF 薄膜、ESP32/子板 PCB、电池、M6 光电器件、采购球头、M4/M5/M3 金属连接件和线束；当前夹紧螺杆及其两类螺母由 PETG 打印。`post_joint_exploded`、`clamp_slide_exploded`、各类 `fit_section`/`fit_probe` 是检查用组合预览，不是打印件。

## 打印姿态与 256 mm 盘

`net_clamp_rod` 是一根连续圆柱插杆，导出 STL 时圆柱轴线沿 X 平放，包围盒约 `10 × 10 × 152.5 mm`；装配时圆柱轴线沿 Z，穿过球网侧边空心布套后沿原门洞方向从 x 侧推入下段侧开接收腔，装上上段后被捕获。斜立柱下段包围盒约 `58.7 × 58.0 × 244.5 mm`（含绿色底座和公键），上段约 `28 × 38 × 30 mm`；上段四个 `Ø3.4 mm` 通孔与下段四个 `Ø2.4 mm × 10 mm` 盲孔对应，四枚 M3×40 只连接立柱上下两段；其它零件不由脚本缩放或裁切。

默认 `256 × 256 × 256 mm` 拼盘已经生成：[`print-platter-256/manifest.json`](exports/desktop-clamp-one-side-x1c-v0.7-split-c-scheme/print-platter-256/manifest.json)。当前目标为 `7` 盘、`41` 件已排版、`0` 件超尺寸：两件下段黄绿连接件采用 `rx=0°、ry=51°、rz=45°` 三轴斜放姿态，各占一张 PETG 盘；两件上段按分型面平放；C 夹半体把各自 y 外侧大平面贴床，端部 `[ / ]` 夹件沿 y 方向逐层生成，圆柱插杆平放，其余零件按实际包络分到多张 PETG 盘，TPU/柔性单独一盘。这个结果证明保守包络排版和 STL 几何，不等于已生成 G-code、已验证切片支撑/首层或已完成实物打印。

## 关键导出命令

```text
python3 export_net_stand_printables.py --clean
python3 build_print_platter.py --preset x1c-256 --clean
python3 test_export_net_stand_printables.py
python3 test_build_print_platter.py --default
python3 validate_net_stand.py
```

单件检查示例：

```text
openscad -D 'PART="clamp_body_half_user"' -D 'SIDE=1' -o right-clamp-body-half-user.stl net_stand.scad
openscad -D 'PART="clamp_body_half_opponent"' -D 'SIDE=1' -o right-clamp-body-half-opponent.stl net_stand.scad
openscad -D 'PART="post_clamp_carrier_lower"' -D 'SIDE=1' -o right-post-clamp-carrier-lower.stl net_stand.scad
openscad -D 'PART="post_clamp_carrier_upper"' -D 'SIDE=1' -o right-post-clamp-carrier-upper.stl net_stand.scad
openscad -D 'PART="net_clamp_rod"' -D 'SIDE=1' -o right-net-clamp-rod.stl net_stand.scad
openscad -D 'PART="clamp_slide_fit_section"' -D 'SIDE=1' -o clamp-slide-section.png --render net_stand.scad
openscad -D 'PART="net_clamp_fit_section"' -D 'SIDE=1' -o net-clamp-section.png --render net_stand.scad
```

## X1C 3MF 的对象边界

旧的整件 C 夹/直接共面座 3MF 已作废，不能与当前分型 C 方案接口混用。当前可直接打开的 X1C/PETG 文件位于 `exports/desktop-clamp-one-side-x1c-v0.7-split-c-scheme-3mf/`。

补打这两个独立件请在 `hardware/cad` 下运行：

```text
python3 build_net_clamp_bambu_package.py --side both
```

输出目录为 `exports/desktop-clamp-one-side-x1c-v0.7-split-c-scheme-3mf/`。左右两个 `*-split-c-scheme-X1C-PETG.3mf` 各自都包含 `clamp-body-half-user`、`clamp-body-half-opponent`、`post-clamp-carrier-lower`、`post-clamp-carrier-upper`、`clamp-electronics-ui-panel-mount` 和 `net-clamp-rod` 六个完整对象；这是不含 G-code 的可编辑工程，需在 Bambu Studio 中分盘排版后再切片。当前正式清单只有这个独立圆柱插杆，旧矩形卡条、外侧 U 夹和 keeper 均不再属于结构。

## 装配顺序

主控板已经删除底部 boss、standoff 和主板螺钉；正式固定件是 x−/x+ 两端各一件、随 C 夹半体一体打印的 `[` / `]` 端部夹件。打印 C 夹半体时把 y 外侧大平面（x-z 面）贴床，让端部夹件的下承托唇、上限位唇沿 y 方向逐层生成，不把 15 mm 唇做成 z 方向悬空桥；首样仍需在切片器中复核首层和壁数。

1. 先用目标球台厚度样块（本版适用 `12…40 mm`，默认 `25 mm`），把 `clamp_pressure_pad_guard`（球头螺纹防脱压环）从螺杆尾部套到 12 mm 杆身上；再把 `clamp_printed_screw` 的扁球头从压块底部送入 Ø16.7 内腔，确认球头四周约 0.6 mm 径向余量、顶部约 0.6 mm 轴向余量；最后将压环对准压块底部 Ø30 粗牙 boss 旋入到底。压环下缘 Ø13.2 孔让杆身通过但挡住球头，上口 Ø14.7 向内腔扩口，球头在里面可以运动；整个防脱结构不点胶、不装热熔螺母、不用松散销钉。然后安装左右 `post_clamp_carrier_lower` 和 `post_clamp_carrier_upper`、固定上夹板胶皮、`clamp_body_nut`、下臂上侧捕获螺母和旋钮内两枚 `clamp_knob_nut` 粗牙对锁螺母；确认不打孔、不碰台面、不干涉压块/螺杆工作区。粗牙件必须成套使用，不与 M8×1.25 金属螺母混配；2 mm 牙根/2 mm 凹槽加 0.4 mm 锥尖保证打印后牙根有连续实体，外形不是平顶环带。
2. 将左右新版 `clamp_body_half_user` 与 `clamp_body_half_opponent` 的大平面定位到夹体安装位置；先在对手侧半体外侧六角窝装入 9 枚 M5 螺母，再沿 y 合拢两半，从操作者侧拧入 9 枚 M5 螺钉，确认左下角连接孔向外侧移动后的净空、电子仓左下角与右下斜加强边沿新增连接点（其中 6、7 号已整体沿 Z− 下移 `9 mm`）以及空腔边界处的 boss 柱/十字肋完全贴合；实心夹臂里的连接点不应出现外凸 boss。电子件安装时保持主控板元件面朝 +z，不翻板：两半分开后先把主控板平放到任一半体的下承托唇上，让 x−/x+ 两端同时落入 `[` / `]` 夹件；确认两件夹件的上下唇与板厚间有设计余量，且整条竖根都在端墙内；再将另一半对准分型面并合拢，形成 `[——主板——]`，共同完成承托和防上浮，整个过程不需要把螺丝刀伸进电子腔。电池放在主控板器件层上方的第二层托位，确认电池与端部夹件和板上器件保持净空，再检查一体化斜底、9 mm 侧壁和约 15.5 mm 上部承力层没有干涉；`x+` 外侧墙和 boss 不切除，不安装下方底盖或连续垫。将一体式 `clamp_electronics_ui_panel_mount` 从电子腔 y- 侧穿入侧窗，确认外表面与 C 夹壁齐平，腔内侧 72×42 mm 固定法兰和捕获环落在墙内；使用 8 枚 2 mm 蘑菇头自攻钉从腔内穿过一体件上的 Ø2.3 mm 通孔，直接进入 C 夹实心内壁 Ø1.6 mm 盲导孔，捕获环已与面板周边融合 `0.4 mm`，孔边至少保留 `1.2 mm` 实体边，外壁底厚 `0.7 mm`；不生成正向 UI boss 柱，外侧不出现螺钉头或沉孔。确认屏幕窗口、START/MODE 腔内导向柱、两个 0603 LED 直孔（可加透明导光柱）、扬声器声学窗和由当前 KiCad USB-C 仅外壳/屏蔽罩轮廓生成的 0.25 mm 装配通道（侧面焊接脚、接触脚和安装脚不参与外侧开口轮廓）分别与 UI 子板器件对齐；外侧再挖一个以 KiCad 金属壳体前沿为止点的圆角矩形碗槽，外围保留 `0.60 mm` 连续环形打印底，中心 KiCad-fit 通孔贯穿并由 Type-C 金属壳体负责显示/插入；再从 x+ 开放端把对应 `post_clamp_carrier_lower` 的绿色整体底座沿 x 推入让位腔，确认两枚 M4 穿过灰色 `Ø4.4 mm` 孔和绿色 `Ø4 mm` 孔，再安装钢珠/弹簧/压盖。黄色立柱在 `z=16 mm` 与绿色底座相接，分型面为 `z=230.5 mm`，上段继续到 `z=260.5 mm`；网布/圆柱插杆功能区止于 `z=168.5 mm`。不要把旧的整件夹体或直接共面座立柱混进来。
3. 将下段 `post_clamp_carrier_lower` 从 x+ 开放端推入 C 夹让位腔，再把上段 `post_clamp_carrier_upper` 沿 z 对准 `z=230.5 mm` 分型面滑下；确认两条公母键贴合，四枚 M3×40 自攻钉从上段 Ø3.4 mm 通孔进入下段 Ø2.4 mm×10 mm 盲孔。上段中心 Ø6.8 mm 攻丝底孔供球头下端 M8×1.25 直接拧入，不使用接缝套筒。
4. 先把球网侧边的空心布套完整套到 `Ø10 mm × 152.5 mm` 圆柱插杆上；再把插杆与网布一起沿原门洞轴线从 x 侧推入下段侧开接收腔，确认杆底坐在 `z=16 mm`、网布覆盖 `z=16…168.5 mm`，最后装上 `post_clamp_carrier_upper` 封住插入口。拆卸时先拆上段，再沿相反方向抽出圆杆和网布。
5. 在网端靠近立柱的位置装 PVDF 座/薄膜/压片；每侧传感器与立柱保留 `18 mm` 横向净距。不得把 PVDF 座当作网架承力件。
6. 依次安装 M6 十路主体、前后盖、底盖、连续压合垫、出线环、线束和采购球头；闭合盖板后检查连续配合面、定位唇和胶条是否严丝合缝，无明显贯通缝或翘边。之后才进行 M6 光轴、球头微调、供电和输出联调。

## 电子与外购件边界

梯形夹体内部是电子腔，不把器件塞进桌面受力区：主控端预留 ESP32 母板、UI 子板、屏幕窗口、START/MODE 按钮、指示灯、扬声器/蜂鸣器、USB-C 和电池；另一端预留发射电源子板及内置 1S 电池，并保留外接电源接口。PCB、端子/压接线束和电池以 `hardware/electronics/` 的 KiCad/Atopile/装配包为准，先按 fit report 和实物器件复核，再封盖。

M6 器件采用左右各十路的实际安装包络，光学轴向球台中心；采购球头、M6 SKU、线束和端子必须按到货尺寸/后缀复核。现有 CAD/网格验证不能代替铜箔生产释放、电气波形、实物装配或承力试验。

## 历史入口

`net_rail*`、`post_joint_sleeve`、`post_joint_key` 等名称只保留为历史/兼容诊断入口，不能复制到正式打印包；当前网顶没有轨道，当前网端件是 `net_clamp_rod`，四枚 M3×40 属于立柱上下分型连接。

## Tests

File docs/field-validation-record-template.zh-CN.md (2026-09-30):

# 乒乓智配实物验证记录模板

本模板用于把打印件、光学模块、PVDF 前端、ESP32-S3 固件和 SmartPaddle 连接层的实测证据留档。没有照片、量具读数、原始波形或事件日志时，项目状态保持“待实物”，不以主机测试代替实体验收。

## 0. 基本信息

| 字段 | 记录 |
| --- | --- |
| 记录编号 |  |
| 日期/地点/操作者 |  |
| 固件 commit |  |
| CAD commit / STL 版本 |  |
| ESP32-S3 板卡与 PCB 版本 |  |
| 球台型号/台面实测厚度，当前 CAD 参数 | `net_stand.scad` /  |
| AFE/光学模块版本 |  |
| `calibration_id` |  |
| 环境光、电源和网络条件 |  |
| 原始证据目录 | 例如 `evidence/2026-08-24-run-01/` |

建议文件名统一为：`<记录编号>-<测试编号>-<序号>.<ext>`，例如 `run-01-B06-03.json`、`run-01-S01-left-raw.csv`、`run-01-M03.jpg`。

也可以使用 [`field-validation-record.example.json`](field-validation-record.example.json)
作为机器可校验的记录起点。运行
`python tools/validate_field_record.py <记录文件>.json` 会要求全部 M/B/S/T/E
编号都存在；`pass`/`fail` 必须绑定 `evidence_root` 下真实存在的证据文件，只有
`pending` 才允许暂时没有证据。模板记录默认全部为 `pending`，不代表实机通过。

## 1. 机械与标定记录

### M-01 内置支架重复安装

1. 在同一球台边缘标记左右支架的安装参考点。
2. 松开、从桌下夹入、旋钮夹紧、测量支架/立柱参考点；重复 10 次。
3. 每次记录左右安装位置、拆装后位置差、旋钮圈数/手感、台面接触痕迹和软垫状态。

| 次数 | 参考位置读数 mm | 拆装后读数 mm | 是否滑移 | 照片/日志 |
| ---: | ---: | ---: | --- | --- |
| 1…10 |  |  |  |  |

### M-02 传统桌下夹持

使用与目标球台相同厚度的样块或真实球台，记录从松开到夹紧的 M8 螺杆行程和旋钮手感。检查上下接触面是否均匀、立柱是否倾斜、夹持后是否滑移、台面是否有损伤、螺杆和软垫是否卡滞或脱落。出现裂纹、明显永久变形或无法稳定夹住台面时判定失败，并保留照片。

### M-03 替换式球网基准

安装左右 `net_stand`、真实网布、PVDF 安装座、左右 M6 PETG 长条主体、前后盖、底盖、竖直采购球头和 20 枚 M6 直角对射器件。用直尺/水平仪记录网顶是否为首轮 `152.5 mm`、固定网柱总高是否为 `244.5 mm`（`z=16…260.5 mm`）、名义总网宽是否为 `1830 mm`、左右网柱外边界是否各比台边外伸 `152.5 mm`、左右主体和光轴平行度、10 对光轴的高度/间距、线缆净空和网布张力是否使支架转动；另检查夹体外轮廓/下沿相对台边的外伸是否至少 `130 mm`、桌边外侧非接触区是否为 y 全深实心桥体、上下结构夹臂是否均为 `14 mm`、灰色下部全宽实心渐变支撑（靠台侧 `40 mm`、外侧 `14 mm` 斜底）、台边外净空和夹紧后是否有倾斜/滑移，并核对加长 M8 丝杆的行程；按装配顺序先把网布从球台中心侧穿过立柱下段 `3 mm` 过道，确认端部止在立柱外表面，把空心边套套到 Ø10 圆柱插杆后沿原门洞轴线从 x 侧推入下段侧开接收腔，先装下段、插入上段公键，再用四枚普通盘头/低矮圆头 `M3×40` 固定并封住入口，记录插入力、落座和防脱行程；确认采购球头固定上端 1/4-20 外牙从各自 x 后端进入后盖背面中央 boss，下端 M8×1.25 外牙完整拧入固定网柱上段中心攻丝座，记录有效啮合长度、攻丝/嵌件和承力；固定网柱下段底面与 C 夹 `z=16 mm` 承托面共面，`z=230.5 mm` 分型，网布/圆柱功能区止于 `z=168.5 mm`；NPN 供电/输出另行记录，不把机械对准当作电子通道通过。

| 项目 | 目标/记录方法 | 实测 | 证据 |
| --- | --- | --- | --- |
| 左右立柱/M6 主体与光轴平行度 | 直尺/水平仪/光斑 |  |  |
| 网顶 0 基准 | 台面以上 `152.5 mm` 首轮参数 |  |  |
| 网架总宽/两侧外伸 | 网布名义总宽 `1830 mm`；左右网柱外边界各距台边 `152.5 mm`；无网顶轨道 |  |  |
| 夹体外轮廓/下沿外伸 | 项目结构下限 `≥130 mm`；当前 CAD 夹体最外点名义外伸 `156 mm`，且固定夹体外端与立柱下段宽端面齐平，以实物最外点/下沿量测；若按标准网夹复用，还要记录台下投影/开口 |  |  |
| 实心桥体/渐变支撑与夹持开口 | 开口、压块和螺杆区域保留；桌边外侧非接触区 y 全深实心，上下结构夹臂均 `14 mm`；开口之外下部 y 全深，靠台侧 `40 mm`、外侧 `14 mm`，斜底连续且无裂纹 |  |  |
| M6 十路点位/高度 | `+10…+190 mm`，中心距 `20 mm`；以量具、对准光斑和 NPN 输出记录 |  |  |
| M6 机械包络 | M6×0.75、头部约 8 mm、安装杆约 14 mm；以实物量测记录 |  |  |
| 张力后支架位置 | 重复测量 |  |  |
| 网布过道/圆柱插杆 | 从球台中心侧穿过 `3 mm` 过道；空心边套套到 Ø10 圆柱插杆后沿 x 推入侧开接收腔；安装上段后封住入口；记录插入力、落座和防脱 |  |  |

## 2. M6 光电与 PVDF 记录

### B-06/B-07/B-08 光栅逐通道自检

在不移动两侧主体的情况下，按卖家确认的 M6 NPN 输出方式记录 10 个接收端通道：棕线接器件电源正、蓝线接 0 V、黑线经负载/光耦或电平转换进入主控；不得把 10–30 V 黑线直接接 ESP32-S3 GPIO。记录正常对准、单通道遮挡、发射端断电、接收端偏移、网体持续遮挡和相邻通道遮挡六种状态，保留电源电压、NPN 电平/负载电流、GPIO/逻辑分析仪记录、健康位图和校准版本；在卖家确认常开/常闭后缀前，`beam_mask` 仍保持“待确认”。

商家对 5 ms 的确认只说明“被测状态变化到输出完成变化”的响应时间语义，不是最小连续遮挡保证。对高速事件另按 [`M6 5 ms 响应/最小遮挡实测方案`](m6-response-time-validation-v0.1.zh-CN.md) 记录 1–10 ms 的已知遮挡脉冲、传感器侧 NPN 波形和主控侧波形；没有实测最小输入脉宽前，不得把短遮挡漏检归因于固件去抖，也不得把 `5 ms` 写成通过门槛。

| 通道/位置 | 物理高度 mm | 单独遮挡或 NPN 原始输出 | 健康结果 | 证据 |
| ---: | ---: | --- | --- | --- |
| 0…9 | 按 `+10、+30、…、+190 mm` 记录 |  |  |  |

### S-01/S-02/S-03 PVDF

分别记录安静、轻触网顶、真实擦网、旋钮操作、碰夹具和球网整体振动。每次保存左右原始波形、触发时间、峰值、能量、持续时间、阈值/基线版本和 `waveform_ref`。只要 ADC 流中断或帧超时，必须确认归档中存在 `complete=false` 的帧，并确认事件带 `waveform_incomplete`。

| 场景 | 左/右触发 | 峰值/能量 | 波形完整 | `waveform_ref` | 是否误报 | 证据 |
| --- | --- | --- | --- | --- | --- | --- |
| 安静 |  |  |  |  |  |  |
| 轻触 |  |  |  |  |  |  |
| 擦网 |  |  |  |  |  |  |
| 机械操作 |  |  |  |  |  |  |
| 网体振动 |  |  |  |  |  |  |

## 3. 业务、链路与回放记录

### E-01 单球场景

至少记录正常过网、擦网后过网、擦网未过网，以及快速但可分离的连续单球。检查每球事件数、状态、时间戳、光束位图、擦网传感器位图和质量标记；重叠多球不在首版验收范围内。

### T-01/T-02 断链与补发

在 WebSocket/既有连接层断开期间制造事件，记录断开前后的事件 ID、RAM 缓存数量和发送失败结果；恢复连接后记录补发顺序、重复数、剩余缓存和 App 接收日志。发送失败的事件必须仍可恢复。

### T-03 外部视频关联

使用同一时钟来源或记录时钟偏移，将 `timestamp_us` 与外部视频/设备时间轴对照。这里仅验证后续回放关联能力，不把相关性记录解释为视觉裁判结论。

## 4. 结论

| 结论项 | 结果 |
| --- | --- |
| 本次通过的测试编号 |  |
| 失败/待复测项 |  |
| 需要调整的机械、AFE、阈值或窗口 |  |
| 是否允许进入下一阶段 | 是 / 否 |
| 复核人 |  |

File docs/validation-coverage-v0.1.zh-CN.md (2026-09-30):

# 乒乓智配验证证据映射 v0.1

> 当前硬件主线已经切换为用户指定的 M6 十路光电器件阵列 + 10×56×216 mm PETG 长条主体 + 后盖 x 背面中央加厚 1/4-20 boss + 竖直采购球头；商品球头上端固定螺纹为 1/4-20 外牙，下端默认选择 M8×1.25 外牙直接进入固定网柱上段中心攻丝座；斜立柱由 z=16…230.5 mm 下段和 z=230.5…260.5 mm 顶部 30 mm 上段组成，四枚普通盘头/低矮圆头 M3×40 连接，网布/圆柱功能区仍到 z=168.5 mm。本文中保留的 STG-120ML、旧版 10 路/10 mm、梳齿条和自制三轴载台描述只作为历史资料，不代表当前 M6 器件或机械接口。机械、采购和接口判断以 `docs/m6-optical-array-design-v0.1.zh-CN.md`、`docs/m6-aluminum-machining-spec-v0.1.zh-CN.md` 和 `hardware/cad/net_stand.scad` 为准。

本文把 [`validation-matrix.zh-CN.md`](validation-matrix.zh-CN.md) 的每一项映射到当前可复核的代码或现场证据。这里的“主机覆盖”只证明业务逻辑、时间边界或数据契约；它不替代传感器、球网、打印件、最终 PCB 和真实 App 的现场记录。

## 1. 软件/主机证据

主机入口：

```text
python3 firmware/host-tests/run_tests.py
ctest --test-dir firmware/host-tests/build --output-on-failure
ASAN_OPTIONS=detect_leaks=0 UBSAN_OPTIONS=halt_on_error=1 \
  ctest --test-dir firmware/host-tests/build-sanitize --output-on-failure
```

| 编号 | 当前软件证据 | 能证明什么 | 仍缺什么 |
| --- | --- | --- | --- |
| M-01 | 无；`tools/validate_field_record.py` 可校验现场记录格式 | 记录项完整性和证据路径安全 | 内置支架重复从桌下夹紧、安装位置、滑移和软垫损伤记录 |
| M-02 | `hardware/cad/validate_net_stand.py`；OpenSCAD CI 当前 `net_stand.scad` 各部件、夹体/上表面保护垫/台底压块/圆头螺杆/固定下臂螺母/18 齿圆角锯齿旋钮两枚对锁螺母拆分、18/25/30 mm 台厚免打孔矩阵、镜像、独立打印零件 STL 封闭边拓扑与非法参数路径 | 免打孔 C 形夹体跨过台边，上表面可替换保护垫位于固定上夹板与桌面之间，圆头 M8 螺杆只到台底压块下表面；固定下臂单枚螺母与旋钮两枚对锁螺母的包络、叠层深度和螺杆穿越关系可编译；独立打印零件的 STL 没有开放边/非流形边，组合装配 PART 只作为可视检查，左右导出可编译 | 实物样块/球台的夹紧力、台面损伤、保护垫材料/压缩、立柱倾斜、螺杆行程、旋钮握持手感、对锁防松和标准件实际装配 |
| M-03 | `validate_net_stand.py`；`render_net_stand_preview.py`；装配页 | `152.5 mm` 网顶、无网顶轨道、网布两端各穿过 `3 mm` 立柱过道并止到立柱外表面、Ø10 圆柱插杆沿 x 推入下段侧开接收腔、上段安装后封住入口、左右各一个 PVDF 座且与网架保留 `18 mm` 净距；斜立柱下段/上段与 `clamp_body_segment` 的共面落座、分型面 `z=230.5 mm`、固定基台坐面 `z=16 mm`、无下插段、桌下 C 形夹、左右十路 M6 `10×56×216 mm` PETG 主体/前后盖/底盖、20 个 M6 包络、竖直采购球头和 y+ UI 一体式填平固定板和腔内固定孔的参数与可视关系；四枚普通盘头/低矮圆头 M3×40 只连接立柱上下段，固定网柱上段顶面保留中心 M8×1.25 攻丝底孔，球头下端直接进入 | 真实网布厚度/张力、侧开接收腔防脱行程与推入力、共面落座打印配合与耐久、两侧脚部/球路净空、夹体承力、网顶高度、M6 螺纹/光学中心、球头两端螺纹、线缆净空和 NPN 供电/电平；仍需现场量测目标球台兼容性 |
| B-01 | `test_clean_over_and_height_interval()`、`test_every_beam_mask_interval()` | `clean_over`、位图、离散高度和球底间隔契约 | 真实光束与球体遮挡 |
| B-02 | `test_sensor_pipeline_end_to_end()`、`test_trigger_before_dma_dispatch_pipeline()`、`test_runtime_chain_with_delivery()`、`net_event_trace` | 擦网候选与光栅关联、波形引用/特征、`touch_over` 以及事件进入传输缓存 | PVDF 前端与真实过网动作 |
| B-03 | `test_touch_no_cross_and_unknown()`、`net_event_trace` | 擦网无光栅时的 `touch_no_cross` 和质量标记 | 真实擦网未过网动作 |
| B-04/B-05 | `test_touch_over_before_and_after_beam()` | 左/右单通道 `sensor_mask` 与前后时序关联 | 左右 PVDF 实物分别接板触发 |
| B-06 | `test_each_beam_channel_independently()`、`test_beam_channel_remapping()`；全部 `1…1023` 位图 Schema 遍历（当前 10 路业务契约）；短遮挡实测按 [`m6-response-time-validation-v0.1.zh-CN.md`](m6-response-time-validation-v0.1.zh-CN.md) 执行 | 10 个 M6 接收端 NPN 通道的逻辑编号、原始输入 bit 到高度的排列映射、位图契约；商家 5 ms 响应语义已记录 | 实际 M6 发射/接收器、NPN 常开/常闭后缀、10–30 V 供电、负载/光耦或电平转换、最终逐通道接线顺序、最小输入脉宽、输出脉宽和逐通道遮挡响应 |
| M6 载板协议 | `m6_carrier_protocol_tests`、`m6_carrier_protocol.*`、`m6_carrier_adapter.*`、`m6_carrier_spi.*`、`sensor_board_hooks.*`、`carrier/m6_carrier_capture_core.*`、`carrier/m6_carrier_spi_slave_transport.*`、`carrier/stm32g031-reference/m6_carrier_stm32g031_port.*`、`carrier/stm32g031-reference/m6_carrier_stm32g031_register_port.*`、`carrier/stm32g031-reference/m6_carrier_stm32g031_startup.cpp`、`carrier/stm32g031-reference/stm32g031k8u6.ld`、可选 `CMakeLists.txt`、`m6_carrier_stm32g031_port_tests`、`m6-capture-carrier-stm32g031k8-pinmap.example.json`；ESP-IDF 5.5.1 build；`arm-none-eabi-g++ 16.2.0` + ST/ARM 官方头文件 object compile-only 与参考 ELF/bin | CRC/长度/分片/序号/FIFO 边界、`CLOCK_SYNC_REQUEST/RESPONSE` 两事务 t2/t3、载板侧固定 TX 缓冲编码、SPI 从机 IRQ/CS 生命周期、短事务 fail-closed、主机侧对称事务时钟偏移估计、至少三次样本的 offset spread/相邻漂移/最低 RTT 运行时校准门、板级同步 hook、换 offset 时清空旧边界、原始电平到 `BeamCapture` 的时间戳适配、ESP32-S3 IRQ 驱动固定最大 SPI 事务、STM32G031K8U6 的 10 路唯一 EXTI pin map、PB0/NSS 专用 EXTI0 CS 边沿、18/22 根 GPIO 资源预算、host 侧十路同时双边沿 20-edge 分帧、无 HAL 端口外壳、基于 ST CMSIS 的 EXTI/TIM2/SPI1/DMA1/DMAMUX1 寄存器绑定、最小启动/向量表/链接脚本、DMA/SPI 错误 fail-closed 和 DMA 计数一致性检查 | 最终板级固件与可烧录验证、PCB 与 SPI/IRQ 电气波形、真实同步事务波形/时钟漂移、真实十路同时边沿和 1–10 ms 实测 |
| B-07 | `test_channel_self_test_and_baseline()`、`test_sensor_health_quality_flags()`、`test_sensor_health_gate_pipeline()` | 发射/接收/基线/健康位图失败时 fail-closed | 断发射、偏接收、网体遮挡和环境光实测 |
| B-08 | `BeamSelfTestReport` 形状测试和健康门测试 | 每通道 pass/fail 位图可组合且坏快照不放行 | 上电自检在目标板逐通道执行并留档 |
| B-09 | `test_sensor_health_quality_flags()` | GPIO 队列溢出后的旧输入清理和 `unknown` | ESP32-S3 真实 ISR 高频边沿压力 |
| S-01 | `test_waveform_window()`、`test_trigger_before_dma_dispatch_pipeline()` | 双通道窗口、触发前/后边界、迟到 DMA 回填和波形特征 | ADC1 实际 16 kHz、AFE 电压/噪声/削顶测量 |
| S-02 | 无 | — | 旋钮、碰夹具、球网振动的原始波形与误报率 |
| S-03 | `test_waveform_timeout_flush()`、`test_touch_no_cross_and_unknown()` | 不完整帧释放、`waveform_incomplete` 和 fail-closed 状态 | 接板后真实 ADC 中断/超时行为 |
| T-01/T-02 | `test_delivery_recovery_and_feedback()`、`test_runtime_chain_with_delivery()`、可选 `smartpaddle_ws_transport_adapter.cpp` | 断链缓存、容量覆盖、发送失败、补发顺序和不重复，并验证完整传感器事件序列化后进入缓存再补发；联合 target 可强绑定 SmartPaddle `/ws` API | SmartPaddle/App 联合 target 编译、设备端 WebSocket 回环、健康快照和真实球事件 |
| T-03 | `tools/correlate_net_events.py`、`tools/test_correlate_net_events.py` | 对 `NetEvent.timestamp_us` 与外部 CSV 时间标记执行明确偏移、包含边界和时间窗匹配；不读取视频，也不解释图像 | 同钟来源/偏移的现场测量、外部设备导出文件和真实事件日志 |
| E-01 | `test_sequential_and_overlapping_events()`、`net_event_trace` | 可分离事件、重叠事件 fail-closed 和事件 ID | 真实连续单球与球路分离能力 |

## 2. 现场证据门

`docs/field-validation-record.example.json` 当前 19 项全部为 `pending`，`tools/validate_field_record.py` 只验证编号完整性和证据路径安全，不会把主机测试自动改成 `pass`。因此当前结论是：

- 软件/协议/参数验证链已具备并持续由 CI 执行；
- M-01、S-02 没有可替代的主机证据；T-03 现在有纯时间戳关联工具覆盖，但仍没有真实同钟/偏移的现场证据；
- B-06～B-09、S-01～S-03、T-01～T-02、E-01 以及 M6 载板协议的主机证据不能关闭对应实物验收项；
- 只有在证据目录存在照片、量具/示波器/逻辑分析仪记录、原始波形或真实事件日志后，才允许把记录从 `pending` 改成 `pass`/`fail`。

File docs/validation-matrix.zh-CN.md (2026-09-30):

# 乒乓智配首版验收矩阵

这是训练/实验样机的可复核验证清单。通过某一项只说明该项在当前机械、光学和阈值配置下可记录，不代表比赛级准确率或跨球网型号兼容性。

每项当前主机覆盖、具体测试函数和实物缺口见 [`validation-coverage-v0.1.zh-CN.md`](validation-coverage-v0.1.zh-CN.md)。

| 编号 | 场景 | 操作/输入 | 预期证据 | 状态 |
| --- | --- | --- | --- | --- |
| M-01 | 内置支架重复安装 | 同一球台边缘用左右支架拆下、重新从桌下夹紧 10 次 | 上下接触面完整，M8 旋钮行程足够，左右立柱安装位置/滑移记录可复核 | 待实物 |
| M-02 | 免打孔传统桌下夹持 | 用与目标球台相同厚度的样块，从松开到夹紧完整操作 | 固定 C 形夹体跨过台边，M8 螺杆只在台面下方顶可动压块且不碰穿台面；上夹板/台底软垫不损伤台面，立柱不明显倾斜，螺杆/旋钮无卡滞或脱落 | 待实物 |
| M-03 | 替换式球网基准 | 安装左右支架、真实网布、PVDF 座、M6 PETG 长条主体/前后盖/底盖和采购球头 | 网顶为 `152.5 mm` 首轮基准；网顶不设轨道；网布从球台中心侧穿过两侧立柱的 `3 mm` 过道，端部止到立柱外表面，再把 Ø10 圆柱插杆沿 x 推入下段侧开接收腔；斜立柱在顶部下 `30 mm` 分型，上段公母键定位，四枚普通盘头/低矮圆头 `M3×40` 固定到下段 `Ø2.4×10 mm` 导向盲孔；上段中心 `Ø6.8 mm` 攻丝底孔接球头下端 M8×1.25；上段安装后封住插入口；固定网柱底面与 C 夹黄灰交界 `z=16 mm` 共面，下段承载、上段分型后延伸至 `z=260.5 mm`，网布/圆柱功能区止于 `z=168.5 mm`，不向下插入 C 形座；左右端各一个 PVDF 且保留 `18 mm` 净距；左右十路 M6 阵列平行，`20 mm` 节距的 `+10…+190 mm` 通道基准可复核 | 待实物 |
| B-01 | 正常过网 | 球命中一个或多个光栅通道，无 PVDF 触发 | `clean_over`，`beam_mask`、高度区间、时间戳完整 | 主机测试 |
| B-02 | 擦网后过网 | PVDF 触发后在窗口内命中光栅 | `touch_over`，左右峰值/能量和可由 `waveform_ref` 查到的原始帧保留 | 主机测试 |
| B-03 | 擦网未过网 | PVDF 触发，窗口内无光栅 | `touch_no_cross`，`beam_mask=0`，质量标记说明无光栅 | 主机测试 |
| B-04 | 左片单独触发 | 仅通道 0 触发 | `sensor_mask=1`，事件可归并 | 主机测试 |
| B-05 | 右片单独触发 | 仅通道 1 触发 | `sensor_mask=2`，事件可归并 | 主机测试 |
| B-06 | M6 输出自检与短遮挡响应 | 按卖家确认的输出形态逐通道遮挡，并按 [`m6-response-time-validation-v0.1.zh-CN.md`](m6-response-time-validation-v0.1.zh-CN.md) 施加 1–10 ms 已知遮挡脉冲，确认 10 个发射/接收器的对应关系 | 只有输出语义、最小输入脉宽和输出波形被证实后才记录通道/点位；否则记录为接口未确认，不生成高度 | 主机测试/待实机 |
| B-07 | M6 错位/遮挡 | 逐个旋入/退出器件、偏航/俯仰/滚转微调、遮挡光路或制造环境光干扰 | 自检失败或 `unknown`，不伪造高度；保留器件诊断、微调角度和机械对准记录 | 主机业务测试/待实机 |
| B-08 | 启动自检 | 上电后检查两套放大器、电源和隔离/电平接口 | 每个已确认输出通道得到 pass/fail 与校准版本；未确认输出保持 pending | 待固件接板 |
| B-09 | GPIO 队列溢出 | 人为制造高频边沿或 ISR 队列满 | 采集器复位，下一事件为 `unknown` 并带 `sensor_queue_overflow` | 主机状态测试/待实机 |
| S-01 | PVDF 波形 | 安静、轻触、擦网三类输入 | ADC1 16 kHz，20 ms 前触发 + 80 ms 后触发，可复核波形 | 主机窗口测试/待接板 |
| S-03 | ADC 波形超时 | 只收到单通道或中途停止 ADC 流 | 释放采集状态，保留不完整帧，事件带 `waveform_incomplete` | 主机测试/待接板 |
| S-02 | 机械误报 | 旋钮操作、碰夹具、球网振动 | 记录峰值/能量/持续时间，阈值调节有依据 | 待接板 |
| T-01 | 断链缓存 | 断开 WebSocket 后产生事件 | 最近事件进入 RAM 小环形缓存 | 主机测试/待接板 |
| T-02 | 恢复补发 | 恢复 WebSocket | 按事件顺序补发，事件 ID 不变，不重复生成；发送失败后事件仍保留 | 主机适配测试/待接板 |
| T-03 | 外部回放关联 | 用海康威视等外部设备时间轴对照 | `timestamp_us` 可作为后续回放关联依据 | 待联调 |
| E-01 | 单球分离 | 快速但可分离的连续单球 | 每球最多一个 `NetEvent`，不把安静间隔内的同一球拆开 | 主机测试/待实机 |

## 阶段门

- 阶段 A：文档、JSON Schema、主机状态机测试通过；
- 阶段 B：OpenSCAD 参数断言通过，并完成无 OpenSCAD 环境下的几何预览静态校验；
- 阶段 C：打印件实测项目全部由照片、量具读数和安装记录补证；
- 阶段 D：选定独立 M6 载板 MCU/封装并完成 GPIO/定时器/SPI 从机预算、ESP-IDF 主控与载板联合 target 编译，再在目标板和最终引脚表确认后烧录；
- 阶段 E：至少完成 B-01～B-08、S-01～S-02、T-01～T-03、E-01 的实机记录。

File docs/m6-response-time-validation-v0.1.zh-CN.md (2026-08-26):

# M6 5 ms 响应与最小遮挡实测方案

状态：`商家响应时间语义已确认，最小输入脉宽/最小遮挡时间待实测`。

本文件把商家关于“5 ms”的回复转换成可验收的测试，不把响应时间误写成最小检测门槛。

## 1. 当前可用结论

商家对用户问题的回复是：“被测信号发生变化，到传感器输出信号真正跟着变化完成，中间需要 5 ms；不要求物体必须持续遮挡 5 ms 才能检测。”因此当前记录为：

- `5 ms`：输入状态变化到 NPN 输出完成变化的响应时间语义；
- 不是：物体必须连续遮挡 5 ms 才开始检测；
- 尚未证明：遮挡小于 5 ms 时一定会产生有效输出脉冲；
- 尚未确认：上升沿/下降沿分别的最大值、内部滤波、最小输入脉宽、最小输出脉宽和重复检测率。

如果遮挡在传感器输出完成变化前已经结束，传感器可能没有输出可捕获的稳定状态。ESP32 中断、硬件锁存或软件缓存只能保存已经产生的脉冲，不能修复传感器本身漏检。

## 2. 乒乓球遮挡时间的估算

先用简单上界估算，不把它当作实测：

```text
t_block ≈ L_effective / v_perpendicular
```

其中 `L_effective` 是球体沿光束运动方向实际遮挡的弦长，通常小于等于球径；`v_perpendicular` 是球速在穿过光束方向上的分量。若用约 40 mm 球径做中心穿越的上界示例：

| 速度示例 | 40 mm 中心遮挡时间示例 |
| ---: | ---: |
| 2 m/s | 20 ms |
| 5 m/s | 8 ms |
| 8 m/s | 5 ms |
| 10 m/s | 4 ms |
| 15 m/s | 2.67 ms |
| 20 m/s | 2 ms |

实际斜向穿越、非中心穿越和球体旋转都会改变 `L_effective`。因此不能仅凭 5 ms 响应参数判断高速乒乓球一定能被捕获。

## 3. 首样测试接法

1. 传感器使用 10–30 V DC 中的受控电源，先记录空载电流和正常遮挡电流。
2. 棕线 `BN(1)` 接电源正端，蓝线 `BU(3)` 接 0 V，黑线 `BK(2)` 通过符合额定值的负载、光耦或晶体管电平转换进入逻辑分析仪/ESP32；不得把 10–30 V 输出直接接 GPIO。
3. 示波器/逻辑分析仪至少同时记录两点：
   - `CH-A`：传感器黑线在负载侧的 NPN 波形；
   - `CH-B`：电平转换后的主控侧波形。
4. 用带参考光电二极管/编码器的电磁快门、细缝转盘或其他能产生已知遮挡宽度的机构，先产生 1–10 ms 的遮挡脉冲；随后再用真实乒乓球做速度和轨迹复测。
5. 首轮只接一对发射/接收器，完成时间测试后再扩展到 10 个通道；最低、中间和最高通道也要抽测，排除主体安装、线缆让位和光学高度差异。

## 4. 遮挡脉冲矩阵

每个脉宽至少重复 30 次，并分别测试“遮挡”和“恢复光束”两个方向。记录触发参考边沿、NPN 输出变化完成时间、主控侧边沿、输出脉宽、是否漏检和是否有多脉冲。

| 目标遮挡宽度 | 重复次数 | 检出次数 | 漏检次数 | NPN 输出脉宽 | 上升/下降延迟 | 证据 |
| ---: | ---: | ---: | ---: | ---: | ---: | --- |
| 1 ms | 30 |  |  |  |  |  |
| 2 ms | 30 |  |  |  |  |  |
| 3 ms | 30 |  |  |  |  |  |
| 4 ms | 30 |  |  |  |  |  |
| 5 ms | 30 |  |  |  |  |  |
| 6 ms | 30 |  |  |  |  |  |
| 8 ms | 30 |  |  |  |  |  |
| 10 ms | 30 |  |  |  |  |  |

建议把“`30/30` 检出且无额外脉冲”作为首样可靠性门；最终门槛要根据目标球速下实测的最短 `t_block` 再加机械/速度裕量冻结。若 1–5 ms 区间无法稳定检出，应改用更快的传感器或重新定义检测事件，不能靠软件延长一个不存在的脉冲。

## 5. 真实球验证

在已知遮挡脉冲测试之后，使用目标球和实际过网方向记录：球速、相机/编码器参考、光束高度、球心是否穿越光束、`t_block`、NPN 波形和主控事件。至少覆盖中心穿越、边缘穿越、斜向穿越和不同高度通道。

只有当目标场景中最短实测 `t_block` 在全部重复试验中稳定产生对应输出，才允许关闭当前“球体遮挡宽度/高速漏检”待确认项，并将 B-06 的 M6 通道验收从 `待实机` 推进到下一阶段。

## 6. 证据文件建议

```text
<run>-M6-01-sensor-side-1ms.csv
<run>-M6-02-sensor-side-2ms.csv
<run>-M6-05-sensor-side-5ms.csv
<run>-M6-10-sensor-side-10ms.csv
<run>-M6-ball-speed-and-block.csv
<run>-M6-waveform.jpg
<run>-M6-channel-map.json
```

原始波形必须保留，不能只记录“检测到/未检测到”；现场总记录仍使用 [`field-validation-record-template.zh-CN.md`](field-validation-record-template.zh-CN.md)。

## 7. CSV 分析器

仓库提供 [`tools/analyze_m6_response.py`](../tools/analyze_m6_response.py)，只依赖 Python 标准库。逻辑分析仪导出为以下最小格式后，可以直接生成每次试验的边沿配对、输入/输出脉宽、延迟、漏检和汇总检测率：

```csv
trial_id,time_us,reference,sensor_npn
1,0,0,0
1,1000,1,0
1,6000,1,1
1,8000,0,1
1,9000,0,0
```

运行：

```text
python3 tools/analyze_m6_response.py \
  --input evidence/<run>-M6-waveform.csv \
  --output evidence/<run>-M6-response.json
```

如果还要分析电平转换后的主控侧信号，把列名替换为 `mcu` 并加 `--output-column mcu`。分析器会把未配对的参考边沿记录为漏检，不会用零延迟或软件窗口把它改成通过；配套单元测试为 `python3 tools/test_analyze_m6_response.py`。

收到真实 CSV 前，可用 `python3 tools/test_m6_response_workflow.py` 做一次纯合成的 30 次端到端回归（CSV → 边沿分析 → 批次门）；该测试只验证工具链，不产生实物验收证据。

收到器件后，可先运行 `python3 tools/init_m6_acceptance_run.py --output-dir evidence/<run-id>` 创建不覆盖旧目录的验收骨架；它只生成 `pending` 模板和 CSV 表头，不会伪造任何实物证据。

如果输入的是示波器上的原始 NPN 低有效电平，必须显式加 `--invert-output`：

```text
python3 tools/analyze_m6_response.py \
  --input evidence/<run>-M6-waveform.csv \
  --output evidence/<run>-M6-response.json \
  --invert-output
```

分析器现在要求参考边沿与输出边沿方向一致；未声明极性或方向相反的边沿会被计为漏检/额外边沿，不会静默通过。

对同一个目标遮挡宽度完成至少 30 次后，再用批次门检查“每次都检出且没有额外边沿”：

```text
python3 tools/validate_m6_response_batch.py \
  evidence/<run>-M6-response.json \
  --target-width-us 5000 \
  --min-trials 30 \
  --max-latency-us 20000
```

`--target-width-us` 只是这批快门/遮挡机构的目标输入宽度；它不是传感器的最小遮挡门槛。要关闭高速漏检风险，必须分别对 `1/2/3/4/5/6/8/10 ms` 批次运行并结合真实球的最短 `t_block` 判断。

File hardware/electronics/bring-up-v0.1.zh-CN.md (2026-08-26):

# 传感器板 Bring-up 顺序 v0.1

本文是第一次接入 ESP32-S3、PVDF AFE 和 10 路 M6 直角对射 NPN 前端时的操作顺序。它不冻结 PCB 引脚、电压、阈值或器件型号；任何一步未通过，都不能把健康快照标记为有效，也不能生成有效高度/擦网结论。

## 0. 上电前

记录 PCB、固件 commit、`net_sensor_config.h` 版本、校准规版本、`net_stand.scad` 版本和球台台面厚度。断电测量 3.3 V 与 GND 是否短路，确认 ESP32-S3、AFE、发射端和接收端的地线共地；确认 GPIO 1/2 的 AFE 输出不超过最终 ADC 衰减允许范围。首轮占位 GPIO 不能直接视为最终 PCB 引脚。

证据：`<run>-P00-power.csv`、`<run>-P00-board.jpg`、万用表/示波器型号和读数。

## 1. GPIO 电平与时间戳

先不接球网和光学发射器，只接逻辑测试源：

1. 对 `PVDF_TRIGGER[0..1]` 分别施加低/高电平，确认只有上升沿进入对应通道，记录 `esp_timer_get_time()` 时间戳。
2. 对经过负载/光耦/电平转换后的 `M6_BEAM_BLOCKED[0..9]` 逐路施加未遮挡/遮挡电平；若使用 SmartPaddle 参考板，应先在独立载板的 `CARRIER_IN[0..9]` 验证双边沿时间戳、SPI CRC/序号和 FIFO 状态，再确认主控映射到 `M6_BEAM_BLOCKED`。确认逻辑极性按最终 NPN 常开/常闭后缀配置，且每一位与物理高度顺序一致；不得把传感器 10–30 V 输出直接接 ESP32-S3 GPIO。
3. 同时制造两路边沿，确认 GPIO ISR 只入队，不在 ISR 中执行 JSON 或波形分析。

首样隔离前端参考电阻、光耦选择条件、测试点和电源保护见 [`m6-npn-interface-v0.1.zh-CN.md`](m6-npn-interface-v0.1.zh-CN.md)；先用单路验证，再复制到十路。

证据：逻辑分析仪 CSV、串口日志、通道映射表。时间戳乱序或队列溢出时，下一事件必须是 `unknown`。

## 2. M6 NPN 光电逐路自检

保持内置式球网支架、M6 梳齿条和三轴基座固定：

1. 按供应商接线图给发射/接收器件提供 10–30 V，棕线接 +V、蓝线接 0 V；接收端黑线只进入已验证的负载/光耦/电平转换，正常对准时记录每路 NPN 基线和主控侧电平。
2. 关闭/断开发射端，确认 `emitter_ok=false` 或对应通道失败。
3. 横向偏移接收端，确认 `receiver_ok=false` 或对应通道失败。
4. 用不透光挡片逐根遮挡 `+10…+100 mm` 光束，确认每次只有目标 bit 置位；同时记录 NPN 输出电平、负载电流和主控侧逻辑。
5. 让网体持续遮挡，确认与球遮挡不同的健康/边界记录，不把持续遮挡伪造成球高。

把每路结果转换为 `BeamChannelCheck`，调用 `evaluate_beam_self_test()`；只有通过的 bit 才写入 `healthy_beam_mask`。记录 M6 电源、NPN 负载电流、环境光、通道串扰和参考线读数。

商家确认的 5 ms 只表示状态变化到 NPN 输出完成变化的响应时间，不是必须持续遮挡 5 ms 才能检测，也不是小于 5 ms 必定有输出。首样应按 [`docs/m6-response-time-validation-v0.1.zh-CN.md`](../../docs/m6-response-time-validation-v0.1.zh-CN.md) 用已知 1–10 ms 遮挡脉冲同时记录传感器侧和主控侧波形；在最小输入脉宽和输出脉宽未实测前，不得通过高速球体检测验收。

证据：`<run>-B08-channel-<n>.json`、逻辑分析仪 CSV、标定规照片、环境光记录。

## 3. PVDF AFE 与 ADC

在不碰球网的情况下记录每路安静基线，至少覆盖配置的预触发窗口；计算峰值和 RMS，并使用 `piezo_baseline_is_quiet()` 判定。随后依次施加轻触、真实擦网、旋钮操作和夹具碰撞，保存 ADC 原始波形，不先凭单次峰值冻结阈值。

确认：

- ADC1 两路有效采样率为每路 16 kHz；
- 触发前 20 ms、触发后 80 ms 的帧边界正确；
- AFE 最大输出未削顶到危险电压；
- 比较器触发时间与 ADC 波形引用能通过 `waveform_ref` 关联；
- 中途停止 ADC 时得到 `complete=false`，事件带 `waveform_incomplete`。

证据：`<run>-S01-left.csv`、`<run>-S01-right.csv`、`<run>-S01-events.jsonl`、阈值/滤波配置。

## 4. 健康快照与业务放行

SmartPaddle 适配层实现 `smartgear_board_read_sensor_health()` 后，先提交以下组合：

| 组合 | 预期 |
| --- | --- |
| 空校准 ID + `calibration_valid=true` | 快照非法，事件 `unknown` |
| `healthy_beam_mask` 含 bit 10 或更高 | 快照非法，事件 `unknown` |
| 光栅部分失败 | 仅失败 bit 命中时事件 `unknown` |
| PVDF 基线未通过 | 含擦网候选的事件 `unknown` |
| 全部健康且校准 ID 有效 | 才允许 `clean_over`/`touch_over` |

传输 hook 未接入或发送失败不改变业务事件内容；事件进入 RAM 缓存，恢复连接后按原事件 ID 顺序补发。

## 5. 现场放行条件

只有当本文件第 0～4 节证据齐全，并完成 [`docs/field-validation-record-template.zh-CN.md`](../../docs/field-validation-record-template.zh-CN.md) 中的 M/B/S/T/E 项，才允许把“待接板”改成“实机通过”。在此之前，ESP32-S3 成功编译只证明固件可链接，不证明传感器电气或机械性能。

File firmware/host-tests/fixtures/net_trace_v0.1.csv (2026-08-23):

# timestamp_us | kind | channel | value
# Clean over: one optical beam is blocked and then released.
10000 | beam | 2 | 1
11000 | beam | 2 | 0
16001 | tick | 0 | 0
261002 | tick | 0 | 0
# Touch over: PVDF candidate followed by a beam event.
300000 | touch | 0 | 1
305000 | beam | 1 | 1
306000 | beam | 1 | 0
311001 | tick | 0 | 0
# Touch without crossing the optical window.
500000 | touch | 1 | 1
640001 | tick | 0 | 0

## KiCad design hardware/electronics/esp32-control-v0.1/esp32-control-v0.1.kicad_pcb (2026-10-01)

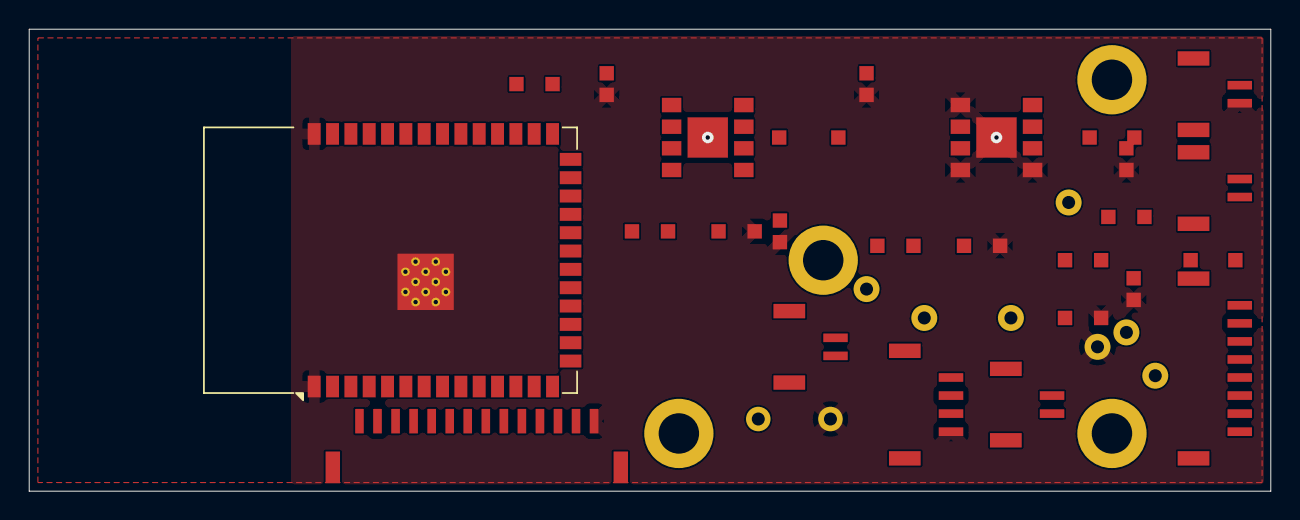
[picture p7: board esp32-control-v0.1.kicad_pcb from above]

Board: 2 copper layers, 86.0 x 32.0 mm, 38 parts (0 on the bottom side), 34 nets, no tracks yet.

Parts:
C1: 100n BAT_SENSE
C2: 22u BAT
C3: 10u VBUS
C4: 22u SYS5V
C5: 10u 3V3
C6: 100n BUCK_EN
D1: GREEN STATUS
D2: TVS 33V SENSOR
F1: PTC 1.1A
F2: PTC SENSOR
H1, H2, H3, H4: M2.5 NPTH
J2: MX1.25_PROTECTED_1S_BAT
J3: MX1.25_SENSOR_10-30V_IN
J4: MX1.25_M6_CARRIER_HOST
J5: MX1.25_PVDF_ADC_AUX
J6: MX1.25_PVDF_CMP_AUX_DNP
J7: MX1.25_UI_PANEL_LOCK_14P_CHARGE
J8: MX1.25_M6_SENSOR_RAIL_LINK
L1: 2.2uH BOOST XFL4020
L2: 2.2uH BUCK XFL3012
R5: 1M BAT_TOP
R6: 1M BAT_BOTTOM
R7: 100k BUCK_EN
R8: 1k CHARGE_LED
SW1: IP5305 KEY
TP1, TP2, TP3, TP4, TP5, TP6, TP7: TEST_POINT
U1: ESP32-S3-WROOM-1-N16R8; ESP32-S3-WROOM-1
U2: IP5305T-HSOP8-1EP
U3: TPS62162-QFN8-EP

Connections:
3v3: C5.1, J4.1, J7.1, L2.2, TP4.1, U1.2, U3.6
bat_p: C2.1, J2.1, R5.1, TP1.1, U2.6
bat_sense: C1.1, R5.2, R6.1, TP2.1, U1.17
boost_sw: L1.1, U2.7
buck_en: C6.1, R7.2, U3.3
buck_sw: L2.1, U3.7
carrier_cs_n: J4.6, U1.21
carrier_irq_n: J4.7, TP6.1, U1.22
carrier_miso: J4.5, U1.20
carrier_mosi: J4.4, U1.19
carrier_reset_n: J4.8, U1.5
carrier_sck: J4.3, U1.18
gnd: C1.2, C2.2, C3.2, C4.2, C5.2, C6.2, D1.2, J2.2, J4.2, J5.2, J5.4, J7.2, J7.14, R6.2, SW1.2, TP5.1, U1.1, U1.40, U1.41, U2.9, U3.1, U3.4, U3.5, U3.9
led_charge: R8.1, U2.2
power_key: SW1.1, U2.5
pvdf_adc_l: J5.1, U1.39
pvdf_adc_r: J5.3, U1.38
sensor_ext: F2.1, J3.1
sensor_fused: D2.1, F2.2, J8.1, TP7.1
sensor_gnd: D2.2, J3.2, J8.2
status_led: D1.1, R8.2
sys_5v: C4.1, L1.2, R7.1, TP3.1, U2.8, U3.2
ui_btn_mode: J7.6, U1.4
ui_btn_start: J7.5, U1.16
ui_buzzer: J7.7, U1.13
ui_led_battery: J7.12, U1.23
ui_led_status: J7.11, U1.12
ui_scl: J7.4, U1.9
ui_sda: J7.3, U1.10
ui_spk_bclk: J7.8, U1.7
ui_spk_dout: J7.10, U1.11
ui_spk_ws: J7.9, U1.8
usb_vbus: F1.1, J7.13
vbus_limited: C3.1, F1.2, U2.1

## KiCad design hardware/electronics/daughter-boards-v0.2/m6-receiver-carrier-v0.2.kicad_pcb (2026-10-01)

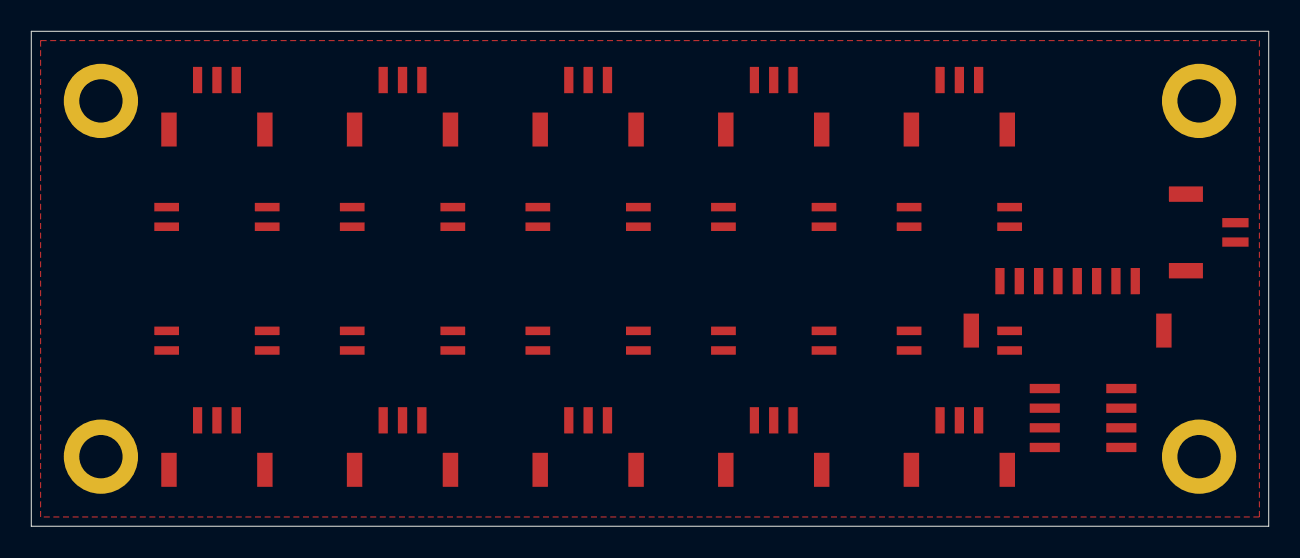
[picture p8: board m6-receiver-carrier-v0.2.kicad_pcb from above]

Board: 2 copper layers, 80.0 x 32.0 mm, 27 parts (0 on the bottom side), 28 nets, no tracks yet.

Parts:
H1, H2, H3, H4: M2.5 NPTH
J_HOST: MX1.25_MOTHER_HOST_LOCK_8P
J_PWR: MX1.25_SENSOR_RAIL_LOCK_2P
J_RX00, J_RX01, J_RX02, J_RX03, J_RX04, J_RX05, J_RX06, J_RX07, J_RX08, J_RX09: MX1.25_LOCK_3P_RX
U_MCU: STM32G031_PLACEHOLDER
U_OP00, U_OP01, U_OP02, U_OP03, U_OP04, U_OP05, U_OP06, U_OP07, U_OP08, U_OP09: OPTO_PLACEHOLDER

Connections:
3v3: J_HOST.1, U_MCU.7, U_OP00.3, U_OP01.3, U_OP02.3, U_OP03.3, U_OP04.3, U_OP05.3, U_OP06.3, U_OP07.3, U_OP08.3, U_OP09.3
carrier_cs_n: J_HOST.6, U_MCU.4
carrier_irq_n: J_HOST.7, U_MCU.5
carrier_miso: J_HOST.5, U_MCU.3
carrier_mosi: J_HOST.4, U_MCU.2
carrier_reset_n: J_HOST.8, U_MCU.6
carrier_sck: J_HOST.3, U_MCU.1
gnd: J_HOST.2, U_MCU.8, U_OP00.4, U_OP01.4, U_OP02.4, U_OP03.4, U_OP04.4, U_OP05.4, U_OP06.4, U_OP07.4, U_OP08.4, U_OP09.4
rx00_gnd: J_RX00.2, U_OP00.2
rx00_sig: J_RX00.3, U_OP00.1
rx01_gnd: J_RX01.2, U_OP01.2
rx01_sig: J_RX01.3, U_OP01.1
rx02_gnd: J_RX02.2, U_OP02.2
rx02_sig: J_RX02.3, U_OP02.1
rx03_gnd: J_RX03.2, U_OP03.2
rx03_sig: J_RX03.3, U_OP03.1
rx04_gnd: J_RX04.2, U_OP04.2
rx04_sig: J_RX04.3, U_OP04.1
rx05_gnd: J_RX05.2, U_OP05.2
rx05_sig: J_RX05.3, U_OP05.1
rx06_gnd: J_RX06.2, U_OP06.2
rx06_sig: J_RX06.3, U_OP06.1
rx07_gnd: J_RX07.2, U_OP07.2
rx07_sig: J_RX07.3, U_OP07.1
rx08_gnd: J_RX08.2, U_OP08.2
rx08_sig: J_RX08.3, U_OP08.1
rx09_gnd: J_RX09.2, U_OP09.2
rx09_sig: J_RX09.3, U_OP09.1

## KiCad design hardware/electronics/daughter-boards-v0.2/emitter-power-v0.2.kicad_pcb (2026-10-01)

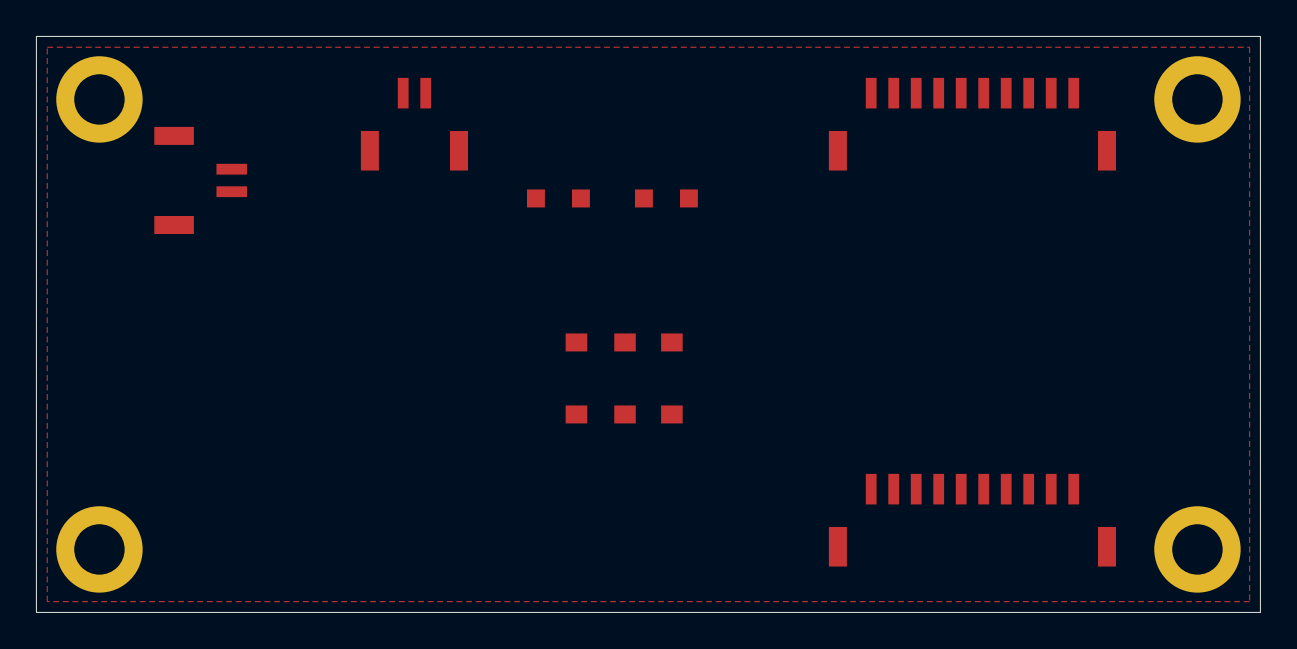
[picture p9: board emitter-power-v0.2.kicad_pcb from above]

Board: 2 copper layers, 68.0 x 32.0 mm, 11 parts (0 on the bottom side), 5 nets, no tracks yet.

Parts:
D_TVS: TVS_BY_MODULE
F_TX: PTC_OR_FUSE
H1, H2, H3, H4: M2.5 NPTH
J_BAT: MX1.25_PROTECTED_1S_LOCK_2P
J_EXT: MX1.25_EXT_TX_10-30V_2P_CURRENT_GATE
J_TX_A: MX1.25_TX_A_10P
J_TX_B: MX1.25_TX_B_10P
U_BOOST: TX_BOOST_CURRENT_RATED_PLACEHOLDER

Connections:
bat_gnd: J_BAT.2, U_BOOST.2
bat_p: J_BAT.1, U_BOOST.1
ext_tx_gnd: D_TVS.2, J_EXT.2
ext_tx_in: F_TX.1, J_EXT.1
tx_rail: D_TVS.1, F_TX.2, U_BOOST.3

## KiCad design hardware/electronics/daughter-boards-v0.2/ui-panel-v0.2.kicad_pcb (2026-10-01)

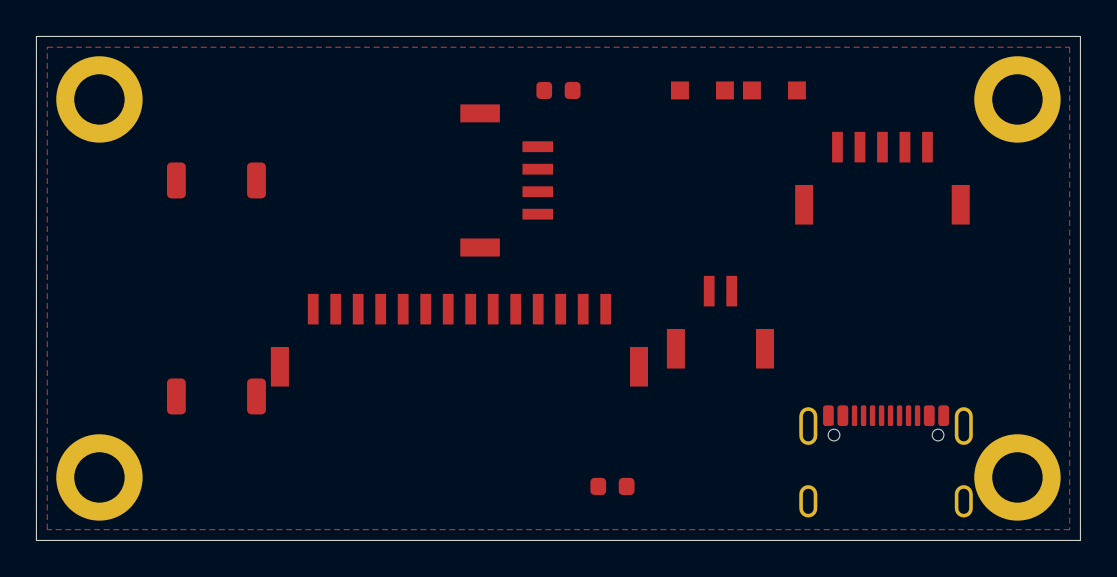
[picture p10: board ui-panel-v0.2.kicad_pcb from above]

Board: 2 copper layers, 58.0 x 28.0 mm, 15 parts (0 on the bottom side), 15 nets, no tracks yet.

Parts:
D_BAT: LED_BATTERY_0603_YELLOW; LED_0603_1608Metric
D_STATUS: LED_STATUS_0603_GREEN; LED_0603_1608Metric
H1, H2, H3, H4: M2.5 NPTH
J_BUZ: MX1.25_BUZZER_LOCK_2P
J_MOTHER: MX1.25_MOTHER_UI_LOCK_14P_CHARGE
J_OLED: MX1.25_I2C_OLED_FPC_4P
J_SPK: MX1.25_I2S_SPEAKER_LOCK_5P
J_USB_PANEL: USB-C_VERTICAL_CHARGE_ONLY; USB_C_Receptacle_GCT_USB4105-xx-A_16P_TopMnt_Horizontal
R_CC1: 5k1 USB-C CC1 Rd
R_CC2: 5k1 USB-C CC2 Rd
SW_MODE: SEALED_SMD_TACTILE_MODE; SW_SPST_TS-1088-xR020
SW_START: SEALED_SMD_TACTILE_START; SW_SPST_TS-1088-xR020

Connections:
3v3: J_MOTHER.1, J_OLED.1, J_SPK.4
cc1: J_USB_PANEL.A5, R_CC1.1
cc2: J_USB_PANEL.B5, R_CC2.1
gnd: D_BAT.2, D_STATUS.2, J_BUZ.2, J_MOTHER.2, J_MOTHER.14, J_OLED.2, J_SPK.5, J_USB_PANEL.A1, J_USB_PANEL.A12, J_USB_PANEL.B1, J_USB_PANEL.B12, J_USB_PANEL.SH, R_CC1.2, R_CC2.2, SW_MODE.2, SW_START.2
ui_btn_mode: J_MOTHER.6, SW_MODE.1
ui_btn_start: J_MOTHER.5, SW_START.1
ui_buzzer: J_BUZ.1, J_MOTHER.7
ui_led_battery: D_BAT.1, J_MOTHER.12
ui_led_status: D_STATUS.1, J_MOTHER.11
ui_scl: J_MOTHER.4, J_OLED.4
ui_sda: J_MOTHER.3, J_OLED.3
ui_spk_bclk: J_MOTHER.8, J_SPK.1
ui_spk_dout: J_MOTHER.10, J_SPK.3
ui_spk_ws: J_MOTHER.9, J_SPK.2
usb_vbus: J_MOTHER.13, J_USB_PANEL.A4, J_USB_PANEL.A9, J_USB_PANEL.B4, J_USB_PANEL.B9

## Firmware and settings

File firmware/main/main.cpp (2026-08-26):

#include "beam_capture.h"
#include "beam_channel_map.h"
#include "feedback.h"
#include "feedback_gpio.h"
#include "m6_carrier_adapter.h"
#include "m6_carrier_config.h"
#include "net_event_aggregator.h"
#include "net_event_delivery.h"
#include "net_event_transport.h"
#include "net_sensor_config.h"
#include "piezo_capture.h"
#include "piezo_adc_continuous.h"
#include "piezo_waveform.h"
#include "piezo_waveform_archive.h"
#include "piezo_waveform_hook.h"
#include "sensor_board_hooks.h"
#include "sensor_health_gate.h"
#include "sensor_self_test.h"

#ifdef ESP_PLATFORM

#include <array>
#include <cstdio>
#include <string>
#include <utility>

#include "driver/gpio.h"
#include "m6_carrier_spi.h"
#include "esp_err.h"
#include "esp_log.h"
#include "esp_timer.h"
#include "freertos/FreeRTOS.h"
#include "freertos/queue.h"
#include "freertos/task.h"

namespace {

constexpr char kTag[] = "smartgear";

enum class SensorKind : std::uint8_t {
    kBeam,
    kPiezo,
};

struct SensorRoute {
    SensorKind kind;
    std::uint8_t channel;
    gpio_num_t pin;
};

struct SensorEdge {
    SensorKind kind;
    std::uint8_t channel;
    int level;
    std::uint64_t timestamp_us;
};

QueueHandle_t s_sensor_queue = nullptr;
portMUX_TYPE s_sensor_queue_overflow_mux = portMUX_INITIALIZER_UNLOCKED;
volatile bool s_sensor_queue_overflow = false;
std::array<SensorRoute, smartgear::config::kBeamCount +
                            smartgear::config::kPiezoCount>
    s_routes{};

constexpr bool carrier_candidate_is_disjoint_from_direct_io() {
    for (const int carrier_pin :
         smartgear::carrier_config::kSmartPaddleCarrierGpioPins) {
        for (const int beam_pin : smartgear::config::kBeamGpioPins) {
            if (carrier_pin == beam_pin) {
                return false;
            }
        }
        for (const int piezo_pin :
             smartgear::config::kPiezoComparatorGpioPins) {
            if (carrier_pin == piezo_pin) {
                return false;
            }
        }
        for (const int adc_pin : smartgear::config::kPiezoAdcGpioPins) {
            if (carrier_pin == adc_pin) {
                return false;
            }
        }
        for (const int feedback_pin : smartgear::config::kFeedbackGpioPins) {
            if (carrier_pin == feedback_pin) {
                return false;
            }
        }
    }
    return true;
}

static_assert(!smartgear::carrier_config::kUseM6Carrier ||
                  carrier_candidate_is_disjoint_from_direct_io(),
              "M6 carrier candidate pins conflict with direct sensor or "
              "feedback GPIOs; audit the final board mapping first");

void IRAM_ATTR sensor_isr(void* argument) {
    auto* route = static_cast<SensorRoute*>(argument);
    const SensorEdge edge{
        route->kind,
        route->channel,
        gpio_get_level(route->pin),
        static_cast<std::uint64_t>(esp_timer_get_time()),
    };
    BaseType_t higher_priority_task_woken = pdFALSE;
    if (s_sensor_queue != nullptr) {
        if (xQueueSendFromISR(s_sensor_queue, &edge, &higher_priority_task_woken) !=
            pdTRUE) {
            portENTER_CRITICAL_ISR(&s_sensor_queue_overflow_mux);
            s_sensor_queue_overflow = true;
            portEXIT_CRITICAL_ISR(&s_sensor_queue_overflow_mux);
        }
    }
    if (higher_priority_task_woken == pdTRUE) {
        portYIELD_FROM_ISR();
    }
}

bool consume_sensor_queue_overflow() {
    portENTER_CRITICAL(&s_sensor_queue_overflow_mux);
    const bool overflowed = s_sensor_queue_overflow;
    s_sensor_queue_overflow = false;
    portEXIT_CRITICAL(&s_sensor_queue_overflow_mux);
    return overflowed;
}

void on_piezo_adc_sample(const std::uint8_t channel,
                         const std::int16_t raw_sample,
                         const std::uint64_t timestamp_us,
                         void* context) {
    auto* waveform = static_cast<smartgear::PiezoWaveformCapture*>(context);
    if (waveform != nullptr) {
        waveform->feed_sample(channel, raw_sample, timestamp_us);
    }
}

void configure_sensor_inputs(const bool use_m6_carrier) {
    s_sensor_queue = xQueueCreate(32, sizeof(SensorEdge));
    ESP_ERROR_CHECK(s_sensor_queue != nullptr ? ESP_OK : ESP_ERR_NO_MEM);

    // 既有 SmartPaddle 固件也采用 GPIO comparator + 时间戳模式；这里保留
    // 同一采集边界，后续由业务层消费，不在 ISR 中做事件归并或 JSON 序列化。
    const esp_err_t isr_service_error =
        gpio_install_isr_service(ESP_INTR_FLAG_IRAM);
    ESP_ERROR_CHECK(isr_service_error == ESP_OK ||
                            isr_service_error == ESP_ERR_INVALID_STATE
                        ? ESP_OK
                        : isr_service_error);

    std::size_t route_index = 0;
    if (!use_m6_carrier) {
        for (std::size_t channel = 0; channel < smartgear::config::kBeamCount;
             ++channel, ++route_index) {
            auto& route = s_routes[route_index];
            route = {SensorKind::kBeam,
                     static_cast<std::uint8_t>(channel),
                     static_cast<gpio_num_t>(
                         smartgear::config::kBeamGpioPins[channel])};
            ESP_ERROR_CHECK(gpio_set_direction(route.pin, GPIO_MODE_INPUT));
            ESP_ERROR_CHECK(gpio_set_pull_mode(route.pin, GPIO_PULLUP_ONLY));
            ESP_ERROR_CHECK(gpio_set_intr_type(route.pin, GPIO_INTR_ANYEDGE));
            ESP_ERROR_CHECK(gpio_isr_handler_add(route.pin, sensor_isr, &route));
        }
    }
    for (std::size_t channel = 0; channel < smartgear::config::kPiezoCount;
         ++channel, ++route_index) {
        auto& route = s_routes[route_index];
        route = {SensorKind::kPiezo,
                 static_cast<std::uint8_t>(channel),
                     static_cast<gpio_num_t>(
                         smartgear::config::kPiezoComparatorGpioPins[channel])};
        ESP_ERROR_CHECK(gpio_set_direction(route.pin, GPIO_MODE_INPUT));
        ESP_ERROR_CHECK(gpio_set_pull_mode(route.pin, GPIO_FLOATING));
        ESP_ERROR_CHECK(gpio_set_intr_type(route.pin, GPIO_INTR_POSEDGE));
        ESP_ERROR_CHECK(gpio_isr_handler_add(route.pin, sensor_isr, &route));
    }
}

void log_and_cache_event(const smartgear::NetEvent& event,
                         smartgear::NetEventDelivery& delivery) {
    const std::string json = smartgear::net_event_to_json(event);
    ESP_LOGI(kTag, "%s", json.c_str());
    const auto feedback = smartgear::feedback_for(event.state);
    ESP_LOGI(kTag,
             "feedback=%s led=%d%d%d buzzer=%ums x%u",
             smartgear::feedback_pattern_name(feedback.pattern),
             feedback.led_red,
             feedback.led_green,
             feedback.led_blue,
             feedback.buzzer_on_ms,
             feedback.repeat_count);

    // SmartPaddle WebSocket 的连接回调调用 delivery.set_transport(true, send_fn,
    // context)，断链期间 NetEventDelivery 会保留事件并在恢复时按序补发。
    delivery.publish(event);
}

bool send_board_event(const char* json, void* /*context*/) {
    return smartgear_board_transport_send_json(json);
}

void sync_transport(smartgear::NetEventDelivery& delivery) {
    const bool connected = smartgear_board_transport_connected();
    if (connected == delivery.connected()) {
        return;
    }
    delivery.set_transport(connected, connected ? send_board_event : nullptr);
}

void sync_sensor_health(smartgear::NetEventAggregator& aggregator) {
    // The raw beam mapping is still a provisional active-low candidate. Do
    // not let a board adapter accidentally authorize height events before the
    // purchased SKU, NPN NO/NC polarity, isolator path and a real channel
    // self-test have frozen that mapping and this firmware is rebuilt.
    if (!smartgear::config::kBeamPolarityConfirmed) {
        smartgear::apply_sensor_health_unavailable(aggregator);
        return;
    }

    char calibration_id[64] = {};
    std::uint16_t healthy_beam_mask = 0;
    bool beam_health_valid = false;
    bool piezo_baseline_valid = false;
    bool calibration_valid = false;
    if (!smartgear_board_read_sensor_health(
            calibration_id, sizeof(calibration_id), &healthy_beam_mask,
            &beam_health_valid, &piezo_baseline_valid, &calibration_valid)) {
        smartgear::apply_sensor_health_unavailable(aggregator);
        return;
    }
    const smartgear::SensorHealthSnapshot snapshot{
        healthy_beam_mask,
        beam_health_valid,
        piezo_baseline_valid,
        calibration_valid,
    };
    smartgear::apply_sensor_health_snapshot(
        aggregator, calibration_id, sizeof(calibration_id), snapshot);
}

}  // namespace

extern "C" void app_main() {
    using namespace smartgear;

    BeamCapture beam_capture(config::kBeamQuietUs, config::kBeamMaxEventUs);
    PiezoCapture piezo_capture(config::kTouchMergeUs,
                               config::kPiezoWaveformTimeoutUs);
    PiezoWaveformCapture waveform_capture({config::kPiezoSampleRateHz,
                                           config::kPiezoPreTriggerMs,
                                           config::kPiezoPostTriggerMs});
    PiezoWaveformArchive waveform_archive(config::kWaveformArchiveCapacity);
    PiezoAdcContinuous adc_continuous;
    NetEventAggregator aggregator({config::kTouchAssociationBeforeUs,
                                   config::kTouchAssociationAfterUs,
                                   config::kTouchOnlyTimeoutUs,
                                   config::kTouchCompletionGraceUs});
    NetEventDelivery delivery;
    M6CarrierBeamAdapter carrier_adapter(
        beam_capture, carrier_config::kCarrierToHostOffsetUs);
#ifdef ESP_PLATFORM
    FeedbackGpio feedback_gpio({
        static_cast<gpio_num_t>(config::kFeedbackLedRedGpio),
        static_cast<gpio_num_t>(config::kFeedbackLedGreenGpio),
        static_cast<gpio_num_t>(config::kFeedbackLedBlueGpio),
        static_cast<gpio_num_t>(config::kFeedbackBuzzerGpio),
    });
    M6CarrierSpiMaster carrier_spi({
        SPI2_HOST,
        static_cast<gpio_num_t>(carrier_config::kSpiSckGpio),
        static_cast<gpio_num_t>(carrier_config::kSpiMosiGpio),
        static_cast<gpio_num_t>(carrier_config::kSpiMisoGpio),
        static_cast<gpio_num_t>(carrier_config::kSpiCsGpio),
        static_cast<gpio_num_t>(carrier_config::kIrqGpio),
        static_cast<gpio_num_t>(carrier_config::kResetGpio),
        carrier_config::kSpiClockHz,
    });
    bool carrier_ready = false;
    M6CarrierClockCalibration carrier_clock_calibration;
    bool carrier_clock_ready = carrier_config::kCarrierClockOffsetConfirmed;
    if (carrier_clock_ready) {
        // This path is reserved for a separately recorded, board-specific
        // calibration constant. The default remains false; runtime samples
        // below are the normal way to establish the offset.
        carrier_adapter.set_clock_offset(
            carrier_config::kCarrierToHostOffsetUs);
    }
#endif

    // 启动自检完成并使用机械参考件确认 10 路 M6 光电通道前，事件统一标记 unknown。
    // 校准成功后由设备状态层调用：
    //   aggregator.set_calibration("cal-<version>", true);
    aggregator.set_calibration("boot-self-test-pending", false);
    aggregator.set_beam_health(0, false);
    aggregator.set_piezo_baseline(false);
    configure_sensor_inputs(carrier_config::kUseM6Carrier);
#ifdef ESP_PLATFORM
    if (carrier_config::kUseM6Carrier) {
        const auto carrier_error = carrier_spi.init();
        if (carrier_error == ESP_OK) {
            carrier_ready = true;
        } else {
            ESP_LOGW(kTag, "M6 carrier SPI init deferred: %s",
                     esp_err_to_name(carrier_error));
        }
    }
#endif
    sync_transport(delivery);
    sync_sensor_health(aggregator);
#ifdef ESP_PLATFORM
    const auto feedback_error = feedback_gpio.init();
    if (feedback_error != ESP_OK) {
        ESP_LOGW(kTag, "feedback GPIO init deferred: %s",
                 esp_err_to_name(feedback_error));
    }
#endif
    const auto adc_error = adc_continuous.init(
        {config::kPiezoAdcGpioPins, config::kPiezoSampleRateHz, 256, 2048},
        on_piezo_adc_sample,
        &waveform_capture);
    if (adc_error == ESP_OK) {
        ESP_ERROR_CHECK(adc_continuous.start());
    } else {
        ESP_LOGW(kTag, "ADC1 continuous init deferred: %s", esp_err_to_name(adc_error));
    }
    ESP_LOGI(kTag, "ESP32-S3 net sensor business layer started");

    SensorEdge edge{};
    std::uint64_t next_health_poll_us = 0;
    std::uint64_t next_clock_sync_poll_us = 0;
    while (true) {
        const std::uint64_t now_us =
            static_cast<std::uint64_t>(esp_timer_get_time());
        if (consume_sensor_queue_overflow()) {
            // Dropped edges invalidate the current boundaries. Discard every
            // edge that was already queued before the overflow as well;
            // otherwise stale pre-overflow edges could be combined with fresh
            // input into a plausible but false event. The aggregator retains
            // the overflow marker so the next emitted boundary is unknown.
            xQueueReset(s_sensor_queue);
            beam_capture.reset();
            piezo_capture.reset();
            waveform_capture.abort();
            aggregator.mark_input_overflow();
            ESP_LOGW(kTag, "sensor GPIO queue overflow; next event is unknown");
        }
#ifdef ESP_PLATFORM
        if (carrier_ready) {
            if (now_us >= next_clock_sync_poll_us) {
                const bool was_clock_ready = carrier_clock_ready;
                M6CarrierClockSyncSample sample{};
                bool sample_available = false;
                SmartgearM6CarrierClockSyncReading reading;
                if (smartgear_board_read_m6_carrier_clock_sync(&reading) &&
                    reading.exchange_verified) {
                    sample = {
                        reading.host_sent_us,
                        reading.host_received_us,
                        reading.carrier_received_us,
                        reading.carrier_sent_us,
                    };
                    sample_available = true;
                }
                if (!sample_available &&
                    carrier_config::kUseCarrierSpiClockSync) {
                    sample_available =
                        carrier_spi.exchange_clock_sync(&sample) == ESP_OK;
                }
                if (sample_available) {
                    const bool accepted =
                        carrier_clock_calibration.add_sample(sample);
                    const bool confirmed =
                        accepted && carrier_clock_calibration.confirm();
                    const auto offset = confirmed
                                             ? carrier_clock_calibration
                                                   .confirmed_offset_us()
                                             : std::nullopt;
                    if (offset.has_value()) {
                        carrier_adapter.set_clock_offset(*offset);
                        carrier_clock_ready = true;
                        ESP_LOGI(
                            kTag,
                            "M6 carrier clock confirmed: offset=%lldus samples=%u best_rtt=%lluus spread=%lluus drift=%lluus",
                            static_cast<long long>(*offset),
                            static_cast<unsigned>(
                                carrier_clock_calibration.sample_count()),
                            static_cast<unsigned long long>(
                                carrier_clock_calibration.best_round_trip_us()),
                            static_cast<unsigned long long>(
                                carrier_clock_calibration.offset_spread_us()),
                            static_cast<unsigned long long>(
                                carrier_clock_calibration
                                    .inter_sample_drift_us()));
                    } else {
                        carrier_clock_ready = false;
                    }
                }
                if (was_clock_ready && !carrier_clock_ready) {
                    carrier_adapter.reset_sequence();
                    beam_capture.reset();
                    aggregator.mark_input_overflow();
                    ESP_LOGW(kTag,
                             "M6 carrier clock calibration lost; events remain unknown");
                }
                next_clock_sync_poll_us = now_us + 1'000'000ULL;
            }
            M6CarrierFrame carrier_frame{};
            const auto carrier_result = carrier_spi.poll(&carrier_frame);
            if (carrier_result == M6CarrierSpiPollResult::kFrame) {
                if (!carrier_clock_ready) {
                    // A carrier timestamp cannot be compared with esp_timer
                    // until the runtime estimator has confirmed a real sync
                    // exchange. Keep collecting neither a plausible event
                    // nor a stale BeamCapture boundary in that state.
                    carrier_adapter.reset_sequence();
                    beam_capture.reset();
                    aggregator.mark_input_overflow();
                } else {
                    const auto adapted = carrier_adapter.ingest(carrier_frame);
                    if (!adapted.input_boundary_valid) {
                        carrier_adapter.reset_sequence();
                        aggregator.mark_input_overflow();
                    } else {
                        for (std::size_t index = 0;
                             index < adapted.observation_count; ++index) {
                            aggregator.on_beam(remap_configured_beam_observation(
                                adapted.observations[index]));
                        }
                    }
                }
            } else if (carrier_result == M6CarrierSpiPollResult::kBoundaryError ||
                       carrier_result == M6CarrierSpiPollResult::kSpiError) {
                carrier_adapter.reset_sequence();
                beam_capture.reset();
                aggregator.mark_input_overflow();
            }
        }
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
int main() { return 0; }

#endif

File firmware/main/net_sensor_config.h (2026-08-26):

#pragma once

#include <array>
#include <cstddef>
#include <cstdint>

namespace smartgear::config {

constexpr std::size_t kBeamCount = 10;
constexpr std::size_t kPiezoCount = 2;
constexpr std::uint16_t kAllBeamMask = static_cast<std::uint16_t>(
    (1U << kBeamCount) - 1U);

// 首轮占位引脚映射。最终值必须和 PCB、SmartPaddle 既有约束及启动脚复核后冻结。
constexpr std::array<int, kBeamCount> kBeamGpioPins = {
    4, 5, 6, 7, 8, 9, 10, 11, 12, 13};
constexpr std::array<int, kPiezoCount> kPiezoComparatorGpioPins = {14, 15};
constexpr std::array<int, kPiezoCount> kPiezoAdcGpioPins = {1, 2};
constexpr int kFeedbackLedRedGpio = 16;
constexpr int kFeedbackLedGreenGpio = 17;
constexpr int kFeedbackLedBlueGpio = 18;
constexpr int kFeedbackBuzzerGpio = 19;
constexpr std::array<int, 4> kFeedbackGpioPins = {
    kFeedbackLedRedGpio,
    kFeedbackLedGreenGpio,
    kFeedbackLedBlueGpio,
    kFeedbackBuzzerGpio,
};

template <std::size_t Size>
constexpr bool all_gpio_numbers_valid(const std::array<int, Size>& pins) {
    for (const int pin : pins) {
        // ESP32-S3 exposes GPIO numbers 0..48. This is only a range check;
        // strapping, USB and board-specific reservations still belong to the
        // final PCB review.
        if (pin < 0 || pin > 48) {
            return false;
        }
    }
    return true;
}

template <std::size_t Size>
constexpr bool all_unique(const std::array<int, Size>& pins) {
    for (std::size_t left = 0; left < Size; ++left) {
        for (std::size_t right = left + 1; right < Size; ++right) {
            if (pins[left] == pins[right]) {
                return false;
            }
        }
    }
    return true;
}

template <std::size_t LeftSize, std::size_t RightSize>
constexpr bool disjoint(const std::array<int, LeftSize>& left,
                        const std::array<int, RightSize>& right) {
    for (const int left_pin : left) {
        for (const int right_pin : right) {
            if (left_pin == right_pin) {
                return false;
            }
        }
    }
    return true;
}

static_assert(all_gpio_numbers_valid(kBeamGpioPins),
              "beam GPIO mapping contains an invalid ESP32-S3 GPIO number");
static_assert(all_gpio_numbers_valid(kPiezoComparatorGpioPins),
              "PVDF comparator mapping contains an invalid GPIO number");
static_assert(all_gpio_numbers_valid(kPiezoAdcGpioPins),
              "PVDF ADC mapping contains an invalid GPIO number");
static_assert(all_gpio_numbers_valid(kFeedbackGpioPins),
              "feedback mapping contains an invalid GPIO number");
static_assert(all_unique(kBeamGpioPins), "beam GPIO mapping contains duplicates");
static_assert(all_unique(kPiezoComparatorGpioPins),
              "PVDF comparator mapping contains duplicates");
static_assert(all_unique(kPiezoAdcGpioPins),
              "PVDF ADC mapping contains duplicates");
static_assert(all_unique(kFeedbackGpioPins),
              "feedback mapping contains duplicates");
static_assert(disjoint(kBeamGpioPins, kPiezoComparatorGpioPins) &&
                  disjoint(kBeamGpioPins, kPiezoAdcGpioPins) &&
                  disjoint(kBeamGpioPins, kFeedbackGpioPins) &&
                  disjoint(kPiezoComparatorGpioPins, kPiezoAdcGpioPins) &&
                  disjoint(kPiezoComparatorGpioPins, kFeedbackGpioPins) &&
                  disjoint(kPiezoAdcGpioPins, kFeedbackGpioPins),
              "sensor and feedback GPIO mappings must be disjoint");

// Physical MCU input bit -> logical height index.  The acceptance channel map
// records this same relationship as output_bit for each +10..+100 mm row.  It
// is identity for the provisional harness; if the delivered cable/PCB order
// differs, change this permutation after evidence is captured and rebuild.
constexpr std::array<std::uint8_t, kBeamCount> kBeamLogicalIndexByInput = {
    0, 1, 2, 3, 4, 5, 6, 7, 8, 9};

template <std::size_t Size>
constexpr bool is_permutation_0_to_n_minus_1(
    const std::array<std::uint8_t, Size>& values) {
    for (std::size_t left = 0; left < Size; ++left) {
        if (values[left] >= Size) {
            return false;
        }
        for (std::size_t right = left + 1; right < Size; ++right) {
            if (values[left] == values[right]) {
                return false;
            }
        }
    }
    return true;
}

static_assert(is_permutation_0_to_n_minus_1(kBeamLogicalIndexByInput),
              "beam input-to-height mapping must be a 0..9 permutation");

// M6 传感器的最终常开/常闭后缀和隔离前端极性仍待卖家/实物确认。
// 先把当前参考拓扑的“遮挡为低”保存为可审计的候选配置，但在证据
// 到位并重新编译前，main.cpp 不允许健康快照授权有效高度事件。
enum class BeamInputPolarity : std::uint8_t {
    kBlockedLow,
    kBlockedHigh,
};

constexpr BeamInputPolarity kBeamInputPolarity =
    BeamInputPolarity::kBlockedLow;
constexpr bool kBeamPolarityConfirmed = false;

constexpr int beam_blocked_level_for(const BeamInputPolarity polarity) {
    return polarity == BeamInputPolarity::kBlockedLow ? 0 : 1;
}
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

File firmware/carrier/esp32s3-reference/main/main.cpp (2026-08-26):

#include "m6_carrier_capture_core.h"
#include "m6_carrier_spi_slave_transport.h"

#include <array>
#include <cstdint>

#include "driver/gpio.h"
#include "driver/spi_slave.h"
#include "esp_err.h"
#include "esp_log.h"
#include "esp_timer.h"
#include "freertos/FreeRTOS.h"
#include "freertos/task.h"

namespace {

constexpr char kTag[] = "m6-carrier-s3-ref";

// Reference-only mapping for a second ESP32-S3 carrier board. It is not the
// SmartPaddle host mapping and must not be copied into the host firmware.
constexpr std::array<gpio_num_t, 10> kInputPins = {
    GPIO_NUM_4,  GPIO_NUM_5,  GPIO_NUM_6,  GPIO_NUM_7,  GPIO_NUM_8,
    GPIO_NUM_9,  GPIO_NUM_10, GPIO_NUM_11, GPIO_NUM_12, GPIO_NUM_13,
};
constexpr gpio_num_t kSpiSck = GPIO_NUM_15;
constexpr gpio_num_t kSpiMosi = GPIO_NUM_16;
constexpr gpio_num_t kSpiMiso = GPIO_NUM_17;
constexpr gpio_num_t kSpiCs = GPIO_NUM_18;
constexpr gpio_num_t kIrq = GPIO_NUM_14;
constexpr gpio_num_t kReset = GPIO_NUM_21;

struct InputRoute {
    gpio_num_t pin;
    std::uint8_t channel;
};

smartgear::carrier::M6CarrierCaptureCore g_capture;
smartgear::carrier::M6CarrierSpiSlaveTransport g_transport(g_capture);
std::array<InputRoute, kInputPins.size()> g_routes{};

void IRAM_ATTR carrier_input_isr(void* argument) {
    const auto* route = static_cast<const InputRoute*>(argument);
    if (route == nullptr) {
        return;
    }
    const auto timestamp_us = static_cast<std::uint64_t>(esp_timer_get_time());
    const auto level = static_cast<std::uint8_t>(gpio_get_level(route->pin));
    // The platform-neutral core contains no allocation, logging or filtering;
    // the ISR records the raw edge and lets the SPI task package it later.
    (void)g_capture.on_edge(route->channel, level, timestamp_us);
}

void configure_inputs() {
    gpio_config_t input_config{};
    input_config.pin_bit_mask = 0;
    for (const gpio_num_t pin : kInputPins) {
        input_config.pin_bit_mask |= UINT64_C(1) << static_cast<unsigned>(pin);
    }
    input_config.mode = GPIO_MODE_INPUT;
    input_config.pull_up_en = GPIO_PULLUP_DISABLE;
    input_config.pull_down_en = GPIO_PULLDOWN_DISABLE;
    input_config.intr_type = GPIO_INTR_ANYEDGE;
    ESP_ERROR_CHECK(gpio_config(&input_config));

    for (std::size_t index = 0; index < kInputPins.size(); ++index) {
        g_routes[index] = {
            kInputPins[index], static_cast<std::uint8_t>(index)};
        ESP_ERROR_CHECK(gpio_isr_handler_add(
            kInputPins[index], carrier_input_isr, &g_routes[index]));
    }
}

void configure_control_pins() {
    gpio_config_t irq_config{};
    irq_config.pin_bit_mask = UINT64_C(1) << static_cast<unsigned>(kIrq);
    irq_config.mode = GPIO_MODE_OUTPUT;
    irq_config.pull_up_en = GPIO_PULLUP_DISABLE;
    irq_config.pull_down_en = GPIO_PULLDOWN_DISABLE;
    irq_config.intr_type = GPIO_INTR_DISABLE;
    ESP_ERROR_CHECK(gpio_config(&irq_config));
    ESP_ERROR_CHECK(gpio_set_level(kIrq, 1));

    gpio_config_t reset_config{};
    reset_config.pin_bit_mask = UINT64_C(1) << static_cast<unsigned>(kReset);
    reset_config.mode = GPIO_MODE_INPUT;
    reset_config.pull_up_en = GPIO_PULLUP_ENABLE;
    reset_config.pull_down_en = GPIO_PULLDOWN_DISABLE;
    reset_config.intr_type = GPIO_INTR_DISABLE;
    ESP_ERROR_CHECK(gpio_config(&reset_config));
}

void configure_spi_slave() {
    spi_bus_config_t bus_config{};
    bus_config.mosi_io_num = kSpiMosi;
    bus_config.miso_io_num = kSpiMiso;
    bus_config.sclk_io_num = kSpiSck;
    bus_config.quadwp_io_num = -1;
    bus_config.quadhd_io_num = -1;
    bus_config.max_transfer_sz =
        static_cast<int>(smartgear::kM6CarrierMaxFrameBytes);

    spi_slave_interface_config_t slave_config{};
    slave_config.mode = 0;
    slave_config.spics_io_num = kSpiCs;
    slave_config.queue_size = 1;

    ESP_ERROR_CHECK(spi_slave_initialize(
        SPI2_HOST, &bus_config, &slave_config, SPI_DMA_CH_AUTO));
}

void spi_service_loop() {
    std::array<std::uint8_t, smartgear::kM6CarrierMaxFrameBytes> rx_buffer{};

    while (true) {
        if (gpio_get_level(kReset) == 0) {
            g_transport.reset();
            ESP_ERROR_CHECK(gpio_set_level(kIrq, 1));
            vTaskDelay(pdMS_TO_TICKS(2));
            continue;
        }

        if (!g_transport.frame_ready() &&
            !g_transport.clock_sync_response_pending()) {
            (void)g_transport.service();
        }
        ESP_ERROR_CHECK(gpio_set_level(kIrq,
                                       g_transport.irq_asserted() ? 0 : 1));

        if (g_transport.transaction_active()) {
            vTaskDelay(pdMS_TO_TICKS(1));
            continue;
        }

        // An event response is started only after IRQ is asserted. When no
        // event is pending, the same fixed-size peripheral transaction waits
        // for a host clock-sync request. A valid request makes the transport
        // assert IRQ for the following response transaction.
        bool started = false;
        if (g_transport.frame_ready()) {
            started = g_transport.begin_transaction();
        } else if (g_transport.clock_sync_response_pending()) {
            started = g_transport.begin_clock_sync_response(
                static_cast<std::uint64_t>(esp_timer_get_time()));
        } else {
            started = g_transport.begin_clock_sync_request();
        }
        if (!started) {
            g_capture.mark_transport_fault();
            vTaskDelay(pdMS_TO_TICKS(1));
            continue;
        }
        const bool clock_sync_request =
            g_transport.clock_sync_request_active();
        rx_buffer.fill(0U);
        spi_slave_transaction_t transaction{};
        transaction.length =
            smartgear::kM6CarrierMaxFrameBytes * sizeof(std::uint8_t) * 8U;
        transaction.tx_buffer = g_transport.tx_buffer();
        transaction.rx_buffer = rx_buffer.data();
        const esp_err_t result =
            spi_slave_transmit(SPI2_HOST, &transaction, portMAX_DELAY);
        const std::size_t transferred_bytes =
            result == ESP_OK ? transaction.trans_len / 8U : 0U;
        if (clock_sync_request) {
            (void)g_transport.end_clock_sync_request(
                transferred_bytes, rx_buffer.data(), rx_buffer.size(),
                static_cast<std::uint64_t>(esp_timer_get_time()));
        } else {
            (void)g_transport.end_transaction(transferred_bytes);
        }
        ESP_ERROR_CHECK(gpio_set_level(kIrq,
                                       g_transport.irq_asserted() ? 0 : 1));
        if (result != ESP_OK) {
            ESP_LOGW(kTag, "SPI slave transaction failed: %s",
                     esp_err_to_name(result));
        }
    }
}

}  // namespace
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

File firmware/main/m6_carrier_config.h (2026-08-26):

#pragma once

#include <array>
#include <cstddef>
#include <cstdint>

namespace smartgear::carrier_config {

// Candidate only: this mapping is for the SmartPaddle ESP32-S3-WROOM-1
// reference board. It becomes a production mapping only after the final PCB
// and boot log are checked.
constexpr int kSpiSckGpio = 10;
constexpr int kSpiMosiGpio = 11;
constexpr int kSpiMisoGpio = 12;
constexpr int kSpiCsGpio = 13;
constexpr int kIrqGpio = 14;
constexpr int kResetGpio = 5;

// Keep the production path disabled until the carrier PCB, reset/IRQ
// waveform, NPN polarity and a measured host<->carrier clock sync are all
// signed off. This is deliberately a build-time gate: a stale candidate pin
// map must not steal the direct GPIOs or create plausible timestamps.
constexpr bool kUseM6Carrier = false;
constexpr int kSpiClockHz = 1'000'000;
// The carrier protocol now has a real two-transaction sync request/response.
// Set this false only when a custom board supplies the four timestamps through
// smartgear_board_read_m6_carrier_clock_sync() instead.
constexpr bool kUseCarrierSpiClockSync = true;
// Optional fallback for a separately recorded calibration constant. The
// normal path keeps this false and confirms a runtime four-timestamp exchange
// through smartgear_board_read_m6_carrier_clock_sync().
constexpr bool kCarrierClockOffsetConfirmed = false;
constexpr std::int64_t kCarrierToHostOffsetUs = 0;

constexpr std::array<int, 6> kSmartPaddleCarrierGpioPins = {
    kSpiSckGpio,
    kSpiMosiGpio,
    kSpiMisoGpio,
    kSpiCsGpio,
    kIrqGpio,
    kResetGpio,
};

constexpr bool all_unique(const std::array<int, 6>& pins) {
    for (std::size_t left = 0; left < pins.size(); ++left) {
        for (std::size_t right = left + 1; right < pins.size(); ++right) {
            if (pins[left] == pins[right]) {
                return false;
            }
        }
    }
    return true;
}

constexpr bool all_valid(const std::array<int, 6>& pins) {
    for (const int pin : pins) {
        if (pin < 0 || pin > 48) {
            return false;
        }
    }
    return true;
}

static_assert(all_unique(kSmartPaddleCarrierGpioPins),
              "carrier SPI/control GPIOs must be unique");
static_assert(all_valid(kSmartPaddleCarrierGpioPins),
              "carrier candidate GPIO is outside ESP32-S3 range");

}  // namespace smartgear::carrier_config

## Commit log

2026-08-23 🏓 新增乒乓智配实施计划
2026-08-23 🏓 实现网顶擦网与过网高度设备首版
    [net_post_x_clamp.scad]
2026-08-23 🏓 完善网顶波形特征与事件闭环
2026-08-23 🏓 增加波形归档与传感器健康门
2026-08-23 🏓 修正擦网事件延迟关联时序
2026-08-23 🏓 强化 X 夹具运动与几何校验
    [net_post_x_clamp.scad]
2026-08-23 🏓 补齐端到端验证与故障保护
    [net_post_x_clamp.scad]
2026-08-23 🏓 补齐传感器接口与现场回放验证
    [net_trace_v0.1.csv]
2026-08-23 🏓 收紧事件契约与传感器故障保护
    [net_post_x_clamp.scad]
2026-08-23 🏓 增加自动化回放与接板验证
2026-08-23 🏓 修复跨平台类型兼容验证
2026-08-23 🏓 补齐边界保护与硬件接入验证
    [net_post_x_clamp.scad]
2026-08-23 🏓 完善自检与断链缓存测试
2026-08-23 🏓 收紧事件契约与 ESP32 配置验证
2026-08-23 🏓 校验 ADC 帧边界
2026-08-23 🏓 加固 X 夹具 V 槽搭接
    [net_post_x_clamp.scad]
2026-08-23 🧰 固化 CAD M8×1.25 螺杆约束
    [net_post_x_clamp.scad]
2026-08-23 👁️ 增加 OpenSCAD 实体渲染校验
2026-08-23 🖥️ 修复无头 OpenSCAD 渲染
2026-08-24 🧾 校正装配渲染的实体边界
2026-08-24 📐 收紧高度区间契约
2026-08-24 🧊 防止冷启动伪造预触发证据
2026-08-24 🛡️ 收紧健康边界与坏帧收口
2026-08-24 🧱 分离 X 臂错层与光轴间隙
    [net_post_x_clamp.scad]
2026-08-24 📏 收紧 V 槽余量参数校验
    [net_post_x_clamp.scad]
2026-08-24 🧠 补齐 DMA 预触发回填
2026-08-24 🧹 清空溢出队列旧边沿
2026-08-24 🛡️ 拒绝过期采样与反向边界
2026-08-24 ⚡ 先处理触发再派发波形
2026-08-24 🧪 覆盖触发先行波形归并
2026-08-24 🧰 修正夹具打印孔位语义
    [net_post_x_clamp.scad]
2026-08-24 🕒 收紧波形时间窗证据
2026-08-24 🧱 加入夹具三角加强肋
    [net_post_x_clamp.scad]
2026-08-24 🧹 清理溢出边界候选
2026-08-24 📐 固化位图高度契约
2026-08-24 🧪 遍历全部位图契约
2026-08-24 🩺 组装传感器健康快照
2026-08-24 🧰 固化健康门与光学导出
    [net_post_x_clamp.scad]
2026-08-24 🛡️ 收紧健康快照形状
2026-08-24 📝 收口乱序波形边界
2026-08-24 🛡️ 防止健康快照跨事件污染
2026-08-24 📐 修正端座定位与光学净距
    [net_post_x_clamp.scad]
2026-08-24 🧾 固化现场证据校验门
2026-08-24 🧭 记录健康状态时序边界
2026-08-24 👁️ 扩展关键零件可视校验
2026-08-24 🧰 收紧现场校验类型
2026-08-24 🧩 拆分夹具可打印零件
    [net_post_x_clamp.scad]
2026-08-24 🪞 收紧单件镜像契约
    [net_post_x_clamp.scad]
2026-08-24 🧵 补齐参考线端座结构
    [net_post_x_clamp.scad]
2026-08-24 👁️ 纳入 V 槽可视校验
2026-08-24 🛡️ 完善滚柱压盖与螺母捕获
    [net_post_x_clamp.scad]
2026-08-24 ⏱️ 收紧跨事件时间边界
2026-08-24 🧭 拒绝跨事件迟到触发
2026-08-24 🧭 分离异步传感器时间边界
2026-08-24 🧪 收紧 PVDF 预触发时间边界
2026-08-24 🧪 覆盖传输补发中途失败
2026-08-24 🧹 收紧回放边界与硬件目录说明
2026-08-24 🧭 固化预触发样本时序边界
2026-08-24 🧾 映射验证矩阵证据
2026-08-24 🧪 补齐外部回放时间戳关联
2026-08-24 👁️ 补充光学镜像渲染校验
2026-08-24 🏓 切换内置式球网支架方案
    [net_post_x_clamp.scad, net_stand.scad]
2026-08-24 🛠️ 固化免打孔桌下夹持
    [net_stand.scad]
2026-08-24 📏 补齐支架刻度与传感器连接
    [net_stand.scad]
2026-08-24 🧩 补齐内置支架打印与装配验证
    [net_stand.scad]
2026-08-24 🔧 补齐免打孔支架与光学载台验证
    [net_stand.scad]
2026-08-24 🧱 分离可打印光学导轨与装配预览
    [net_stand.scad]
2026-08-24 🧰 修正旋钮装配并补强免打孔回归
    [net_stand.scad]
2026-08-24 🧲 固化免打孔夹紧螺母路径
    [net_stand.scad]
2026-08-24 🔍 补齐免打孔剖面与端到端回归
    [net_stand.scad]
2026-08-24 🧱 强化可打印 STL 拓扑校验
2026-08-24 🧩 区分装配预览与打印零件
2026-08-24 🔁 继承镜像装配预览拓扑边界
2026-08-24 📦 固化免打孔首样打印导出包
    [net_stand.scad]
2026-08-24 🧪 增加首样打印矩阵回归
2026-08-24 🪞 强化当前支架镜像几何回归
2026-08-24 👁️ 记录当前支架可视核验边界
2026-08-24 🛡️ 补齐上夹板可替换保护垫
    [net_stand.scad]
2026-08-24 🧪 让远端复核首样打印包
2026-08-24 🔩 固化 M8×1.25 夹持接口
    [net_stand.scad]
2026-08-24 🧱 固化无孔一体支架与全宽光栅边界
    [net_stand.scad]
2026-08-24 📌 固化参考线定位销贯穿孔
    [net_stand.scad]
2026-08-24 🧹 防止旧 STL 混入打印包
2026-08-24 🧰 补齐首样采购与装配边界
2026-08-24 🔩 修正免打孔夹紧旋钮驱动
    [net_stand.scad]
2026-08-24 🖼️ 对齐轻量预览与主模型
2026-08-24 🧹 清除无波形占位引用
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2026-08-24 🧰 修正工程打印清单与预览交互
    [net_stand.scad]
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2026-08-25 🔧 完成光栅采购适配与装配拼盘预览
    [net_stand.scad]
2026-08-26 🔩 收敛 M6 主体首样与十路传感器结构
    [net_stand.scad]
2026-08-26 📐 冻结 M6 壳体桥接结构实施计划
2026-08-26 🔧 落地 M6 x向分体壳与 M8 桥接结构
    [net_stand.scad]
2026-08-26 🛡️ 加大前盖并将M8承力改为铝合金T尾座
    [net_stand.scad]
2026-08-26 📦 完善M6一体T尾座组件导出与验证
    [net_stand.scad]
2026-08-26 🧩 改为PETG矩形主体并接采购万向夹
    [net_stand.scad]
2026-08-26 🧭 将球头接口移至壳体后端面
    [net_stand.scad]
2026-08-27 🔩 球头下接口连接网夹与前后盖拆装
    [net_stand.scad]
2026-08-27 🔗 明确连接器直连网架立柱
    [net_stand.scad]
2026-08-27 🧱 加固夹体并加长球台丝杆
    [net_stand.scad]
2026-08-27 🛠️ 加厚夹臂并实心化夹体
    [net_stand.scad]
2026-08-27 🖐️ 增加防滑圆角锯齿旋钮
    [net_stand.scad]
2026-08-27 🧭 统一球头螺纹接口与承力路径
    [net_stand.scad]
2026-08-27 🧱 强化后盖承力与M8直连结构
    [net_stand.scad]
2026-08-27 📏 加长夹持舌头并放大压紧盘
    [net_stand.scad]
2026-09-01 🧩 用黄绿腿脚生成 C 夹让位候选
    [net_stand.scad]
2026-09-02 🧩 按最新 SKP 完善 C 夹腿脚干涉候选
    [net_stand.scad]
2026-09-02 🔩 修正加长螺杆末端旋钮结构
    [net_stand.scad]
2026-09-09 🔧 完善双端光学头套与激光微调并优化三维预览
    [laser_micro_mount.scad, net_stand.scad, receiver_mount.scad]
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2026-09-17 🔩 完善桌面夹顶装夹与新版打印包
    [net_stand.scad]
2026-09-17 🔧 完善机械电子模型与验证资料
    [bom.csv, emitter-power-v0.2.kicad_pcb, emitter-power-v0.2.kicad_sch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]
2026-09-18 🧰 修正网夹补打印包与默认导出路径
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2026-09-18 🔧 正式化C方案打印件与预览
    [net_stand.scad]
2026-09-19 🧩 完成分型夹体与电子仓电池分层修复
    [net_stand.scad]
2026-09-19 🔩 补强 C 夹左下角分型螺丝
    [net_stand.scad]
2026-09-19 🔧 下移 C 夹下排第三螺丝
    [net_stand.scad]
2026-09-19 🔩 将 C 夹下排第三螺丝落到底部
    [net_stand.scad]
2026-09-19 🧵 重做 C 夹 PETG 粗牙螺杆
    [net_stand.scad]
2026-09-19 🧵 加宽打印螺纹牙槽比例
    [net_stand.scad]
2026-09-19 🔩 改用锥形粗牙螺纹
    [net_stand.scad]
2026-09-19 🔧 修复CAD干涉并完善电子腔体预览
    [net_stand.scad]
2026-09-20 ✨ 完善面板接口对齐与打印预览
    [bom.csv, emitter-power-v0.2.kicad_pcb, emitter-power-v0.2.kicad_sch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]
2026-09-22 🔧 下移6、7号连接位并更新CAD打印包
    [board-outline.scad, bom.csv, electronics_components.scad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]
2026-09-24 🔌 更新 USB-C 扩径套与电子腔体验证
    [net_stand.scad]
2026-09-24 🧩 统一 UI 一体固定板并清理旧打印件
    [net_stand.scad]
2026-09-24 🔩 修正圆柱网杆并同步立柱连接规格
    [net_stand.scad]
2026-09-25 🔧 修复电池导轨与分型boss连接
    [net_stand.scad]
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2026-09-30 🔧 完善激光尾部粗牙防脱帽与扳手受力面
    [laser_micro_mount.scad, net_stand.scad]
2026-09-30 🧹 清理旧版构件并统一当前 CAD 预览
    [net_stand.scad]
2026-10-01 🔌 统一 Type-C 充电入口
    [bom.csv, esp32-control-v0.1.kicad_pcb, esp32-control-v0.1.kicad_sch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]
2026-10-01 🔧 修正 ESP32 原生封装与焊盘装配
    [esp32-control-v0.1.kicad_pcb]
2026-10-01 🔌 修复线束契约与电子机械干涉
    [bom.csv, emitter-power-v0.2.kicad_pcb, emitter-power-v0.2.kicad_sch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]
2026-10-02 🧹 清理线束实体并更新装配校验
    [laser_micro_mount.scad, net_stand.scad, receiver_mount.scad]
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2026-10-18 🔧 保存围挡限位卡 v1.10 全宽斜坡及依赖模型
2026-10-18 🔧 放宽围挡限位卡 v1.11 的 XY 与 Z 装配余量
2026-10-18 📦 添加围挡卡两件 X1C PETG 拼板配方与切片审计
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2026-10-24 feat(cad): reinforce barrier clip v1.15 and archive six-part PETG print
